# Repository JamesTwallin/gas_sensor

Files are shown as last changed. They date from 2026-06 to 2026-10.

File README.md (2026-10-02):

# Atmospheric methane detector

A pocket-sized gas detector you carry on a walk to find methane leaks.

- A small circuit board holds two gas sensors, one for methane and one for LP
  gas (propane and butane).
- The board sends its readings to an app on your phone over Bluetooth.
- The app shows you when the gas level suddenly rises, and saves the readings
  together with your GPS position.
- Afterwards, scripts in this repository turn a recording into a map.

This is a home-built, citizen-science project. It is not a certified safety
device. It shows *where* gas rises; it does not tell you how much gas there is.

<p align="center">
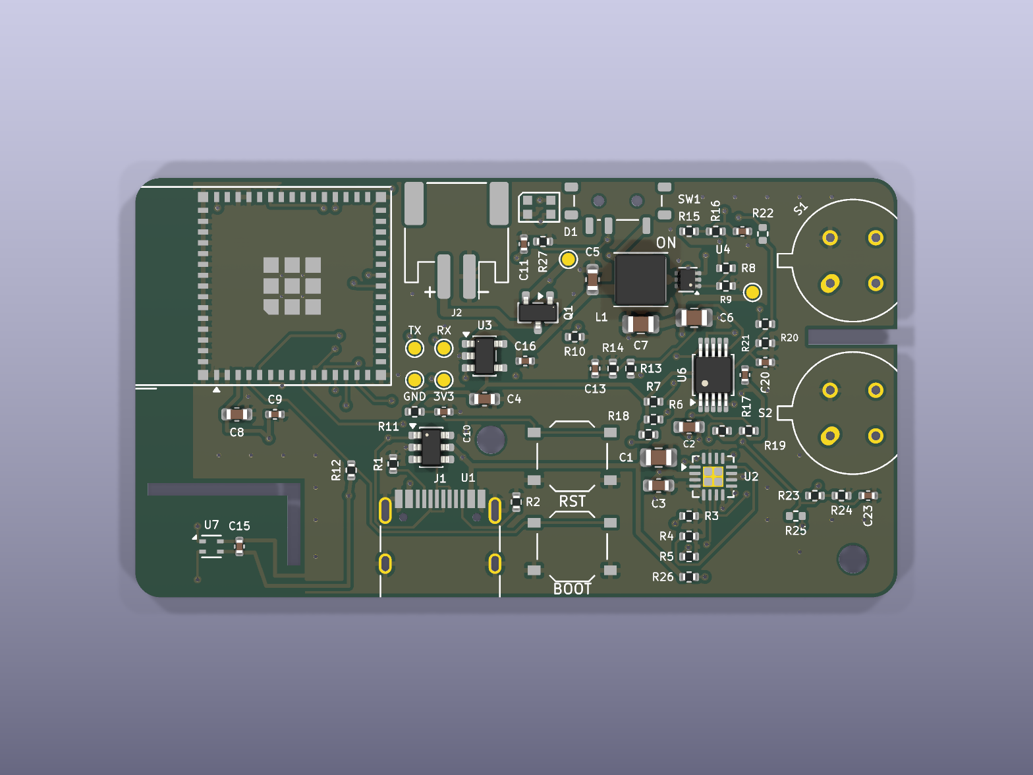
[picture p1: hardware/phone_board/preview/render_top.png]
Picture of the circuit board. The two round sensor positions are on the right-hand edge.
  
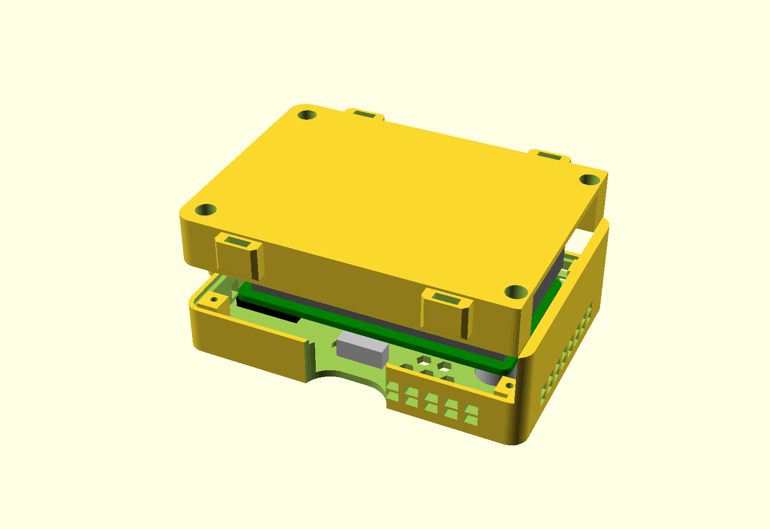
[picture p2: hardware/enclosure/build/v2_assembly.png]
Picture of the 3D-printed case with the board and battery inside.
  
</p>

## Which version to build

**Build rev C.** It is the current design.

| Version | What it is | Status |
|---|---|---|
| **Rev C** | The current board, 60 × 33 mm. Files are in [hardware/phone_board](hardware/phone_board/). | **Build this one.** This exact board has not been manufactured yet. |
| Rev B | The same circuit on a slightly bigger board (66 × 36 mm). | Built and tested in September 2026. Replaced by rev C. Its files are saved under the git tag [`rev-b`](https://github.com/JamesTwallin/gas_sensor/tree/rev-b/hardware/phone_board). |
| Rev D | An experiment with cheaper sensors. In [hardware/phone_board_mems](hardware/phone_board_mems/). | A draft. Nothing has been built. |
| Rev A | The first prototype, which had its own screen, GPS and memory card. In [legacy/rev_a](legacy/rev_a/). | Retired. |

Rev C and rev B are the same circuit. Rev C is just smaller, with the parts
moved around. So the software and the app work on both, and the tests done on
rev B still count. Running from the battery has not been properly tested yet.

## What you need

| Item | Where to get it | Notes |
|---|---|---|
| The circuit board | Order from [JLCPCB](https://jlcpcb.com/) using the files in [hardware/phone_board/production](hardware/phone_board/production/). | It arrives with almost every part already soldered on. The [board guide](hardware/phone_board/README.md) lists which options to pick when ordering. |
| Methane sensor: Figaro **TGS2611-E00** | [RS Components, stock no. 134-6647](https://uk.rs-online.com/web/p/environmental-sensor-ics/1346647) | You solder this on yourself. It has four legs. |
| LP-gas sensor: Figaro **TGS2610-D00** | RS Components, stock no. 134-6641 (search for it on your country's RS site) | You solder this on yourself too. |
| Battery | [The Pi Hut: 2000mAh 3.7V LiPo Battery, JST-PH connector](https://thepihut.com/products/2000mah-3-7v-lipo-battery), about £10 | **Check the red and black wires before plugging it in**, see below. Any single-cell 3.7 V LiPo battery works if it has a JST-PH plug and built-in protection. |
| USB-C cable | Any | For charging the battery and loading the software. |
| Android phone | | For the app. An iPhone works only if you build the app yourself. |
| Case (optional) | 3D-print it from [hardware/enclosure](hardware/enclosure/) | Also needs four M2 × 8 mm and two M2 × 5 mm self-tapping screws. The case fits the rev B board; one for rev C has not been made yet. |

The two sensors together cost roughly $25–30. Not every electronics shop stocks
them, so use the part names above when searching.

**Battery wires.** Batteries with the same plug are not all wired the same way
round. The battery from The Pi Hut came with red and black swapped compared to
what this board expects, and the two metal pins had to be swapped over in the
plug. A battery plugged in the wrong way round does no damage, but the board
will not switch on. The [board guide](hardware/phone_board/README.md#before-you-power-it)
shows which side is positive.

## Putting it together

1. **Order the board** from JLCPCB.
2. **Solder on the two sensors.** Line up the small tab on each sensor with the
   notch printed on the board.
3. **Load the software onto the board.** Install
   [PlatformIO](https://platformio.org/), plug the board into your computer with
   the USB-C cable, switch the board on, and run these from this folder:

   ```
   pio run -d firmware/phone_board                    # build
   pio run -d firmware/phone_board --target upload    # load it onto the board
   ```

   If your computer cannot find the board: hold the **BOOT** button, tap
   **RESET**, let go of **BOOT**, and try again.
4. **Install the app.** On an Android phone, scan this code, or open the
   [direct link](https://expo.dev/artifacts/eas/GfUwoBCFfugQeaA97EXnztzByZKVXR2_-AvwwxxLo4k.apk)
   on the phone. Your phone will ask for permission to install it.

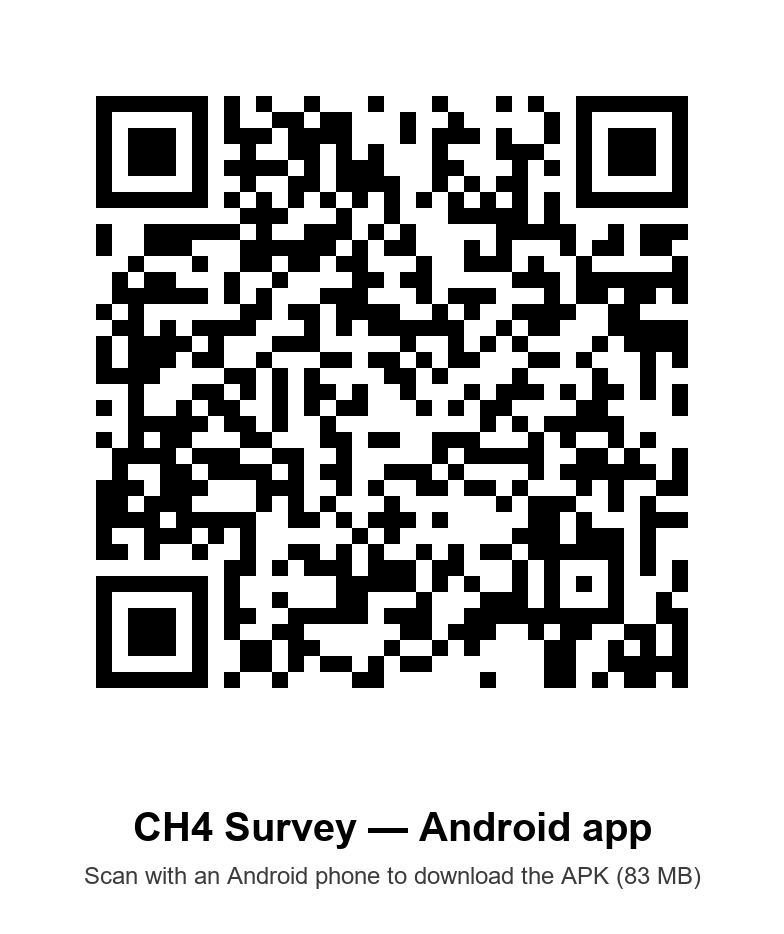
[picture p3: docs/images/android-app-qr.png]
QR code that downloads the Android app
   

   This is the version built on 2 October 2026. The download is stored by Expo
   and will be removed after a while. If the code has stopped working, or you
   have an iPhone, build the app yourself: see the [app guide](app/README.md).
   The app has a pretend sensor built in, so you can try it before you have a
   board.
5. **Plug in the battery**, after checking the wires (above). Plugging in the
   USB-C cable charges it.
6. **Go for a walk.** Switch the board on, open the app, tap **Connect**, pick
   your board from the list, and tap **Record**.

A quick way to check it works: let a little gas out of an unlit cigarette
lighter near the sensors, for a second or two only. The LP-gas reading should
jump. The methane reading will not, because that sensor has a filter that blocks
lighter gas.

## How it finds gas

The sensors do not give a steady number. Their readings drift up and down with
the temperature, the humidity and the wind, even in clean air. So the app does
not look at how high the reading is. It looks at how fast the reading is
*changing*. Walking into a patch of gas makes the reading shoot up within a
second or two, and the app flags that moment.

For the same reason, the gas concentration the app shows (in parts per million)
is only a rough guide.

More detail, for those who want it:

- [docs/phone_board.md](docs/phone_board.md): how the board is designed and
  how it talks to the phone.
- [docs/sensors.md](docs/sensors.md): how the sensors behave, and what can
  fool them.
- [app/README.md](app/README.md): the app.

## Making a map from a recording

The app saves each walk as a spreadsheet-style file (a CSV). Share it from the
app's **Surveys** tab to your computer and put it in the `tools/data/` folder.
Then, with [Python](https://www.python.org/) installed:

```
pip install -r tools/requirements.txt   # once
python tools/plot_map.py                # makes a map for every recording
python tools/plot_survey.py             # makes a video for every recording
```

- [plot_map.py](tools/plot_map.py) draws your route on a satellite photo,
  coloured by the sensor reading. The maps appear in `tools/maps/`.
- [plot_survey.py](tools/plot_survey.py) makes a video of the readings over
  time. The videos appear in `tools/videos/`.

Recordings contain your GPS positions, so `tools/data/` is never uploaded to
GitHub.

## What is in this repository

```
app/              the phone app
firmware/         the software that runs on the board
hardware/
  phone_board/        the rev C board: design files and the files to order it
  phone_board_mems/   the rev D draft
  enclosure/          the 3D-printed case
docs/             how the board and the sensors work
tools/            scripts that turn recordings into maps and videos
legacy/           old versions, kept for reference
```

## Licence

Firmware is MIT (see [LICENSE](LICENSE)). The hardware design will be released
under CERN-OHL-S once it is ready.

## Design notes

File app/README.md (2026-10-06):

# GasSnifferBuddy — companion app

Phone app for the methane detector's phone-companion board, rev B and rev C
([docs/phone_board.md](../docs/phone_board.md)).
The board streams raw samples over BLE; the app turns them into the one thing
that indicates a plume — the slope of each channel's load voltage, with a spike
detector on top — charts it, and adds GPS tagging and CSV recording. Rev A's
HIGH/MED/LOW classifier and its baseline are gone from the screen: the absolute
level wanders too much to mean anything. The rolling baseline is still computed
for the rev A CSV columns only, so the plotting tools keep working.

One codebase: **Expo (SDK 57) + React Native + TypeScript**, built with EAS.

```
app/
  App.tsx          top bar, banners, the three views, action dock
  index.ts         Expo entry point
  app.json         Expo config: permissions, BLE + location plugins
  eas.json         EAS Build profiles (development / preview / production)
  src/core/        pure, DOM-free, unit-tested
    protocol.ts    BLE UUIDs, 20-byte Sample parser, Info JSON, control opcodes
    base64.ts      base64 <-> bytes (react-native-ble-plx speaks base64)
    sensor.ts      VRL = tap × tap_ratio, Rs = RL (VC − VRL) / VRL
    windows.ts     time-based rolling window, rev A percentile
    spike.ts       slope (dVRL/dt) and the adaptive spike threshold
    processor.ts   WARMUP / RUNNING / HEATER_OFF state machine, CSV baseline, LED colour
    csv.ts         exact spec column order, row formatting, file names
    chartData.ts   chart history + peak-per-column decimation
    simulator.ts   simulated board producing protocol-exact packets
    beep.ts        the alarm tone (synthesised WAV)
    settings.ts    defaults (3 min warm-up, 1 s slope window, 25 mV/s spike threshold, beep on)
    mapView.ts     map maths: Web Mercator, which tiles to show, fit-to-track (unit-tested)
    track.ts       the survey track: one point per GPS fix with its readings (unit-tested)
    heatmap.ts     ground cells, colour scale and range for the map (unit-tested)
    surveyCsv.ts   reads a saved survey CSV back into a map track (unit-tested)
  src/controller.ts  the wiring: BLE/simulator -> core -> UI state, GPS, recording
                     (deliberately not src/app/ — Expo treats that as the
                      Expo Router routes directory)
  src/services/    BLE scan + link (auto-reconnect), simulated link, GPS,
                   recorder, keep-awake, spike beeper (expo-audio), settings storage
  src/ui/
    chartPaths.ts  pure chart geometry (unit-tested)
    charts.tsx     react-native-svg rendering of that geometry
    SurveyMap.tsx  the live survey map: satellite tiles + the heatmap
    *Screen.tsx    Live / Surveys / Settings, and Present (full-screen slopes for video)
  tests/           vitest — core + chart geometry
```

Samples arrive at 4 Hz, so `AppController` is a plain class holding the mutable
engines (`Processor`, `ChartBuffer`, `Recorder`); React subscribes to it with
`useSyncExternalStore` and sees an immutable snapshot published at most once per
animation frame.

## Requirements

- **Node 22.13+** (or 20.19.4+ / 24.3+). React Native 0.86 and Metro 0.84 refuse
  anything older — Node 22.11 installs with an `EBADENGINE` warning and then
  fails to start the bundler. EAS Build uses its own Node, so this only affects
  running the dev server locally.
- Android Studio + SDK for `expo run:android` (a Mac + Xcode for `run:ios`)
- **pnpm** — install dependencies with `pnpm install`, not `npm install`.
  `npm install` stalls indefinitely on this dependency tree on Windows: it
  creates the ~320 top-level directories in `node_modules/`, writes zero bytes
  and then sits there with the CPU idle. pnpm installs the same tree in about
  20 seconds. `.npmrc` pins `node-linker=hoisted`, which Metro and the Expo
  config plugins need — they resolve modules by walking `node_modules`, so the
  default symlinked pnpm layout breaks them.
- Optional, only for cloud builds: an [Expo](https://expo.dev) account and
  `npm i -g eas-cli`.

## First-time setup

```sh
cd app
pnpm install
```

## Running it

BLE needs native code, so **Expo Go will not work with a real board** — the app
has to be a native build. The simulator, however, runs anywhere.

```sh
npx expo run:android    # builds the native app, installs it, starts Metro
npx expo start          # afterwards: just the bundler
```

`run:android` runs `prebuild` for you, generating `android/` from `app.json`.
Re-run it when a native dependency or anything in `app.json` changes; the rest of
the time `expo start` is enough. `npx expo prebuild --clean` regenerates the
native projects from scratch if they get into a bad state.

### Without hardware

**Settings → Simulated device**, then Connect. The simulator has buttons to drop
the link (tests auto-reconnect), toggle USB and force the heaters off.
Because it touches no native BLE code it also runs in Expo Go (`npm run start:go`),
which is the quickest way to work on the UI.

### Cloud builds (optional)

If you would rather not build locally — or need an iOS build without a Mac —
`eas.json` has development / preview / production profiles:

```sh
eas login
eas init                      # links this folder to your Expo account
npm run build:dev:android     # eas build --profile development --platform android
```

`eas init` writes `extra.eas.projectId` into `app.json`; commit that change.

`android/` and `ios/` are generated, not tracked: `app.json` is the source of
truth and EAS runs `prebuild` itself.

## Tests and type-checking

```sh
pnpm test         # vitest: src/core + src/ui/chartPaths — 152 tests
pnpm typecheck
```

The tests import only pure modules, so they run in plain node with no React
Native or Expo mocking.

## Permissions

Declared in `app.json` and requested at first Connect / Record:

- **Android** — `BLUETOOTH_SCAN` (`neverForLocation`) and `BLUETOOTH_CONNECT` on
  API 31+, legacy `BLUETOOTH`/`BLUETOOTH_ADMIN` below that, `ACCESS_FINE_LOCATION`
  / `ACCESS_COARSE_LOCATION` for the GPS track (foreground only), and `WAKE_LOCK`.
  The BLE plugin is listed before `expo-location` so scanning does not force a
  location grant, while the location permission itself stays uncapped for the
  GPS track.
- **iOS** — `NSBluetoothAlwaysUsageDescription` (from the BLE plugin),
  `NSBluetoothPeripheralUsageDescription` and `NSLocationWhenInUseUsageDescription`.

There is no OS device chooser: the app scans for boards advertising the service
UUID and shows its own picker.

## Using it in the field

1. Power the board, tap **Connect**, pick `CH4-XXXX` from the list.
2. The big card reads **WARMING UP** for the first 3 minutes after the board
   powers on (skipped if it has been on longer), then shows the **CH4 slope** in
   mV/s and turns red while the slope is over the spike threshold: a rising
   edge means you have just walked into a plume. The phone sounds an alarm
   tone on every flagged sample (Settings → Beep on spikes). No spikes are flagged during warm-up, though the charts run. Each
   channel's card charts the slope over the last 60 s, the raw VRL under it,
   and the peak slope over the last 10 min. Raw readings are charted and
   recorded in every state. The board LED follows (green, red while CH4 is
   spiking).
3. Tap **● Record** to start a survey. Rows are appended to storage every 3 s.
   The **Surveys** tab draws your route as a heatmap on a satellite map as
   you walk, like `tools/plot_map.py` does afterwards. The route is split into
   5 m squares (bigger when zoomed out), each coloured on one gradient from
   dark purple (low) to pale yellow (high), with a colour bar showing the range.
   **Raw** colours each square by the average CH4 VRL there; **Spikes** by the
   steepest CH4 rise there in mV/s, scaled from 0 to the top 1% of squares.
   Tap a square to read its value; tap again to close it. The map fits the
   whole route until you drag or pinch it; the GPS button centres on you and
   follows you as you walk. The top button opens the map full screen; it or
   the back gesture closes it.
   Fixes less accurate than 25 m are left off, so indoors the route may not
   appear. The map images come from Esri World Imagery and need a data connection.
   **Looking at an old survey:** tap **Show on map** on any saved survey in the
   list and the map redraws that survey instead. **Back to live map** returns to
   the current one. **Open a CSV…** loads a survey from somewhere else (Files,
   Google Drive, an email attachment, a colleague's phone): it is copied into
   your survey list and shown. Older SD-card CSVs from the rev A board load too,
   but they have no slope column, so only the **Raw** map shows anything for them.
4. Tap **Present** for presentation mode: just the two slopes, full screen and
   large, for filming or screen-recording. The ✕ (or Android back) leaves it.
5. A red **HEATERS OFF** banner means the firmware's low-battery cutoff tripped:
   readings are invalid until the heaters are back and the sensor has warmed up again.

## Getting CSVs into `tools/data/`

**Surveys** tab → **Share / export** on a file, then send it to your computer
(Drive, email, Nearby Share / AirDrop, …) and save it to `tools/data/`.

Surveys live in `<documents>/surveys/`. On iOS that folder is exposed to the
Files app (**On My iPhone → GasSnifferBuddy → surveys**) via `UIFileSharingEnabled`.
On Android (debug build) you can also pull them over USB:

```sh
adb shell run-as com.inorite.sensorbuddy ls files/surveys
adb exec-out run-as com.inorite.sensorbuddy cat files/surveys/2026-09-17_09-05-07.csv > tools/data/2026-09-17_09-05-07.csv
```

The CSV is the rev A column set followed by `ch4_rs_ohm,lpg_rs_ohm,vbat_mv,gps_accuracy_m`
(see the spec). Note the known gap in the spec: `tools/plot_map.py` currently
filters on `sats`, which the phone leaves blank.

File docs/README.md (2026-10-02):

# docs

Project documentation that does not belong in code:

- [phone_board.md](phone_board.md) — the design spec for the current board
  (rev B / C): why each part is there, power, the gas sensor circuit, the pin
  map, the Bluetooth protocol and the CSV the app writes. This is the source of
  truth for the schematic generator, the firmware and the app.
- [sensors.md](sensors.md) — Figaro TGS2611 / TGS2610 behaviour notes: why
  absolute ppm is only indicative, the humidity confounder, warm-up, field
  cautions.

Elsewhere:

- [../hardware/phone_board/README.md](../hardware/phone_board/README.md) —
  building the rev C board: the generator scripts, ordering, first power-up.
- [../hardware/enclosure/README.md](../hardware/enclosure/README.md) — the
  printed case.
- [../app/README.md](../app/README.md) — the phone app.
- [../legacy/rev_a/schematic.md](../legacy/rev_a/schematic.md) — the connection
  spec for the retired rev A carrier board.

The hardware design will be released under CERN-OHL-S when it is ready; the
firmware is MIT (see the top-level LICENSE).

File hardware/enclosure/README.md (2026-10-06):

# Handheld enclosure

A two-part printed case for the [phone-companion board](../phone_board/): a
front shell the board screws into, and a back tray that holds the battery.

**Which board it fits.** `case_revb_v2.scad` is sized for the 66 × 36 mm rev B
board, the one that has been built. A case for the 60 × 33 mm rev C board has
not been made yet: the board dimensions and part positions are parameters at
the top of the file (see [If you change the board](#if-you-change-the-board)),
and rev C's positions are already measured out in the older
[legacy/enclosure/case_revc.scad](../../legacy/enclosure/case_revc.scad). The
earlier box-and-lid cases are in [legacy/enclosure](../../legacy/enclosure/).

## The design

The board screws into a **front
shell** with the sensors through its face, and a **back tray** carries the
battery in its own pocket and traps it when screwed on.

v2

- **Case is 81 × 57 mm** (was 51 wide). The cell has to pass between the two
  corner posts at the tray's open end on its way into the compartment, and at
  51 mm wide the gap between them was 36 mm for a 38 mm cell. Now 41.6 mm.
- **Front shell** (81 × 57 × 11.4 mm). Sensor collars and cap holes in the
  face, hex grille around them and at the SHT40 end, RST/BOOT pen holes, LED
  window, engraved lettering. Inside, two 7 mm bosses at the board's H1 and H2
  holes: the board goes in component side first and two M2 × 5 screws through
  the board's back pull it onto them. USB-C and the switch sit in notches open
  to the shell's back edge, so both are reachable with the tray off; the tray's
  rim closes them. Louvres at component level on three sides of the sensor end.
  Four corner posts with pilot holes take the tray screws.
- **Back tray** (78.6 × 57 × 11.8 mm plus a 1 mm lip). A closed compartment
  for the Pi Hut 2000 mAh cell, 60 × 38 × 8 mm: floor, side fences, an end
  fence at the SHT40 end and a 1.2 mm divider plate over the top that keeps the
  cell separate from the board. The compartment is open at the sensor end, a
  full-width slot the cell slides into like a drawer; the divider stops 8 mm
  short of that end so the lead can come up through the gap to the board's
  JST. The front shell's sensor-end wall carries a skirt that reaches down over
  the open end, so with the tray screwed on the slot is closed and the cell is
  captive. Four counterbored corner posts, lip into the shell's rebate on the
  other three sides, zip-tie eyelets on the long walls (the tie passes through them front to
  back). No vents in the
  battery compartment.
- **Orientation**: the board lies component side down in the shell. It goes in
  as if turned over about its long axis, so the sensor end stays at the
  lanyard-free end, the switch is on one long edge and USB-C on the other. Seen
  from the front, the two collars are on the left with CH4 the lower one, the
  switch scallop on the bottom edge, and the SHT40 grille top right.
- **Access with the tray on**: matching 20 mm wide, 5 mm deep scallops cut
  through the face and wall at both the switch and the USB-C socket, on top of
  the side notches (14 × 7.4 mm at the USB-C, 15 × 8 mm at the switch), so a
  thumb reaches the lever and a plug goes in from the front edge.
- **Screws**: 4 × M2 × 8 for the tray, 2 × M2 × 5 for the board. The tray's
  counterbores are 9.3 mm deep, leaving 2.5 mm of plastic under each head, so
  an M2 × 8 puts 5.5 mm of thread into the shell's posts (pilots are 7 mm
  deep). A PH0 or PH00 driver reaches the head down the 4.6 mm bore. The tray
  screws pass through the divider plate at the SHT40-end corners.
- **Second print revision (2026-10-01)**: every corner post is now embedded in a
  solid 5.2 mm block joined to the adjacent walls, in both parts. The first
  print's two tray posts at the open end stood alone on the floor and snapped
  off. The battery compartment has 0.6 mm of play around the cell and 1 mm over
  it (was 0.3 and 0.5, too tight printed). The cell stops 0.6 mm short of the
  corner blocks at the open end, which reach 1.8 mm into its width, so the
  block zone is 5.2 mm of room for the lead, which passes between the two
  blocks. Face lettering: CH4, RST, USB by the port scallop, ON / OFF either
  side of the switch scallop (ON is lever toward the sensor end). The BOOT
  button's pen hole is there but unlabelled.
- **Print**: front face down (collars and lettering on the plate), tray outer
  face down. No supports: the divider is a 39 mm bridge between the side
  fences, which PETG on the A1 handles. Files `stl/revb_v2_front.stl`,
  `stl/revb_v2_back.stl`. Overall assembled depth 22.7 mm.
- **Assembly**: fit the sensors' end of the board under the collars and screw
  the board to the bosses. Slide the cell into the tray's open end, lead first
  is easiest, until it meets the end fence. Bring the lead up through the gap
  at the end of the divider, past the end of the board, and plug it into the
  JST. Screw the tray on: the shell's skirt now covers the open end.
- `-D 'part="section"'` cuts the assembled case in half lengthways for a
  clearance check.

## Files

| File | What |
|---|---|
| `case_revb_v2.scad` | the model, parametric: edit this, not the STLs |
| `stl/revb_v2_front.stl` | front shell |
| `stl/revb_v2_back.stl` | back tray |
| `build/v2_assembly.png` | the render above |

Regenerate after editing (OpenSCAD 2021.01+):

```
openscad -o stl/revb_v2_front.stl -D 'part="front"' case_revb_v2.scad
openscad -o stl/revb_v2_back.stl  -D 'part="back"'  case_revb_v2.scad
openscad -o build/v2_assembly.png --imgsize=1600,1100 -D 'part="assembly"' case_revb_v2.scad
```

`part="assembly"` also draws a mock board, sensors and cell, which is the
quickest way to check a change hasn't broken clearances.

## Printing

- **Material: PETG or ASA.** The heaters put ~0.6 W inside a small box and the
  case sits in sunlight on surveys; PLA creeps and can sag. PETG is the easy pick.
- **0.2 mm layers, 3 walls, 20 % infill.** No supports, no brim needed.
- **Orientation:** front shell face down, back tray outer face down.

## Hardware you need

| Qty | Item |
|---|---|
| 4 | M2 × 8 mm self-tapping screws (tray into the shell's corner posts) |
| 2 | M2 × 5 mm self-tapping screws (board to the bosses at H1 and H2) |
| 1 | 1S LiPo, JST-PH, protected: the compartment is sized for the Pi Hut 2000 mAh cell, 60 × 38 × 8 mm (see the [board README](../phone_board/README.md) for polarity) |

## Known compromises

- **Not weatherproof.** The sensors need open air, so the shell is vented.
- **The sensor cans get hot** (~280 mW each). They protrude by design; don't grip
  them, and give the device a minute of settling after handling before trusting
  a reading.
- **SHT40 accuracy:** the tongue on the board and the grille at that end help, but
  temperature inside any case reads slightly high. Compare against a reference
  thermometer before trusting absolute temperature.

## If you change the board

`case_revb_v2.scad` carries the board dimensions and part positions at the top
(all in KiCad board coordinates, origin at the board's top-left corner). Update
them there and re-export. Set `board_t = 1.0` if you order 1 mm boards.

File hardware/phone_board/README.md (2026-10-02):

# Phone-companion board (rev C)

A 60 × 33 mm, 4-layer board: bare ESP32-S3-MINI-1, two bare Figaro TGS sensors,
ADS1115, SHT40 temp/humidity, LiPo charging and a 5 V heater boost. Position, display,
storage and signal processing live on the phone. The electrical spec (why each
part, pin map, BLE protocol) is [docs/phone_board.md](../../docs/phone_board.md).

top

**Status: rev C is the current design, and the one to build.** It is rev B
compacted, with the same schematic and parts; this layout has not been
fabricated yet. Rev B (66 × 36 mm, git tag `rev-b`) was fabricated and assembled
at JLCPCB and passed bring-up on 2026-09-28: it enumerates over native USB,
flashes, and `firmware/phone_board` reports the ADS1115, the SHT40, a 5.02 V
heater rail and both Figaro sensors on USB power. The Bluetooth link to the
phone app was confirmed on the same board. Battery operation is not yet
exercised.

Rev C keeps rev B's schematic and parts, shrinks the board from 66 × 36 to
60 × 33 mm (17 % less area) and gives it a business end:

- **Front (right) edge: the sensors.** Both Figaro cans overhang the edge by
  about 1 mm and a 7 mm notch is milled between them, so each can stands in air
  on three sides and the two heaters share less board.
- **Rear: the power connections, beside the ESP32.** USB-C on the bottom edge
  and the battery JST-PH on the top edge, both right next to the module and
  about 30 mm from the heaters; the reverse-cell FET sits by the JST.
- **SHT40 isolation.** The tongue keeps its L-slot with a 2.5 mm neck, and no
  copper pour is allowed on any of the four layers over the tongue or neck:
  only its four tracks cross, since copper is what carries board heat.
- The hand-routed boost loop and ESP32 decoupling were moved as rigid units;
  everything else was re-placed (charger and ADC in the middle, RESET above
  BOOT, serial test pads as a labelled 2 × 2 grid).

The KiCad checks report 0 DRC violations, 0 unconnected items and 0
schematic/PCB mismatches; ERC is clean.

**USB-only power is marginal at heater turn-on.** With no cell on J2, the
BQ24073's 500 mA USB input limit only just covers the boost converter starting
into two cold heaters: an early firmware that enabled the heaters 3 s after
boot, with BLE advertising and the CPU at 240 MHz, browned out the ESP32 at
that instant on two consecutive boots. The firmware now enables the heaters as
the very first thing in `setup()` at 80 MHz, before any other load, and a cold
start then survives. A LiPo on J2 removes the margin problem, since the cell
holds VSYS up through the inrush. If a future revision is made, raise the
charger's input limit (ILIM mode) or add bulk capacitance on VSYS.

## The design is generated — edit `gen/design.py`, not the KiCad files

`gen/design.py` holds every part, net, LCSC number, placement, pre-routed
track and rule. The scripts turn it into the KiCad project:

| Step | Command | Output |
|---|---|---|
| custom symbols | `python gen/build_lib.py` | `lib/phone_board.kicad_sym` (TPS61023, TGS26xx) |
| schematic | `python gen/build_sch.py` | `phone_board.kicad_sch` (net-label style) |
| board (placed, unrouted) | `"C:\Program Files\KiCad\9.0\bin\python.exe" gen/build_pcb.py` | `phone_board.kicad_pcb`, `.kicad_pro` rules |
| autoroute | `...\python.exe gen/route.py` | routed board, GND pours + stitching vias |
| tidy silkscreen labels | `...\python.exe gen/tidy_silk.py` | moves/hides overlapping reference designators on the routed board |
| JLC placement | `...\python.exe gen/jlc_align.py` (needs `pip install easyeda2kicad`) | `gen/jlc_placement.json` |
| fab files + renders | `python gen/export.py` | `production/`, `preview/` |
| relabel silkscreen only | `...\python.exe gen/build_pcb.py --silk-only` | edits the routed board in place |

Then check: `kicad-cli pcb drc --schematic-parity phone_board.kicad_pcb` and
`kicad-cli sch erc phone_board.kicad_sch`.

**Rebuilding the board throws away the routing.** `build_pcb.py` then needs a
fresh `route.py` run of about 5 minutes. Freerouting doesn't route exactly the
same way twice, so re-run DRC afterwards.

`route.py` needs Freerouting 2.4+ and Java 25+ (a portable JRE is fine):

```
set JAVA=C:\path\to\jdk-25-jre\bin\java.exe
set FREEROUTING=C:\path\to\freerouting-2.4.1.jar
```

How routing works:

- **The boost converter's power loop is routed by hand.** This covers the
  inductor to SW, the output caps, the feedback sense point and the GND vias,
  and it lives in `PREROUTE`. The tracks are locked, so Freerouting routes
  around them.
- **In1 is a solid GND plane.** The script marks it as a power layer, so no
  signals are routed on it.
- **F.Cu, In2 and B.Cu carry signals**, then get GND pours.
- **The script runs Freerouting up to 3 rounds**, then adds GND stitching vias
  and a via for any pour island that has none.

You can also open `phone_board.kicad_pro` in KiCad and edit by hand. Just
don't regenerate over those edits.

## Ordering from JLCPCB

1. **PCB:** upload `production/gerbers.zip`. Choose 4 layers, 1.6 mm, and the
   JLC04161H-7628 stackup (or any).
   - **Minimums used:** 0.2 mm track/clearance (0.15 mm at the SOT-563), 0.3 mm
     vias, and 0.2 mm drill for the via-in-pad GND vias under the ESP32 and the
     charger.
   - **Via-in-pad:** choose "Epoxy filled & capped" if the price is acceptable;
     otherwise untented plain vias will do for a prototype.
2. **Assembly:** choose the top side, then upload `production/bom.csv` and
   `production/cpl.csv`.
   - **The CPL is already corrected for JLC's library.** `gen/jlc_align.py`
     downloads LCSC's footprint for every assembled part and pad-matches it
     against the board to get JLC's origin and rotation. That found a 2.55 mm
     origin shift on the ESP32, 1.5 mm on the USB-C, and 90°/180°/270°
     rotation differences on U1, U3, U4, U6 and U7. Still look over the
     preview, especially the pin-1 dots on the ICs.
   - **Extended parts:** most ICs are "extended", so expect a per-part loading
     fee.
3. **Solder these yourself:**
   - **Figaro TGS2611-E00 (S1, CH4) and TGS2610-D00 (S2, LPG).** Neither is
     stocked at LCSC. RS Components lists both (stock numbers 134-6647 and
     134-6641). They are through-hole, so line the tab up with the silkscreen
     notch.
   - **Figaro recommends a long burn-in before the readings settle**: 7 days
     (TGS2611) / 4–7 days (TGS2610) with the heater on.

## Before you power it

- **Battery polarity.** J2 (JST-PH) is wired pin 1 = −, pin 2 = +. On the
  fabricated rev B boards that puts **positive (red) on the pin nearer the
  sensor end** of the board. The Pi Hut "2000mAh 3.7V LiPo Battery - JST-PH
  Connector" arrived the other way round and needed its two crimps swapped in
  the plug (2026-09-30); check any cell against this before plugging in. Q1
  blocks a reversed cell (nothing gets damaged, it just won't power). Use a
  cell **with a built-in protection circuit**; the board has no deep-discharge
  cutoff. A future revision could replace Q1 with a four-MOSFET bridge to make
  the input polarity-agnostic.
- **The power switch** (SW1) switches the regulator enables, not the battery.
  The battery still charges when it's off.
- **First bring-up:**
  1. Check +3V3 on TP4 with no sensors fitted. +5V_HTR (TP6) stays at 0 V until
     firmware drives GPIO7 high; heaters are firmware-controlled.
  2. Flash `firmware/phone_board` over USB-C. If it doesn't enumerate, hold
     BOOT and tap RESET.
- **3D models:** the renders show no models for the ESP32 module, USB-C, the
  switches or the sensors, because KiCad doesn't ship them. This is cosmetic.

## Cutting the cost

Rev C's smaller outline barely moves the JLCPCB price at 5 pieces (the 4-layer
bare-board price is close to flat below 100 × 100 mm). The levers that do
matter, biggest first:

- **Extended-part loading fees.** JLC charges a loading fee per Extended part
  type on top of the part price. The ESP32 module, BQ24073, TPS61023, ADS1115,
  SHT40, WS2812B-2020, the MSK12C02 slide switch and the JST-PH are all
  Extended; check the rest against the JLC library and swap any Extended
  resistor/capacitor value for a Basic neighbour (the 732 kΩ feedback resistor
  is the likely one; a 750 kΩ Basic part shifts the heater rail by ~2 %).
- **Two layers instead of four.** The bare board then costs roughly a third
  as much at low quantity. Electrically feasible (USB full-speed, I2C and a 1 MHz boost
  are the fastest things here) but it is a full re-route with the bottom
  side as ground, not a tweak of this layout.
- **Cheaper silicon.** ADS1015 is pin- and register-compatible with ADS1115 at
  12 bits instead of 16 and about half the price; the firmware's gain and
  scaling would need checking. SHT30 is cheaper than SHT40 but has a different
  footprint and driver.
- **Skip via-in-pad filling.** Plain vias under the ESP32 and charger are fine
  for prototypes and avoid the filled-and-capped surcharge.
- **Quantity.** The setup, stencil and loading fees are per order, so 10 boards
  cost little more than 5.

## Known limitations of rev B and rev C

- **Charger:** BQ24073 (no SYSOFF pin). In the off position < 10 µA still flow
  from the battery.
- **Charge current** is fixed at ~500 mA, and input current is limited to USB500.
- **Heater warmth:** the SHT40 sits on a slotted tongue away from the heaters,
  but the board as a whole will still warm up. Compare against a reference
  thermometer before trusting `temp_c`.
- **Schematic layout:** the generated schematic uses net labels, not drawn
  wires. Connectivity is exact, but it's less readable than a hand-drawn one.
- **ESP32 ADC fallback:** R22/R25 are not fitted. Hand-fit 1 kΩ 0402 parts only if the
  ADS1115 needs bypassing.

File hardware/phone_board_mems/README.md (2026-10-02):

# Phone-companion board, MEMS sensors (rev D draft)

A 55 × 31 mm, 4-layer board: the rev C phone-companion board with its two
Figaro TO-5 cans replaced by **Winsen GM-402B MEMS sensors** and the 5 V heater
boost replaced by a **2.8 V LDO**. Everything else is the rev C circuit: bare
ESP32-S3-MINI-1, BQ24073 charger, USB-C, ADS1115, SHT40 on a slotted tongue.
The electrical spec is [docs/phone_board.md](../../docs/phone_board.md); the
rev C board it descends from is [hardware/phone_board](../phone_board/).

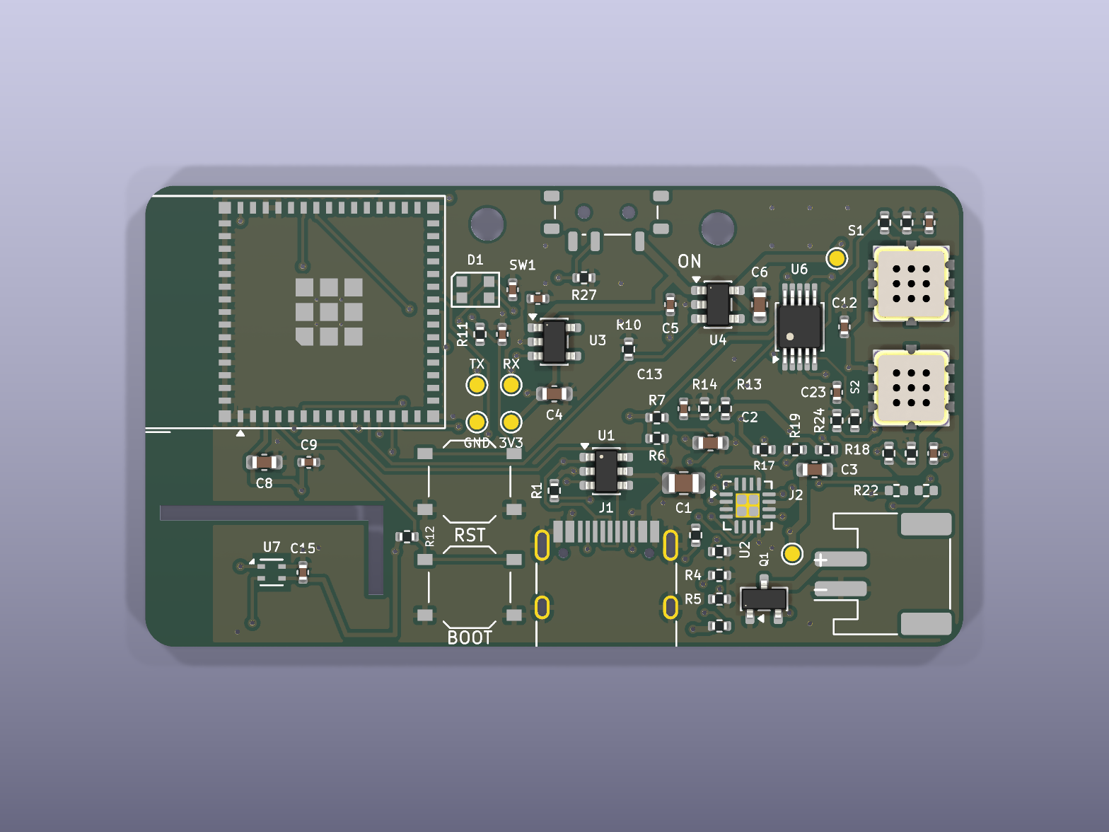
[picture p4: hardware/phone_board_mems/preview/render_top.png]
top


**Status: draft, generated and checked, not ordered.** DRC, connectivity,
schematic parity and ERC are clean. Nothing has been built, and the GM-402B
has not been characterised on the bench: treat the load resistor value and the
firmware constants below as starting points.

## Why

| | rev C (Figaro TGS2611 + TGS2610) | rev D (2 × GM-402B) |
|---|---|---|
| Sensor cost | ~$25–30 for the pair, hand-soldered | ~$5–8 for the pair, JLC-placed |
| Heater | 5 V, ~56 mA each, 0.56 W total, boost converter + inductor | 2.8 V, ~35 mA each, 0.2 W total, one SOT-23-5 LDO |
| USB-only operation | marginal at heater turn-on (500 mA USB limit) | comfortable |
| Battery life | heaters are most of the load | roughly double |
| Board | 60 × 33 mm | 55 × 31 mm |
| Selectivity | two different sensors (CH4 vs LPG) | two identical sensors (see below) |
| Track record | proven on the rev B build | none yet |

## What changed from rev C

- **Sensors.** GM-402B, LCSC C99754, Extended part, SMD-8 5 × 5 mm. Pads 1/3
  are the heater (2.8 V ± 0.1 V across ~80 Ω, ≤ 80 mW), pads 5/7 the sensing
  electrode, the rest no-connect. The footprint and 3D model come from LCSC via
  easyeda2kicad (`lib/phone_board_mems.pretty`, `lib/phone_board_mems.3dshapes`).
- **Heater rail.** `+2V8_HTR` from a Microne ME6211C28M5G-N (LCSC C53099,
  SOT-23-5, enable pin). Enable is `HTR_EN` with the same 100 k pull-down, so
  the firmware's heater switching, low-battery cutoff and fail-safe are
  unchanged. TP6 is on this rail.
- **Electrode loop.** The sensing side runs from +3V3 through the element into
  a 10 k + 10 k load (RL = 20 k, tap = VRL/2 ≤ 1.65 V). Same topology as rev C
  with VC = 3.3 V instead of 5 V and RL halved. The GM-402B is 1–30 kΩ in
  5000 ppm CH4 and at least 2 × that in clean air; 20 k is a middle-of-range
  choice to be tuned once a real part has been measured.
- **Heater monitor.** R15/R16 divide `+2V8_HTR` to 1.4 V at the ADS1115 (was 2.5 V).
- **Gone.** TPS61023, the 1 µH inductor, its 22 µF output caps and feedback
  divider, the hand-routed boost loop, the sensor silkscreen circles.
- **Layout.** MCU column and SHT40 tongue as rev C (tongue shortened for the
  31 mm board, its neck re-routed by hand); USB/charger column moved up 2 mm
  into the room the boost left; ADC where the inductor was; sensors as a
  right-hand column rotated so their electrode pads face the ADC; JST-PH under
  them leaving through the right edge. Both mounting holes are on the top edge
  (there is no room at the bottom-right any more): revisit before designing an
  enclosure.

## Two identical sensors

The rev B/C concept used two different Figaro parts (methane vs LP-gas) for
source discrimination. The GM-402B responds to both CH4 and C3H8, so rev D
fits **two of the same sensor**: channel 2 (still called `LPG` in the firmware,
app and CSV so nothing downstream breaks) becomes a second methane channel,
useful for redundancy and noise checks rather than discrimination. Winsen's
other GM-series parts (GM-502B VOC, GM-702B CO) share the package but not
necessarily the 2.8 V heater spec, so check before fitting one in S2.

## Firmware and app changes needed

None of this is done yet. In `firmware/phone_board/src/main.cpp`:

- `RL_OHM` 40000 → 20000, and `vc_mv` in the info JSON 5000 → 3300.
- `HEATER_MIN_MV`/`HEATER_MAX_MV` 4800/5200 → about 2700/2900; `heater_mv` is
  now the LDO output, and the ADS1115 tap reads 1.4 V nominal.
- `board` in the info JSON: `"rev-d-mems"`.
- The heaters-first-at-80 MHz boot ordering can stay, but it is no longer
  needed: the LDO's 70 mA is well inside the USB500 limit.
- Winsen quotes a burn-in before readings settle; keep the rolling-baseline
  approach, and expect the `rl_ohm`/`tap_ratio` scaling in the app to give
  different absolute `*_vout_mv` values than the Figaro boards.

## The design is generated — edit `gen/design.py`, not the KiCad files

Same toolchain as rev C, same commands, run from this directory:

| Step | Command |
|---|---|
| custom symbols | `python gen/build_lib.py` (GM-402B, ME6211C28) |
| schematic | `python gen/build_sch.py` |
| board (placed, unrouted) | `"C:\Program Files\KiCad\9.0\bin\python.exe" gen/build_pcb.py` |
| autoroute | `...\python.exe gen/route.py` (needs `JAVA` and `FREEROUTING`, see the rev C README) |
| tidy silkscreen | `...\python.exe gen/tidy_silk.py` |
| JLC placement | `...\python.exe gen/jlc_align.py` (needs `easyeda2kicad`) |
| fab files + renders | `python gen/export.py` |

Then `kicad-cli pcb drc --schematic-parity phone_board_mems.kicad_pcb` and
`kicad-cli sch erc phone_board_mems.kicad_sch`.

## Ordering

As for rev C (4 layers, top-side assembly, `production/gerbers.zip`,
`bom.csv`, `cpl.csv`), except that **nothing needs hand soldering**: the
GM-402B is placed by JLC. It is MSL 3, which JLC handles. The BOM has one fewer
Extended part than rev C (the boost is gone, the LDO and the sensor are both
Extended). The GM-402B has an open mesh cap: do not let the pick-and-place or
the enclosure press on it, and keep conformal coating off it.

## Known unknowns

- **GM-402B behaviour** on this circuit (RL, warm-up, humidity drift) is
  untested. The heater spec is from Winsen's product page; the manual PDF is
  image-only and could not be machine-read, so check the pinout against the
  printed manual before ordering.
- **ME6211 pinout** (1 VIN, 2 GND, 3 CE, 4 NC, 5 VOUT) is taken from LCSC's
  symbol, which matches the AP2112K order. Verify against the datasheet.
- **Enclosure.** `hardware/enclosure` fits the rev B board; nothing has been
  adapted for this outline.

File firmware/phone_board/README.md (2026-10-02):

# Phone-companion board firmware

Firmware for the rev B and rev C boards, which share one circuit
([hardware/phone_board](../../hardware/phone_board/)). It is a thin sampler:
it reads the two gas sensor taps, battery voltage and heater rail on the
ADS1115 and temperature/humidity on the SHT40, averages over the sample
interval (250 ms by default), and sends one 20-byte Bluetooth notification per
interval to the [phone app](../../app/). The same sample is printed as a CSV
line on USB serial for bench work. All signal processing happens in the app.

[docs/phone_board.md](../../docs/phone_board.md) is the source of truth for the
pin map, the Bluetooth protocol and the packet layout; the header comment of
[src/main.cpp](src/main.cpp) explains how the sampling, the heater control and
the low-battery cutoff work.

## Build and flash

With [PlatformIO](https://platformio.org/) installed, from the repository root:

```
pio run -d firmware/phone_board                    # build
pio run -d firmware/phone_board --target upload    # flash over USB-C
pio device monitor -d firmware/phone_board         # serial output, 115200
```

The power switch must be ON to flash (it gates the 3.3 V rail). If the board
does not enumerate, hold **BOOT**, tap **RESET**, release **BOOT** and retry.
Library versions are pinned in [platformio.ini](platformio.ini).

The board advertises as `CH4-XXXX` (the last two bytes of its Bluetooth
address) and reports its board type as `rev-b` on both layouts. The rev D draft board needs changed constants that are not written
yet; see [its README](../../hardware/phone_board_mems/README.md).

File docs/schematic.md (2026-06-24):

# Carrier-board connection spec (rev A)

The electrical specification for the first PCB: a **carrier board** that the
ESP32-S3-Zero and every sensor module plug into, replacing the breadboard. Every
active part stays a pre-made breakout on headers; the only components actually
soldered to the board are the two resistor dividers (and optional decoupling /
pull-ups). This document is the source of truth for the schematic — the
`.kicad_sch` is captured from the nets listed here.

It is derived directly from the firmware pin map in
[../src/main.cpp](../src/main.cpp) and the hardware table in the
[../README.md](../README.md). If the firmware pin assignments change, change them
here too.

## Design intent

- **Nothing fine-pitch.** The S3-Zero and all sensors are modules on 2.54 mm
  headers. No bare ICs, no USB, no flash on this board.
- **Two power rails + ground.** A **5 V** rail (Figaro heaters) and a **3V3** rail
  (everything digital), both sourced from the S3-Zero, plus a common GND.
- **The dividers are the only real circuit.** Each Figaro VOUT can reach ~4.95 V;
  a 10k/10k divider halves it to a safe ~2.5 V before it reaches a 3.3 V ADC pin.
- **rev A is a learning board.** Expect to socket, test, and respin.

## Reference designators

| Ref | Part | Plugs in as | Notes |
|---|---|---|---|
| U1 | Waveshare ESP32-S3-Zero | module on female headers | the MCU; sources both rails |
| U2 | Figaro NGM2611-E13 (CH4) | 5-pin module | methane; VOUT → divider → GPIO1 |
| U3 | Figaro LPM2610-D09 (LPG) | 5-pin module | LP gas; VOUT → divider → GPIO2 |
| U4 | SSD1306 128x64 OLED | 4-pin I2C module | addr 0x3C |
| U5 | DFRobot Gravity GNSS (L76K) | Gravity / 4-pin module | addr 0x20, I2C mode |
| U6 | Bosch BME280 | 4- or 6-pin I2C module | addr 0x76 |
| U7 | Fermion microSD module | 6-pin SPI module | own SPI bus |
| R1, R2 | 10 kΩ resistor | soldered | CH4 divider (R1 series, R2 to GND) |
| R3, R4 | 10 kΩ resistor | soldered | LPG divider (R3 series, R4 to GND) |
| C1, C2 | 10 µF + 100 nF (optional) | soldered | bulk + HF decoupling on 5 V rail |
| R5, R6 | 4.7 kΩ (optional) | soldered | I2C pull-ups, only if modules' own are removed |

## Power rails

| Rail | Source | Loads |
|---|---|---|
| **+5V** | U1 `5V` pin (live only when USB-powered) | U2 VIN, U3 VIN |
| **+3V3** | U1 `3V3` pin | U4, U5, U6, U7 VCC |
| **GND** | U1 `GND` | every module GND, R2, R4, divider bottoms |

> **Warning:** the S3-Zero's `5V` pin only carries 5 V when the board is powered
> over its USB port. If you ever power the board through the `3V3` pin instead, the
> Figaro heaters get nothing and the survey silently fails. rev A assumes USB power.

## The divider sub-circuit (×2)

Each Figaro module's conditioned VOUT is halved before it reaches the ADC:

```
   U2 VOUT (CH4) ──[ R1 10k ]──┬──[ R2 10k ]── GND
                               │
                               └──────────────── U1 GPIO1   (net CH4_ADC)

   U3 VOUT (LPG) ──[ R3 10k ]──┬──[ R4 10k ]── GND
                               │
                               └──────────────── U1 GPIO2   (net LPG_ADC)
```

The midpoint is VOUT/2 (~2.5 V at the factory alarm level, well under the 3.3 V
pin limit). The firmware multiplies by `VOUT_DIVIDER_RATIO = 2.0` to recover the
real VOUT, and warns if a pin reads near its ceiling — the signature of a missing
or open divider feeding raw VOUT to the pin. Keep R1–R4 physically close to U1's
ADC pins.

## Connections, by component (pin → net)

### U1 — ESP32-S3-Zero
Only the pins the firmware uses are listed; all others are left unconnected on
rev A (but bring the free ones to a spare header — see Notes).

| U1 pin | Net | Goes to |
|---|---|---|
| 5V | +5V | rail (from USB) → U2/U3 VIN |
| 3V3 | +3V3 | rail → U4/U5/U6/U7 VCC |
| GND | GND | common ground |
| GPIO1 | CH4_ADC | R1/R2 divider midpoint |
| GPIO2 | LPG_ADC | R3/R4 divider midpoint |
| GPIO6 | I2C_SDA | U4 SDA, U5 D/T, U6 SDA |
| GPIO7 | I2C_SCL | U4 SCL, U5 C/R, U6 SCL |
| GPIO10 | SD_CS | U7 CS |
| GPIO11 | SD_MOSI | U7 MOSI |
| GPIO12 | SD_SCK | U7 SCK |
| GPIO13 | SD_MISO | U7 MISO |

GPIO0 (BOOT/re-zero) and GPIO21 (WS2812 status LED) are **onboard the S3-Zero** —
no external wiring.

### U2 — NGM2611-E13 (methane, CH4)
| U2 pin | Net | Notes |
|---|---|---|
| 1 VIN | +5V | heater + element |
| 2 VOUT | CH4_VOUT | → R1 |
| 3 VREF | — | leave unconnected |
| 4 VH− | GND | heater return |
| 5 GND | GND | |

### U3 — LPM2610-D09 (LP gas, LPG)
| U3 pin | Net | Notes |
|---|---|---|
| 1 VIN | +5V | |
| 2 VOUT | LPG_VOUT | → R3 |
| 3 VREF | — | leave unconnected |
| 4 VH− | GND | |
| 5 GND | GND | |

### U4 — SSD1306 OLED (0x3C)
| U4 pin | Net |
|---|---|
| VCC | +3V3 |
| GND | GND |
| SCL | I2C_SCL |
| SDA | I2C_SDA |

### U5 — DFRobot Gravity GNSS L76K (0x20)
Pads are dual-labelled (I2C vs UART); driving I2C selects it.
| U5 pad | Net | Notes |
|---|---|---|
| + | +3V3 | accepts 3.3–5.5 V |
| − | GND | |
| C/R | I2C_SCL | SCL in I2C mode |
| D/T | I2C_SDA | SDA in I2C mode |

### U6 — BME280 (0x76)
| U6 pin | Net | Notes |
|---|---|---|
| VCC / VIN | +3V3 | |
| GND | GND | |
| SCL | I2C_SCL | |
| SDA | I2C_SDA | |
| CSB | +3V3 | 6-pin boards only: ties to 3V3 to select I2C |
| SDO | GND | 6-pin boards only: ties to GND for addr 0x76 |

### U7 — Fermion microSD module
3.3 V card — VCC to +3V3, **not** 5 V.
| U7 pin | Net |
|---|---|
| VCC | +3V3 |
| GND | GND |
| SCK | SD_SCK |
| MISO | SD_MISO |
| MOSI | SD_MOSI |
| CS | SD_CS |

## Net list (net → pins)

| Net | Connected pins |
|---|---|
| +5V | U1.5V, U2.1, U3.1 (+ C1/C2 if fitted) |
| +3V3 | U1.3V3, U4.VCC, U5.+, U6.VCC, U6.CSB |
| GND | U1.GND, U2.4, U2.5, U3.4, U3.5, U4.GND, U5.−, U6.GND, U6.SDO, U7.GND, R2, R4 |
| I2C_SDA | U1.GPIO6, U4.SDA, U5.D/T, U6.SDA |
| I2C_SCL | U1.GPIO7, U4.SCL, U5.C/R, U6.SCL |
| CH4_VOUT | U2.2, R1 |
| CH4_ADC | U1.GPIO1, R1, R2 |
| LPG_VOUT | U3.2, R3 |
| LPG_ADC | U1.GPIO2, R3, R4 |
| SD_SCK | U1.GPIO12, U7.SCK |
| SD_MISO | U1.GPIO13, U7.MISO |
| SD_MOSI | U1.GPIO11, U7.MOSI |
| SD_CS | U1.GPIO10, U7.CS |

## Bill of materials (electrical)

| Qty | Item | Value / part | Notes |
|---|---|---|---|
| 1 | ESP32-S3-Zero | Waveshare ESP32-S3FH4R2 | socketed |
| 1 | Methane module | Figaro NGM2611-E13 | 5 V |
| 1 | LP-gas module | Figaro LPM2610-D09 | 5 V |
| 1 | OLED | SSD1306 128x64 I2C 0x3C | 3V3 |
| 1 | GNSS | DFRobot Gravity L76K | 3V3, I2C |
| 1 | Environment | Bosch BME280 0x76 | 3V3, I2C |
| 1 | microSD | Fermion microSD module | 3V3, SPI |
| 4 | Resistor | 10 kΩ 1% | R1–R4, the two dividers |
| 1 | Bulk cap | 10 µF | optional, 5 V rail |
| 1 | HF cap | 100 nF | optional, 5 V rail |
| 2 | Resistor | 4.7 kΩ | optional I2C pull-ups (see Notes) |
| — | Headers | 2.54 mm female | one socket per module |

## Notes / gotchas for layout

1. **I2C pull-ups.** SDA/SCL need one pair of pull-ups. Most of U4/U5/U6 carry
   their own, so with three modules you may have three sets in parallel (~1.6k if
   all 4.7k) — usually fine, occasionally too low. If the bus misbehaves, remove
   the pull-ups on two of the modules and fit R5/R6 (4.7k) on the carrier as the
   single set. Leave R5/R6 footprints unpopulated by default.
2. **Heater current.** U2/U3 heaters draw real continuous current on +5V. Make the
   +5V traces wider than signal traces and confirm the USB source can supply both.
3. **Divider placement.** Keep R1–R4 right at U1's GPIO1/GPIO2 pins.
4. **Bring out the free GPIOs.** GPIO4, GPIO5, GPIO8, GPIO9, GPIO14–18 are unused —
   route them to a spare header so the throwaway rev can still grow.
5. **No silicone near the Figaro sensors** — it poisons the element irreversibly
   (see [sensors.md](sensors.md)). Affects enclosure/adhesive choice, not copper.
6. **5V comes from USB only** — see the rail warning above.

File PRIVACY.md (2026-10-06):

# GasSnifferBuddy privacy policy

Last updated: 6 October 2026 (survey map added)

GasSnifferBuddy is the phone app for a home-built gas detector. It is published
on the App Store and Google Play by Rebel Heat.

**In short: the app does not collect, send or sell any of your data. Everything
it records stays on your phone unless you choose to share it. The only thing it
downloads is satellite imagery for the survey map.**

## What the app uses, and why

| What | Why | Where it goes |
|---|---|---|
| **Bluetooth** | To connect to your gas sensor board and receive its readings. | Nowhere. Readings stay on your phone. |
| **Your location** | To tag each reading with where it was taken, so a survey can be put on a map. It is only used while the app is open. | Saved in your survey files on your phone. Nowhere else. |
| **Your local Wi-Fi network** (optional, off by default) | Only if you turn on "USB bridge via PC" in Settings, to receive readings from a sensor plugged into your own computer. | Between your phone and your own computer. Nothing goes to the internet. |
| **The internet, for map images** | The Surveys screen shows your route over satellite imagery. The app downloads the picture tiles for the area on screen from Esri's World Imagery service. | Esri receives the standard details of any web request: your IP address and which map squares were asked for, which shows roughly where you are looking. No readings, survey files or account details are sent. Esri's privacy policy is at https://www.esri.com/en-us/privacy/overview |
| **Storage on your phone** | To save your surveys as CSV files, and to remember your settings and sensor calibration. | Stays on your phone. |

## What the app does not do

- It does not connect to the internet for anything except the map images above.
- It has no accounts and no sign-in.
- It has no advertising, analytics or tracking of any kind.
- It does not share data with Rebel Heat or anyone else.

## Sharing your surveys

You can choose to share a survey file, for example by email or to a cloud
drive, using your phone's normal share menu. A survey file contains the gas
readings with their times and GPS positions. Once you share it, the app or
service you send it to handles it under its own privacy policy.

## Deleting your data

You can delete any survey from the Surveys screen in the app. Uninstalling the
app deletes all of its surveys, settings and calibration from your phone.

## Children

The app does not knowingly collect any information from anyone, including
children.

## Changes

If this policy changes, the new version will be posted at this same address
with a new date at the top.

## Contact

Questions about this policy can be raised at
https://github.com/JamesTwallin/gas_sensor/issues

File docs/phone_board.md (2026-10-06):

# Phone-companion board (rev B / C) — design spec

> **Rev C (`hardware/phone_board`) is the current design.** It is rev B
> compacted from 66 × 36 to 60 × 33 mm with the same schematic, parts and pin
> map, so everything electrical below applies to both. Rev B is the layout that
> was fabricated and bench-tested (git tag `rev-b`); where this document says
> "rev B" it means the circuit the two share.
> Rev D (`hardware/phone_board_mems`, draft) swaps the Figaro cans for Winsen
> GM-402B MEMS sensors on a 2.8 V LDO heater rail; its README lists what that
> changes in the sensor loop, the heater monitor and the firmware constants.

Rev B moves everything a phone already does onto the phone. The board keeps only
what a phone cannot do: the gas sensors, the environment sensor, and a radio.

| Job | rev A (carrier, retired) | rev B / C (this) |
|---|---|---|
| MCU | ESP32-S3-Zero dev board on headers | **bare ESP32-S3-MINI-1 module**, soldered |
| Methane | NGM2611-E13 module (alarm + compensation) | **bare TGS2611-E00**, own load circuit |
| LP gas | LPM2610-D09 module | **bare TGS2610-D00**, own load circuit |
| ADC | ESP32 internal, 12-bit | **ADS1115 16-bit** (ESP32 ADC fallback via hand-fitted R22/R25) |
| Environment | BME280 breakout | **SHT40** temp + humidity chip, thermally isolated (pressure comes from the phone's barometer) |
| Position / time | L76K GNSS | **phone** |
| Display | SSD1306 OLED | **phone** |
| Storage | microSD | **phone** (CSV export) |
| Signal processing | firmware (baseline + classifier) | **phone** (slope + spike detector) |
| Power | USB only | **1-cell LiPo** + USB-C charging |
| Link | USB serial | **BLE** (USB CDC kept for debug/flash) |

The firmware becomes a thin sampler: read, average, notify over BLE. The signal
processing moves to the app, where it is easier to tune. The app does not carry
over rev A's HIGH/MED/LOW classifier or show its percentile baseline: the
absolute level wanders too much. It monitors the slope of each channel instead
(see the CSV section below).

This file is the source of truth for the schematic generator, the firmware and
the app. Change it first.

## Why bare sensors

The NGM/LPM modules hide the sensor resistance Rs behind a thermistor-compensated
comparator circuit. With the bare element and a known load resistor, the app can
compute Rs directly and apply its own temperature/humidity compensation from the
SHT40 — the datasheet curves in [sensors.md](sensors.md) are all in terms of Rs,
so this is the first build where they can actually be applied.

## Power

```
USB-C VBUS ──► BQ24073 charger/power-path ──► VSYS (4.4 V on USB, VBAT on battery)
                     │ BAT ◄── Q1 AO3401A (reverse-battery P-FET) ◄──► 1S LiPo (JST-PH)
SW1 slide switch ──► PWR_EN (VSYS = on, open = off, 1M pull-down) ──► LDO EN
ESP32 GPIO7 ──► HTR_EN (100k pull-down: heaters off until firmware drives it high)
VSYS ──► TPS61023 boost (EN = HTR_EN) ──► +5V_HTR  (both TGS heaters + sensor circuits, ~115 mA)
VSYS ──► AP2112K-3.3 LDO (EN = PWR_EN) ──► +3V3    (ESP32-S3, ADS1115, SHT40, LED)
```

- Heaters want 5.0 V ± 0.2 V; VSYS never exceeds 4.4 V, so a plain boost is enough.
  The TPS61023 truly disconnects its output when disabled.
- The power switch only carries logic current: it switches the regulator enables.
  Off still charges the battery (the BQ24073 has no SYSOFF pin, so its
  battery-to-OUT FET stays on). Off-state drain is < 10 µA: BQ24073 sleep ~5 µA
  plus the 1M/1M VBAT divider ~2 µA. SW1's third throw is left open, so the
  switch can never short VSYS to GND mid-travel.
- Heaters are firmware-controlled: GPIO7 must drive HTR_EN high after boot (and
  low for the low-battery cutoff). Until then the 100k pull-down keeps them off,
  so there is no heater inrush during boot and a firmware crash fails safe.
  The firmware drives it high as the first thing in `setup()`, with the CPU at
  80 MHz and before the radio starts: on USB power with no cell fitted, the
  USB500 input limit is marginal for the boost start-up into cold heaters, and
  enabling them later alongside BLE browned the ESP32 out (bench, 2026-09-28).
- USB flashing needs SW1 ON (+3V3 is gated by it).
- There is no deep-discharge cutoff on the board: **use a cell with a built-in
  protection circuit (PCM)**, and have the firmware sleep on low battery.
- Budget: heaters ~2 × 280 mW + ESP32 BLE ~60 mW avg ≈ 0.65 W → ~5 h on 1000 mAh.
- Charger: EN2 = 0, EN1 = 1 (100k from VBUS) → USB500 input limit; ISET 1.8 kΩ → ~500 mA charge;
  TS has a fixed 10 kΩ (no NTC); TMR open → default safety timers.
- Battery JST-PH: pin 1 = −, pin 2 = + (Adafruit/SparkFun convention). **Check
  your cell's polarity before plugging in.** Q1 protects against a reversed cell
  (the board just won't power), but the cell still won't work until swapped.

## Gas sensor circuit (×2)

Figaro TGS2611-E00 (CH4) / TGS2610-D00 (LPG): heater between pins 1 and 4,
sensing electrodes 2 (−) and 3 (+). Not stocked at LCSC — hand-solder.

```
+5V_HTR ── pin 1 (heater) ── pin 4 ── GND
+5V_HTR ── pin 3 (S+) ── pin 2 (S−) ── RLa 20k ──┬── RLb 20k ── GND
                                                  ├── 100 nF ── GND
                                                  ├── ADS1115 AINx
                                                  └── 1k (NOT FITTED) ── ESP32 GPIO (fallback)
```

- VC = 5.0 V, the datasheet standard test condition, so sensitivity curves apply.
- RL = RLa + RLb = 40 kΩ. Clean-air Rs is roughly 12–125 kΩ (TGS2611) and
  23–230 kΩ (TGS2610) (read off Figaro's typical curves), so RL sits near the
  clean-air value, where the output is most sensitive to small changes.
- The ADC sees the tap, `V_tap = VRL / 2` ≤ 2.5 V — safe for the ADS1115 (VDD
  3.3 V) and the ESP32.
- `Rs = RL × (VC − VRL) / VRL` with `VRL = 2 × V_tap`.
- Sensor power `Ps = VC² · Rs / (Rs + RL)²` peaks at 0.16 mW (Rs = RL), far
  under the 15 mW limit.
- The TGS elements run hot (~280 mW heater each). They sit at one end of the
  board; the SHT40 is at the other end on a tongue cut free by routed slots,
  so board warmth doesn't read as ambient temperature.

## ADS1115 (I2C 0x48, ADDR → GND)

| Input | Signal | Scale |
|---|---|---|
| AIN0 | CH4 tap (VRL/2) | ×2 → VRL |
| AIN1 | LPG tap (VRL/2) | ×2 → VRL |
| AIN2 | VBAT via 1M/1M | ×2 → VBAT (reads a few % low: calibrate) |
| AIN3 | +5V_HTR via 100k/100k | ×2 → heater rail (fault check) |

PGA ±4.096 V (125 µV/LSB). ALERT/RDY → GPIO10.

## ESP32-S3-MINI-1-N8 pin map

| GPIO | Net | Notes |
|---|---|---|
| 0 | BOOT | tact switch to GND; reported to the app as flag bit5 (unused there for now) |
| 1 | CH4_ADC_FB | fallback read of CH4 tap via R22 1k (ADC1) — R22 not fitted by default |
| 2 | LPG_ADC_FB | fallback read of LPG tap via R25 1k (ADC1) — R25 not fitted by default |
| 5 | CHG_N | BQ24073 CHG, open-drain, 10k pull-up to 3V3 |
| 6 | PGOOD_N | BQ24073 PGOOD, open-drain, 10k pull-up to 3V3 |
| 7 | HTR_EN | heater boost enable, 100k pull-down: drive HIGH = heaters on, low/input = off |
| 8 | I2C_SDA | 4.7k pull-up; SHT40 + ADS1115 |
| 9 | I2C_SCL | 4.7k pull-up |
| 10 | ADS_RDY | ADS1115 ALERT/RDY, 10k pull-up |
| 19 / 20 | USB D− / D+ | USB-C, native USB (flash + debug serial) |
| 38 | LED_DIN | WS2812-class RGB status LED |
| 43 / 44 | TXD0 / RXD0 | test pads |
| EN | EN | 10k pull-up + 1 µF, RESET switch to GND |
| 3, 45, 46 | — | strapping pins, leave unconnected |

SHT40-AD1B: I2C 0x44. No pressure sensor on the board: the firmware sends pressure as missing (0xFFFF) and the app should take pressure from the phone barometer where available.

## BLE protocol (v1)

Device name `CH4-XXXX` (last 2 MAC bytes). One custom service:

| | UUID |
|---|---|
| Service | `6d1a0001-8f3e-4b8a-9c57-2f6c0e3a7b10` |
| Sample (notify) | `6d1a0002-8f3e-4b8a-9c57-2f6c0e3a7b10` |
| Info (read, JSON) | `6d1a0003-8f3e-4b8a-9c57-2f6c0e3a7b10` |
| Control (write) | `6d1a0004-8f3e-4b8a-9c57-2f6c0e3a7b10` |

**Sample** — 20 bytes, little-endian, one notification per sample (default every 250 ms), fits the default 23-byte ATT MTU:

| Off | Type | Field | Unit |
|---|---|---|---|
| 0 | u8 | version | = 1 |
| 1 | u16 | seq | wraps |
| 3 | u32 | ms_since_boot | ms |
| 7 | u16 | ch4_tap | 0.1 mV at ADC input (VRL/2) |
| 9 | u16 | lpg_tap | 0.1 mV |
| 11 | i16 | temp | 0.01 °C (0x8000 = missing) |
| 13 | u16 | humidity | 0.01 %RH (0xFFFF = missing) |
| 15 | u16 | pressure | 0.1 hPa (0xFFFF = missing) |
| 17 | u16 | vbat | mV (0 = unknown: VBAT is only wired to the ADS1115) |
| 19 | u8 | flags | bit0 USB power, bit1 charging, bit2 T/RH sensor ok, bit3 ADS ok (0 = taps came from ESP32 fallback ADC), bit4 heater rail out of 4.8–5.2 V (only checked when bit3 = 1, not set while bit6 = 1), bit5 BOOT pressed (see below), bit6 heaters off (low battery: firmware drove HTR_EN low after VBAT < 3.3 V for > 10 s on battery; released when VBAT > 3.5 V or USB power is present, and never applied on USB power), bit7 reserved (0) |

**Info** — UTF-8 JSON, e.g.
`{"proto":1,"fw":"1.0.0","board":"rev-b","rl_ohm":40000,"tap_ratio":2.0,"vc_mv":5000,"interval_ms":250,"heater_mv":5012}`
(`vc_mv` is the nominal circuit voltage; `heater_mv` is the latest measured
rail, 0 when the ADS1115 is absent.)

**Control** — first byte is the opcode:

| Op | Payload | Action |
|---|---|---|
| 0x01 | u16 interval_ms (100–5000) | set sample interval |
| 0x02 | — | blink LED (identify) |
| 0x03 | u8 r, u8 g, u8 b | set status LED (the app drives green, red while CH4 is spiking) |

A BOOT-button press is sent as a sample with no extra field: the firmware sets
flag **bit5** on the next sample. The app currently ignores it (it used to
re-zero the baseline).

## App CSV (backwards compatible)

The app writes the rev A column set unchanged, so `tools/plot_map.py` and
`tools/plot_survey.py` keep working, then appends new columns:

```
millis_since_boot,state,ch4_vout_mv,ch4_baseline_mv,ch4_dev_mv,
lpg_vout_mv,lpg_baseline_mv,lpg_dev_mv,temp_c,humidity_pct,pressure_hpa,
utc_iso8601,lat,lon,alt_m,sats,fix,
ch4_rs_ohm,lpg_rs_ohm,vbat_mv,gps_accuracy_m,ch4_ppm_est,lpg_ppm_est,
ch4_slope_mv_s,lpg_slope_mv_s,spike
```

- `*_baseline_mv` / `*_dev_mv` are kept only so the plotting tools keep
  working: the rev A 15th percentile of the last 2 min, fixed. The app neither
  shows nor acts on them.
- `ch4_slope_mv_s` / `lpg_slope_mv_s` are the first derivative of VRL over the
  app's spike window (default 1 s), and `spike` is `CH4`, `LPG`, `CH4+LPG` or
  blank: the app's plume indicator (`app/src/core/spike.ts`; the threshold is a
  fixed mV/s setting, 25 by default, whereas `tools/plot_spike.py` scales its
  own to the noise). A plume is a rising edge; slow drift is not.
- `ch4_ppm_est` / `lpg_ppm_est` are the app's datasheet-curve estimates
  (`app/src/core/ppm.ts`: Rs/Ro power law with the Table 1 temperature and
  humidity correction, LPG referenced to iso-butane). They are only as good as
  Ro: datasheet-typical until the board is calibrated in a known gas from the
  app's Settings, so treat them as indicative. Blank when Rs is unknown.

- `*_vout_mv` is now VRL (sensor load voltage) — same direction as before
  (higher = more gas), different absolute scale from the rev A modules.
- `utc_iso8601`, `lat`, `lon`, `alt_m` come from the phone. `sats` is blank
  (phones don't expose it); `fix` is 1 when horizontal accuracy ≤ 25 m.
- `millis_since_boot` is the board's `ms_since_boot`; `utc_iso8601` is the phone
  clock when the sample arrived. `lat`/`lon`/`alt_m`/`gps_accuracy_m` are the
  latest phone fix; `fix` is also 0 if that fix is more than 10 s old.
- `state` can also be `HEATER_OFF` (flag bit6). The tools only keep `RUNNING`.
- `tools/plot_map.py` applies its minimum-satellite filter only to rows that
  have a `sats` value (rev A logs); phone rows rely on `fix`.

## Bench: USB bridge for Expo Go

Expo Go cannot load `react-native-ble-plx`, so a phone running the app from
`npx expo start --go` has no Bluetooth. For bench work the board can instead be
plugged into a PC and relayed over Wi-Fi by [tools/serial_bridge.py](../tools/serial_bridge.py),
which turns the firmware's serial CSV back into protocol-v1 Sample packets:

```
python tools/serial_bridge.py            # needs pyserial; PlatformIO's python has it
```

- `http://<pc>:8765/` is a live read-out page; `ws://<pc>:8765/ws` carries the
  packets (binary) and the Info JSON (text) to the app.
- In Expo Go the app uses the bridge automatically, defaulting to the PC that
  served the JS bundle. A dev build keeps BLE unless **Settings → USB bridge via
  PC** is on; **Bridge PC address** overrides the host.
- Control opcodes (interval, LED) are dropped: the serial link is one-way.
- Rev A boards work too (their CSV is mapped to VRL / 2 with `tap_ratio` 2.0).

Real BLE needs a development build: `npx expo run:android` with the phone on
USB debugging, or `eas build --profile development`.

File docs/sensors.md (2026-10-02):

# Sensor notes (Figaro NGM2611-E13 and LPM2610-D09)

Calibration and behaviour notes drawn from the official Figaro datasheets, kept
here for provenance and to inform the firmware. Figures cited are from the
"Technical Information for TGS2611" (Revised 11/17) and the matching TGS2610
documents. Where a value is read off a graph rather than a table it is marked
approximate.

> **Which board this describes.** These notes were written for the rev A
> prototype, which used the NGM2611 / LPM2610 *modules*. The current board
> (rev B / C, [phone_board.md](phone_board.md)) mounts the same TGS2611-E00 and
> TGS2610-D00 elements bare, with its own load resistor and an SHT40 instead of
> a BME280. Everything below about the elements (part spread, sensitivity shape,
> temperature and humidity, warm-up, field cautions) applies to it. What
> changes is that Rs is now measurable, so the app can apply the Table 1
> correction and estimate ppm from the datasheet curves
> (`app/src/core/ppm.ts`). That estimate is still only indicative until a board
> is calibrated in a known gas, and the app treats the slope of the signal, not
> its level, as the plume indicator.

## What is actually inside the modules

- **NGM2611-E13** (methane) contains a **TGS2611-E00** element plus a temperature
  compensation circuit (thermistor + trimmed load resistor) and a comparator.
- **LPM2610-D09** (LP gas) contains a **TGS2610-D00** element with the same kind
  of conditioning.
- The **-E** methane element has a **charcoal filter** in the cap to reject
  interference gases (alcohol, and the heavier hydrocarbons).
- The **-D** LP-gas element uses a **zeolite filter** for the same purpose.

The modules expose a **conditioned VOUT**, not the raw sensor resistance Rs. The
datasheet curves below are all in terms of Rs (or VRL across a load resistor),
which we cannot directly recover from the module output. So these notes explain
the *behaviour* and bound what is honestly claimable; they do not give us a
calibrated VOUT-to-ppm conversion.

## Why absolute ppm is not on the table

- **Huge sensor-to-sensor spread.** TGS2611 Rs in 5000 ppm methane is specified
  as **0.68 kOhm to 6.8 kOhm**, a 10x range across parts. Figaro therefore sort
  sensors into 24 ID groups and match a load resistor per group, and still note
  ~10% accuracy loss versus individual calibration. Without per-sensor
  calibration there is no trustworthy absolute ppm.
- The module hides Rs behind its conditioning circuit, single-point calibrated
  at the factory alarm concentration only.

Conclusion: this instrument is an **anomaly / relative-enhancement mapper**, not
a concentration analyser. Published claims should say "elevated above local
background", not a ppm figure.

## Sensitivity shape (useful for intuition, not calibration)

- Reference points differ between the two sensors: TGS2611 normalises Rs/Ro to
  **5000 ppm methane**; TGS2610 normalises to **1800 ppm iso-butane**.
- The methane response is a power law. From the specified
  **beta = Rs(9000 ppm) / Rs(3000 ppm) = 0.60 +/- 0.06**, the exponent is
  `n = ln(0.60) / ln(3) ~= -0.47`, i.e. **Rs is proportional to ppm^-0.47** for
  methane. Resistance falls (and conditioned VOUT rises) as gas increases.
- The LP-gas response is steeper. From
  **beta = Rs(3000 ppm) / Rs(1000 ppm iso-butane) = 0.56 +/- 0.06**, the exponent
  is `n = ln(0.56) / ln(3) ~= -0.53`, i.e. **Rs proportional to ppm^-0.53** for
  iso-butane. The steeper slope fits the LP sensor responding more strongly than
  the methane one. TGS2610 Rs has the same 0.68 to 6.8 kOhm part spread, at its
  reference of 1800 ppm iso-butane.
- This is the bare-element relationship. It tells us the response is monotonic
  and roughly log-shaped, which is why small near-baseline changes correspond to
  relatively large ppm changes. It does not map to module VOUT without
  characterising the module.

## Temperature and humidity (the confounder, quantified)

TGS2611 Table 1, Rs/Ro at 5000 ppm methane normalised to 20 C / 65 %RH (so
1.00 is the reference point):

| Temp \\ RH | 35% | 50% | 65% | 95% |
|---|---|---|---|---|
| -10 C |  |  |  | 1.51 |
| 0 C |  |  | 1.45 | 1.25 |
| 10 C |  | 1.33 | 1.19 | 1.02 |
| 20 C | 1.25 | 1.11 | 1.00 | 0.87 |
| 30 C | 1.05 | 0.94 | 0.86 | 0.77 |
| 40 C | 0.92 | 0.82 | 0.76 | 0.69 |

Reading this:

- **Both rising temperature and rising humidity lower Rs/Ro**, which on a MOX
  sensor looks like *more reducing gas*. So a humidity rise can masquerade as a
  gas anomaly.
- **Humidity is large.** At 20 C, going from 35 %RH to 95 %RH drops Rs/Ro from
  1.25 to 0.87, roughly a **30% change**. Stepping into fog, dew or rain is a
  real false-positive source.
- **Temperature alone is also large** (1.00 to 0.76 from 20 C to 40 C at 65 %RH),
  **but the module compensates for temperature** via its onboard thermistor. A
  thermistor senses temperature only, so **humidity is not compensated** and is
  the residual confounder we must handle ourselves.

How we handle it: log temperature, humidity and pressure (a **BME280** on the
shared I2C bus) with every reading for provenance, let the adaptive baseline
absorb slow drift, and flag fast humidity changes so a humidity-driven step is
not mistaken for a leak. We do **not** apply a numeric correction from this table
to VOUT, because the table is bare-element Rs/Ro and the module conditions and
hides Rs; doing so would invent precision. (The BME280 was chosen over a bare
AM2302/DHT22 because it joins the existing I2C bus with no extra GPIO or pull-up,
and the barometric channel is a free bonus -- an independent cross-check on the
GNSS altitude.)

TGS2610 Table 1, Rs/Ro at 1800 ppm iso-butane normalised to 20 C / 65 %RH:

| Temp \\ RH | 35% | 50% | 65% | 95% |
|---|---|---|---|---|
| -10 C |  |  |  | 1.60 |
| 0 C |  |  | 1.50 | 1.35 |
| 10 C |  | 1.50 | 1.23 | 1.08 |
| 20 C | 1.52 | 1.19 | 1.00 | 0.85 |
| 30 C | 1.23 | 0.94 | 0.79 | 0.68 |
| 40 C | 0.98 | 0.75 | 0.61 | 0.53 |

**The LP-gas sensor is more temperature- and humidity-dependent than the methane
one.** At 20 C, 35 %RH to 95 %RH drops Rs/Ro from 1.52 to 0.85, about **44%**
(versus ~30% for the methane sensor). So the **LPG channel is the more
humidity-vulnerable of the two**: a humidity rise lifts both channels, but the LP
channel further. The same caveat applies, that the module compensates
temperature but not humidity, so this RH sensitivity largely passes through to
the LPG VOUT.

## Warm-up and "initial action"

- On power-up after being unpowered, Rs drops sharply for the first seconds then
  recovers; this "initial action" can read as a false alarm. TGS2611 Fig. 12
  shows it settling within roughly **3 to 5 minutes**.
- The NGM2611 application guidance uses a **~2.5 minute startup delay**.
- Implication: the firmware's 15 s bench warm-up is only adequate because the
  sensor heater stays powered across reflashes. A genuine cold start needs
  minutes; lengthen WARMUP_MS for real surveys.

## Field cautions that affect the build

- **Silicone will poison the sensor irreversibly.** Do not use silicone RTV,
  sealants, adhesives or greases anywhere near the sensor (common in enclosures).
  Decomposed silicone coats the element and permanently kills sensitivity.
- **Water matters.** Condensation that lingers causes drift; freezing water
  cracks the element. Protect the inlet; keep it out of standing water and rain.
- **Air flow cools the element.** A 3.1 m/s stream changed VRL by about a factor
  of 1.11 (TGS2611 Fig. 16). So an aspirator fan helps sampling but shifts the
  reading; keep airflow consistent if one is fitted.
- **Needs ~21% oxygen** to behave as specified (fine outdoors).
- **The lighter test does not work on the methane channel.** The TGS2611-E
  charcoal filter blocks iso-butane, so lighter gas (butane) will **not** reach
  the methane element. Use lighter gas only to test the LP-gas (LPM2610) channel;
  test the methane channel with an actual methane source (mains natural gas).
  Also: prolonged or >10% iso-butane exposure can damage the element, so keep any
  such test brief.

## Candidate add-on: a particulate/combustion channel to reject traffic

Vehicle exhaust is a known false positive for this instrument. Petrol and diesel
exhaust carry CO, NOx and unburnt VOCs, all reducing gases the MOX elements
respond to -- and crucially the methane channel's **charcoal filter does not
adsorb CO** (too small and non-polar), so exhaust CO reaches the methane element
and mimics a leak. Composition alone (the CH4/LPG channels) therefore cannot
cleanly separate a passing vehicle from a gas leak.

The clean discriminator is a sensor that responds to **combustion but not to a
gas leak**, because a natural-gas leak emits **zero particulates** -- methane,
ethane and propane are gases, no soot. That orthogonality is exactly what a veto
channel needs; there is no cross-talk path from a leak into a particulate count.

- A bare PM sensor (Plantower PMS5003, Sensirion SPS30) flags **diesel** well --
  buses, lorries and idling taxis are the worst MOX confounders and the biggest
  PM emitters. It **under-catches petrol/GDI** exhaust (low PM, but plenty of
  CO/VOC that still hits the MOX) and EVs emit no exhaust gas anyway (only coarse,
  intermittent brake/tyre PM10).
- Preferred: a **Sensirion SEN5x (e.g. SEN55)** -- one **I2C** module giving
  PM1/2.5/4/10 **+ a NOx index + a VOC index + RH/T**. The NOx index rises with
  *all* combustion exhaust (diesel especially), plugging the petrol gap PM leaves;
  PM pins diesel/soot and doubles as an air-quality map; the RH/T feeds the
  humidity confounder we already track. Like the BME280 it joins the **existing
  I2C bus with no extra GPIO** (bare PM sensors such as the PMS5003 are UART).

Use it as a **coincidence veto, not a subtraction**: a transient CH4/LPG spike
arriving *with* a coincident PM/NOx spike is flagged as traffic and downweighted;
a spike with PM/NOx flat is kept as a candidate leak. Layer this on top of the
spatial persistence / revisit test (a real leak is anchored and repeats across
passes; a passing car is a one-time puff) -- the two attack the problem from
independent directions, which is what makes the combination robust.

Caveats: the Sensirion VOC/NOx outputs are *relative index* values (gas-agnostic),
useful as confounder flags but not as species ID; the module is fan-driven and
the docs above note airflow cools the MOX element and shifts its reading, so mount
the PM inlet so its fan does not pull across the gas inlet; and this rejects
*combustion*, not biogenic methane -- separating fossil from biogenic is still the
job of the CH4-vs-LPG differential, not this channel.

## Source documents

- TGS2611 Technical Information (Rev 11/17): sensitivity Fig. 4, T/RH Fig. 6 and
  Table 1, initial action Fig. 12.
- TGS2610 Technical Information (Rev 10/12) and Application Notes (Rev 11/13).
- NGM2611-E13 and LPM2610-D09 module product information (Rev 03).

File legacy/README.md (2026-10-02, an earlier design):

# Legacy

Earlier versions, kept for reference. **Nothing here is the current design**:
that is the rev C board in [hardware/phone_board](../hardware/phone_board/) with
the firmware in [firmware/phone_board](../firmware/phone_board/) and the phone
app in [app](../app/). Start from the [top-level README](../README.md).

| Folder | What | Why it is here |
|---|---|---|
| [rev_a](rev_a/) | The first prototype: a Waveshare ESP32-S3-Zero and sensor modules on a carrier board, with its own OLED, GNSS receiver and microSD card. Firmware, KiCad project, connection spec and photos. | Replaced by the phone-companion boards (rev B onwards), which move the display, position and storage onto a phone. |
| [enclosure](enclosure/) | The two box-and-lid case models. | Replaced by the front-shell-and-battery-tray case in [hardware/enclosure](../hardware/enclosure/). |

The rev B board (the 66 × 36 mm layout that was built and tested) is not a
folder: rev C replaced it in place. Its files are at the git tag `rev-b`.

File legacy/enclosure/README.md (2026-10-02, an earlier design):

# Box-and-lid enclosures (superseded)

> Kept for reference. The current case is the front shell and battery tray in
> [hardware/enclosure](../../hardware/enclosure/).

Two earlier two-part cases for the phone-companion board, both a base with a
screwed-on lid and the sensor cans through collars in the lid.

| File | What |
|---|---|
| `case_revb.scad` | for the 66 × 36 mm rev B board; printed and fitted in September 2026 |
| `stl/revb_base.stl`, `stl/revb_lid.stl` | its parts, after the fit revision described below |
| `case_revc.scad` | the same case re-parameterised for the 60 × 33 mm rev C board; never rendered or printed (it was `case.scad`) |
| `stl/base.stl`, `stl/lid.stl` | exported before `case_revc.scad` was re-parameterised, so they still show the rev B case; do not print them for rev C |

The renders these notes refer to (`build/*.png`) are not tracked; regenerate
them with the OpenSCAD commands below.

## `case_revb.scad`: rev B board

For the 66 × 36 mm rev B boards fabricated in September 2026. The same chimney
case as the rev C one below, with the sensor cans through collars in the lid,
plus:

- a dense hex grille in the lid right up to the sensor collars, and two rows of
  wall louvres on three sides of the sensor end of the base, so the cans sit in
  moving air even when you're standing still;
- four zip-tie eyelets on the outside of the long walls at floor level, taking
  5 mm ties, for strapping the case to a pole, a handlebar or a pack strap;
- the power switch in an open notch through the top of the wall, with a thumb
  scallop in the lid edge, so it can be worked from the side or from above
  without looking;
- an 8.5 mm battery pocket for the Pi Hut 2000 mAh cell (60 × 38 × 8 mm), with a
  stop rib that keeps the cell clear of the H1 screw boss. Push the cell to the
  SHT40 end.

Openings: the USB-C socket sits in a 14 mm wide notch open to the top of the
wall (the lid closes it), so any plug fits and it can be used with the lid off;
the switch is in a similar notch on the opposite edge. There is no opening for
the battery plug, which is internal. Print the base floor down and the lid top face down, no
supports. Files: `stl/revb_base.stl`, `stl/revb_lid.stl`; regenerate with the
OpenSCAD commands below, substituting `case_revb.scad`. Outside size 81 × 51 ×
24 mm, plus the eyelets. `-D 'part="section"'` renders the assembled case cut
in half lengthways, the quickest way to check clearances after a change.

**Fit revision after the first print (2026-09-30).** The first print was too
tight in three places, all fixed:

- the lid's lip dropped inside the cavity wall with 0.35 mm clearance and hit
  the screw posts. The base now has a 1.2 mm rebate around the top of the wall
  and the lip (1.0 mm thick, 1.0 mm tall) sits in that, 0.3 mm clear all round;
- the board's corners were 0.8 mm from the screw posts: `board_clear` is now
  5.0 mm (was 4.5), so the case grew 1 mm each way;
- the cell's top was 0.2 mm into the SHT40-end board shelf. The pocket is now
  9.5 mm deep and the cell sits in a fence (sunk ribs under it, side fences,
  a stop rib at the sensor end); the shelf at that end is replaced by stubs on
  the long walls outside the cell's width. 0.8 mm between cell and supports.

Also widened: sensor collar holes to cap + 1.6 mm (printed holes shrink), the
USB-C opening to 12 × 5 mm.

**Mirror fix, same revision.** The first print's sensor holes and wall openings
were a mirror image of the board. KiCad's y axis runs down the board and the
model's runs up, and the earlier mapping ignored that. `by()` now flips y, so
the KiCad top edge (switch) is the model's high-y wall and the KiCad bottom
edge (USB-C, battery plug) is the low-y wall. Every position in the file is
still written in KiCad coordinates; only the mapping changed.

## `case_revc.scad`: rev C board (not yet fabricated)

74 × 47 × 19.5 mm two-part case for the rev C layout.
The Figaro sensor cans poke through the lid so they sit in open air, and the case
is a chimney: air in through the wall louvres and floor vents, up past the hot
sensors, out through the lid grille.

**Status: parameters updated for the rev C board (60 × 33 mm), not yet
re-rendered, printed or fitted.** `case_revc.scad` carries rev C's outline, sensor,
USB-C, switch, button, LED, SHT40 and mounting-hole positions, and the battery
plug opening has moved from the bottom wall to the top wall beside the power
switch, where rev C's JST-PH now points (both power leads leave at the ESP32
end, away from the sensors). The STLs `stl/base.stl` and `stl/lid.stl` still show the rev B case:
regenerate them (below) before printing.

**Open problem before printing: the board hold-down.** The rev B case screwed
the board to a floor boss at its H1 hole, in a corner the cell did not reach.
A 60 × 33 mm board is smaller than the cell (the Pi Hut 2000 mAh cell the
pocket is now sized for is 60 × 38 × 8 mm), so every point of the board is over
the cell and the boss at `mount` lands on top of it. Either fit a shorter cell
(a 1000 mAh 50 × 34 mm cell leaves the H1 end clear) or replace the boss with a
hold-down from the lid before trusting the model.

## Regenerating

OpenSCAD 2021.01+; substitute `case_revb.scad` and the `revb_` file names for
the rev B case:

```
openscad -o stl/base.stl -D 'part="base"' case_revc.scad
openscad -o stl/lid.stl  -D 'part="lid"'  case_revc.scad
openscad -o build/assembly.png --imgsize=1400,1000 --camera=48,26,14,62,0,28,250 -D 'part="assembly"' case_revc.scad
```

`part="assembly"` also draws a mock board, sensors and cell, which is the quickest
way to check a change hasn't broken clearances.

## Printing (Bambu A1)

- **Material: PETG or ASA.** The heaters put ~0.6 W inside a small box and the
  case sits in sunlight on surveys; PLA creeps and can sag. PETG is the easy pick.
- **0.2 mm layers, 3 walls, 20 % infill.** No supports, no brim needed.
- **Orientation:**
  - **Base:** floor down, as modelled.
  - **Lid:** **top face down** on the plate. The sensor collars then print up from
    the plate, the locating lip points up, and the LED window prints as a clean
    0.4 mm membrane. Printed the other way up, the lip needs supports.
- Both parts fit the A1 plate easily; together about 35 g.

## Hardware you need

| Qty | Item |
|---|---|
| 4 | M2 × 8 mm self-tapping screws (lid into the corner posts) |
| 1 | M2 × 5 mm self-tapping screw (board to the boss at H1) |
| 1 | 1S LiPo, JST-PH, protected: pocket sized for the Pi Hut 2000 mAh cell, 60 × 38 × 8 mm (`batt_h = 8.5`); a 1200 mAh 60 × 35 × 5 mm cell also fits (see the board README for polarity) |
| — | optional: 2 mm foam pad under the cell |

The posts take M2 self-tappers directly (1.7 mm pilot holes). If you prefer heat-set
inserts, open the pilots to 3.2 mm and set M2 × 3 mm inserts.

## Assembly

1. Drop the cell into the floor pocket, wires toward the bottom-right, and route
   the lead up the right-hand end. The ribs hold it off the floor vents.
2. Lower the board onto the end shelves, sensors at the right-hand end.
3. Fit the M2 × 5 screw through the board's H1 hole into the boss.
4. Plug the battery into J2 through the top-wall opening next to the power
   switch. **Check the polarity first** (board README).
5. Line the sensor cans up with the lid collars and lower the lid. The lip locates
   it; the cans should pass through without touching.
6. Four M2 × 8 screws, gently — they cut their own threads.

## Openings

- **Bottom edge:** USB-C.
- **Top edge:** the battery connector opening and the power slide switch,
  lever reachable from the side.
- **Right end:** louvres only; the sensor cans overhang the board edge here.
- **Lid:** sensor collars, hex grille over the sensor end and over the SHT40,
  RST and BOOT holes (press with a pen or paperclip), LED window.
- **Walls:** louvres at board level, sensor end and SHT40 end.
- **Left end:** lanyard loop.

## Known compromises

- **Not weatherproof.** The sensors need open air; the case is vented top, bottom
  and sides. Drizzle-resistant if the lid faces up, nothing more.
- **The cell covers most of the floor vents.** That's why the wall louvres are
  there. If you run without a battery, airflow is considerably better.
- **The board is supported at its ends**, not the middle. Press RST/BOOT gently.
- **The sensor cans get hot** (~280 mW each). They protrude by design; don't grip
  them, and give the device a minute of settling after handling before trusting
  a reading.
- **SHT40 accuracy:** the tongue on the board and the vents at that end help, but
  temperature inside any case reads slightly high. Compare against a reference
  thermometer before trusting absolute temperature.

## If you change the board

Each model carries the board dimensions and part positions at the top (all in
KiCad board coordinates, origin at the board's top-left corner). Update them
there and re-export; nothing else is hard-coded. Set `board_t = 1.0` if you order
1 mm boards.

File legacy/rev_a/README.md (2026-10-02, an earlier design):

# Rev A prototype (retired)

> This is the first prototype, kept for reference. The current design is the
> rev C board and phone app: see the [top-level README](../../README.md).

A self-contained logger: two Figaro sensor modules, a GNSS receiver and a BME280
on a carrier board, logging a geotagged CSV to a microSD card and showing a
status screen on an OLED. The firmware logs exactly what the hardware reported,
uncorrected.

<p align="center">
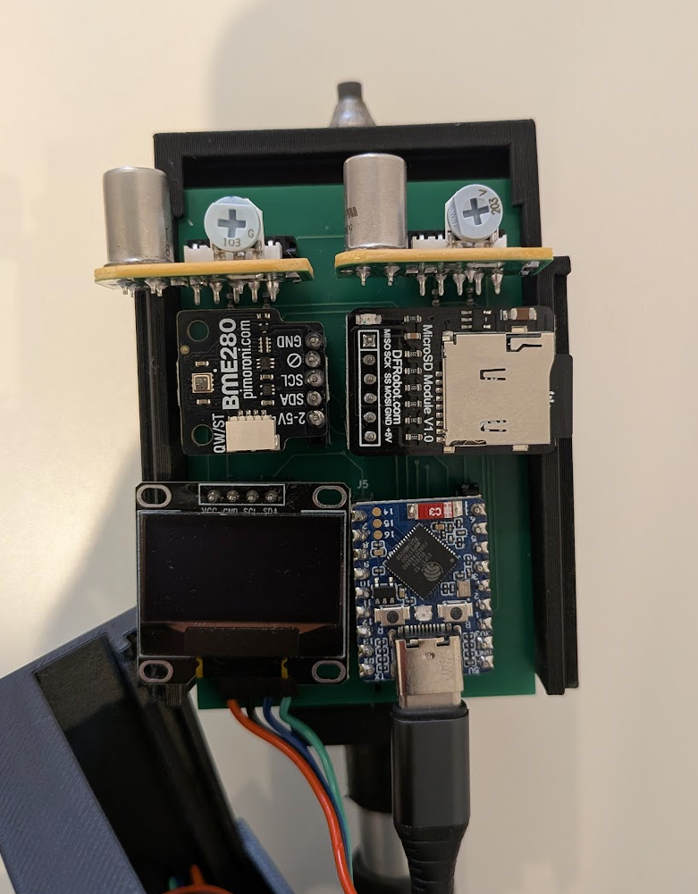
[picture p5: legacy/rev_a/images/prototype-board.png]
The assembled prototype: ESP32-S3-Zero, two Figaro modules, GNSS, BME280 and microSD on the carrier board
  
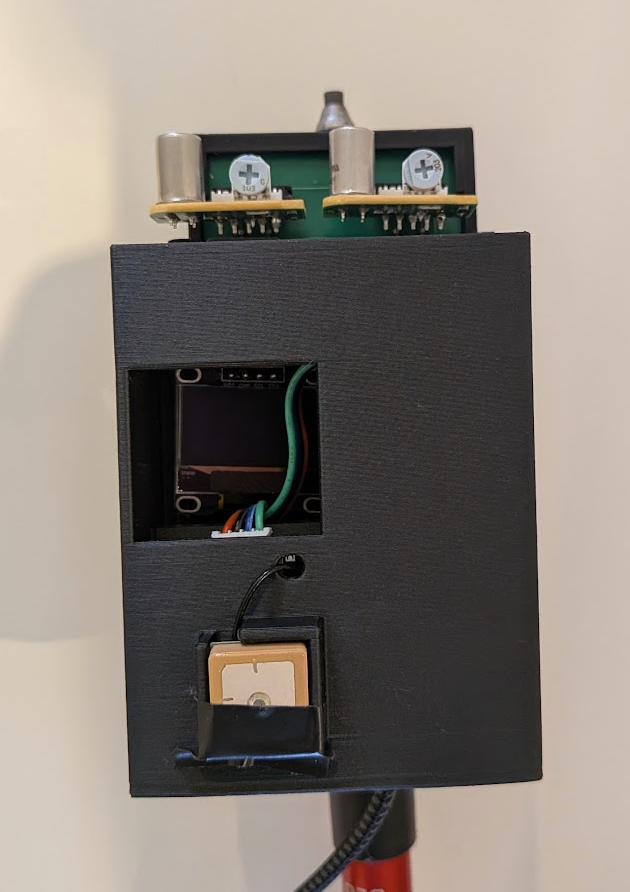
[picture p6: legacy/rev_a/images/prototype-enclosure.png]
The prototype in its hand-held enclosure, OLED visible through the front cut-out
  
</p>

## What is here

```
platformio.ini    build configuration, board, flags, pinned libraries
src/main.cpp      firmware (design notes in its header comment)
schematic.md      connection spec: every pin, net and rail
carrier_board/    KiCad 9 project
images/           photos of the built prototype
```

## Status

The firmware works: it reads both gas channels, the OLED, the GNSS and the
BME280, runs a rolling-percentile baseline and a HIGH/MED/LOW classifier, drives
the onboard RGB status LED, and logs one geotagged row per sample to microSD (and
serial). The BOOT button re-zeros the baseline. NVS storage and a dedicated mark
button were never done. The full design notes are in the header comment of
[src/main.cpp](src/main.cpp).

**Known limitation:** the DFRobot GNSS library (I2C mode) gives satellite count,
position, altitude and UTC, but **not** HDOP or fix type, so the firmware derives
a coarse FIX / NO-FIX from satellite count and plausible coordinates. Real fix
quality would need the module's UART NMEA stream.

## Hardware

Target board: **Waveshare ESP32-S3-Zero** (ESP32-S3FH4R2 — 4 MB flash, 2 MB
PSRAM, native USB). It has no official PlatformIO definition, so the build uses
`esp32-s3-devkitc-1` with flash pinned to 4 MB.

| Peripheral | Part | Interface | Power |
|---|---|---|---|
| OLED display | SSD1306 128x64 | I2C (0x3C) | 3V3 |
| Methane sensor | Figaro NGM2611-E13 | analog VOUT → ADC | 5V |
| LP-gas sensor | Figaro LPM2610-D09 | analog VOUT → ADC | 5V |
| GNSS | DFRobot Gravity (Quectel L76K) | I2C (0x20) | 3V3 |
| Environment | Bosch BME280 | I2C (0x76) | 3V3 |
| microSD card | Fermion microSD module | SPI | 3V3 |
| Status LED | onboard WS2812 RGB | onboard GPIO | onboard |
| Re-zero button | onboard BOOT | onboard GPIO | — |

### Pin map

Every GPIO the firmware uses, from [src/main.cpp](src/main.cpp):

| GPIO | Function | Connected to | Notes |
|---|---|---|---|
| 0 | BOOT button | onboard BOOT | re-zeros the baseline; also the ROM-bootloader strap |
| 1 | CH4 analog in (ADC1) | NGM2611 VOUT | via 10k/10k divider; `ADC_11db`, 12-bit |
| 2 | LPG analog in (ADC1) | LPM2610 VOUT | via 10k/10k divider; `ADC_11db`, 12-bit |
| 6 | I2C SDA | OLED + GNSS (D/T) + BME280 | shared bus, 100 kHz |
| 7 | I2C SCL | OLED + GNSS (C/R) + BME280 | shared bus, 100 kHz |
| 10 | SPI CS | microSD CS | microSD has its own SPI bus |
| 11 | SPI MOSI | microSD MOSI | |
| 12 | SPI SCK | microSD SCK | |
| 13 | SPI MISO | microSD MISO | |
| 19 / 20 | USB D− / D+ | native USB | serial + flashing — do not reuse |
| 21 | WS2812 data | onboard RGB LED | board is red-first, so the firmware swaps R/G |

Power: the Figaro modules (and their heaters) run from **5V**; the OLED, GNSS and
microSD run from **3V3**; common ground throughout. Free GPIOs for expansion:
4, 5, 8, 9, 14–18.

> **Voltage warning.** Each Figaro VOUT can reach ~4.95 V — above the ESP32-S3's
> 3.3 V limit — so each VOUT **must** go through a 10k/10k divider (~2.5 V at the
> factory alarm level). The firmware applies `VOUT_DIVIDER_RATIO = 2.0` to recover
> the real VOUT and warns on serial if a pin reads near its ceiling, which means a
> divider is missing or open.

Per-sensor wiring notes (addresses, the GNSS dual-labelled pads, the BME280-vs-BMP280
check, microSD logging behaviour) are in [schematic.md](schematic.md) and the
[src/main.cpp](src/main.cpp) header. Humidity matters because it is the main
uncorrected confounder for these MOX sensors — see
[docs/sensors.md](../../docs/sensors.md).

## Building and flashing

From the repository root, with [PlatformIO](https://platformio.org/) installed:

1. Build: `pio run -d legacy/rev_a`
2. Flash over USB: `pio run -d legacy/rev_a --target upload`. If the board isn't
   found, enter the ROM bootloader by hand: hold **BOOT**, tap **RESET**, release
   **BOOT**, retry.
3. Watch output: `pio device monitor -d legacy/rev_a` — you'll see the banner, then ~4 CSV rows/s
   once it reaches RUNNING.

## CSV format

Both the serial stream and the microSD log use one row per sample:

```
millis_since_boot, state, ch4_vout_mv, ch4_baseline_mv, ch4_dev_mv,
lpg_vout_mv, lpg_baseline_mv, lpg_dev_mv,
temp_c, humidity_pct, pressure_hpa,
utc_iso8601, lat, lon, alt_m, sats, fix
```

- Per channel: conditioned VOUT (mV), the rolling clean-air baseline, and their
  difference (`*_dev_mv`, the anomaly). `state` is `WARMUP` / `BASELINING` / `RUNNING`.
- `temp_c` / `humidity_pct` / `pressure_hpa`: the BME280 reading, blank if none
  is fitted. `humidity_pct` is the one that matters for rejecting MOX false positives.
- `utc_iso8601` is `YYYY-MM-DD HH:MM:SS.mmm` (whole second from the GNSS, ms
  interpolated from the on-board clock); blank until the GNSS has time.
- `lat` / `lon` / `alt_m` are only meaningful when `fix` is 1, and are blank
  otherwise so a parser can tell a real 0 from a missing value.

Blank fields throughout mean "not measured", distinct from a real 0. The phone
app writes the same columns first and appends its own, so the scripts in
[tools/](../../tools/) read both.

## Carrier board

The carrier board replaces the breadboard: the ESP32-S3-Zero and every sensor
plug into 2.54 mm header sockets, and the only soldered parts are the two 10k/10k
VOUT dividers (R1–R4). [schematic.md](schematic.md) is the connection spec (every
pin, net and rail).

The KiCad 9 project is in [carrier_board/](carrier_board/). It uses generic
library parts — each module is a header socket, and the ESP32-S3-Zero is modelled
as its two 9-pin headers (a pair of `Conn_01x09`) rather than a custom symbol.
The schematic is captured and the two-layer board is **placed and routed** (with
a ground pour), with [Fabrication Toolkit](https://github.com/bennymeg/Fabrication-Toolkit)
options set for gerber export. A Waveshare ESP32-S3-Zero symbol is vendored under
[carrier_board/lib/](carrier_board/lib/) (from
[jtomka/kicad-esp32-s3-zero](https://github.com/jtomka/kicad-esp32-s3-zero)) but
is not currently used. Treat it as untested — routed and ready for fab, not
validated in hardware.

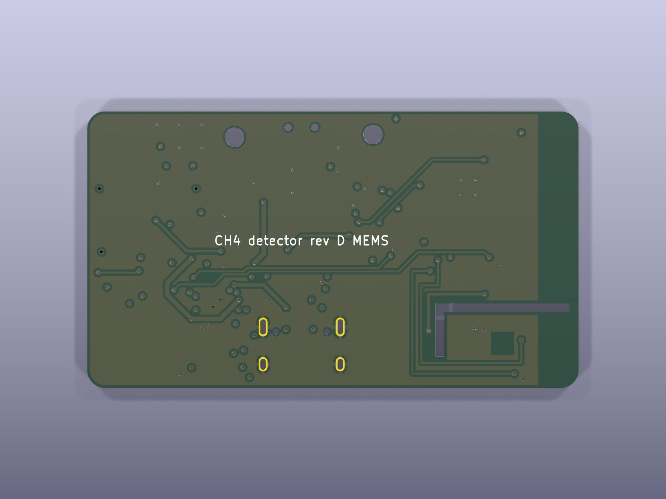
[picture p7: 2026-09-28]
hardware/phone_board_mems/preview/render_bottom.png

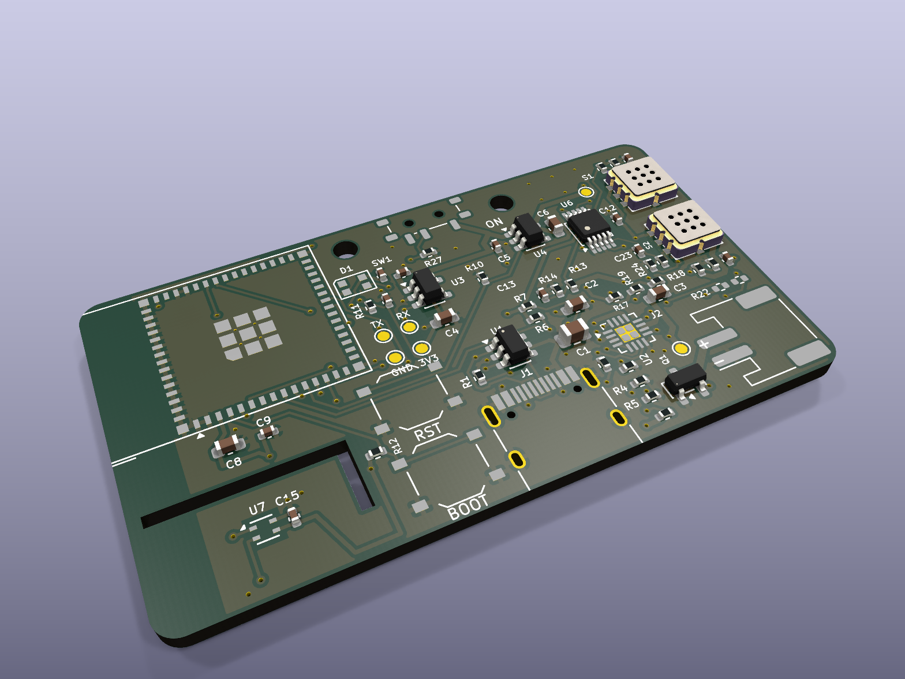
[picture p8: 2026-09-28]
hardware/phone_board_mems/preview/render_iso.png

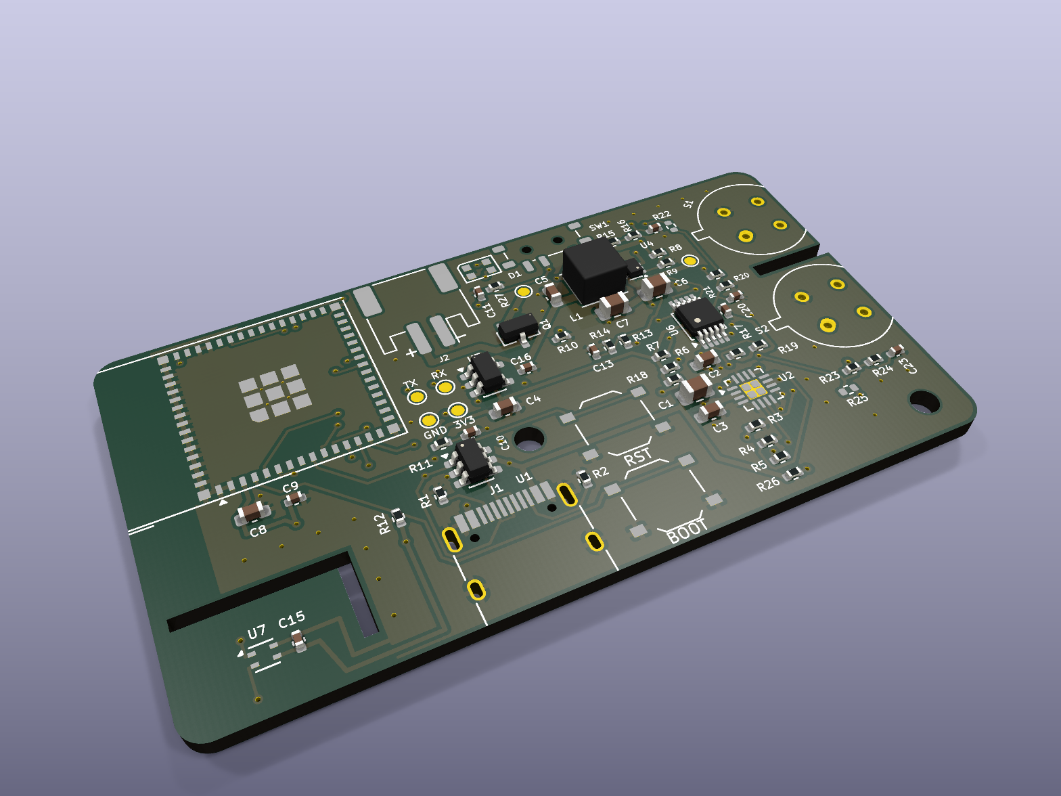
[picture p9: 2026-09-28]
hardware/phone_board/preview/render_iso.png

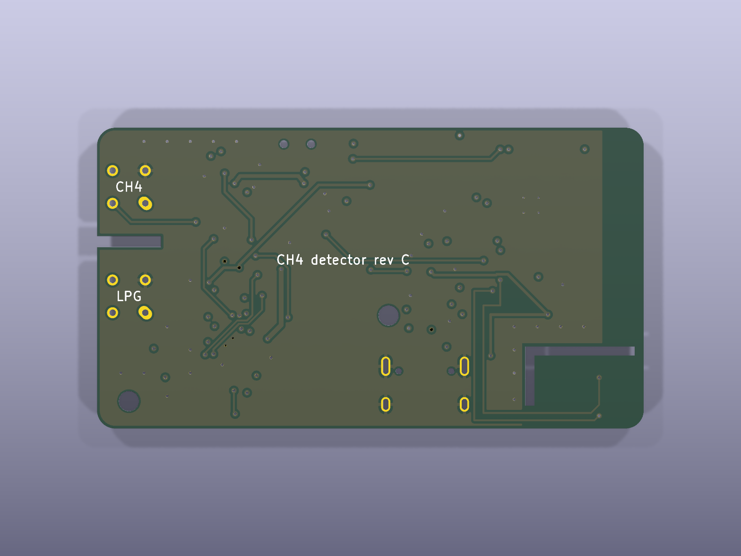
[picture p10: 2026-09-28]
hardware/phone_board/preview/render_bottom.png

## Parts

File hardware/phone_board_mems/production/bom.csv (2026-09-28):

Comment | Designator | Footprint | LCSC Part #
10uF | C1 | C_0805_2012Metric | C15850
1uF | C10,C16,C5 | C_0402_1005Metric | C52923
10uF | C2,C3,C4,C6,C8 | C_0603_1608Metric | C19702
100nF | C11,C12,C13,C14,C15,C20,C23,C9 | C_0402_1005Metric | C1525
WS2812B-2020 | D1 | LED_WS2812B-2020_PLCC4_2.0x2.0mm | C52917434
TYPE-C-31-M-12 | J1 | USB_C_Receptacle_HRO_TYPE-C-31-M-12 | C165948
LiPo 1S | J2 | JST_PH_S2B-PH-SM4-TB_1x02-1MP_P2.00mm_Horizontal | C295747
AO3401A | Q1 | SOT-23 | C15127
5.1k | R1,R2 | R_0402_1005Metric | C25905
4.7k | R17,R18 | R_0402_1005Metric | C25900
100k | R10,R15,R16,R26 | R_0402_1005Metric | C25741
1M | R13,R14,R27 | R_0402_1005Metric | C26083
10k | R11,R12,R19,R20,R21,R23,R24,R3,R6,R7 | R_0402_1005Metric | C25744
1.5k | R4 | R_0402_1005Metric | C25867
1.8k | R5 | R_0402_1005Metric | C25871
GM-402B | S1,S2 | GM-402B | C99754
POWER | SW1 | SW_SPDT_Shouhan_MSK12C02 | C431540
RESET | SW2 | SW_Push_1P1T_XKB_TS-1187A | C318884
BOOT | SW3 | SW_Push_1P1T_XKB_TS-1187A | C318884
USBLC6-2SC6 | U1 | SOT-23-6 | C7519
BQ24073RGTR | U2 | VQFN-16-1EP_3x3mm_P0.5mm_EP1.6x1.6mm | C15220
AP2112K-3.3 | U3 | SOT-23-5 | C51118
ME6211C28 | U4 | SOT-23-5 | C53099
ESP32-S3-MINI-1-N8 | U5 | ESP32-S2-MINI-1 | C2913206
ADS1115IDGSR | U6 | MSOP-10_3x3mm_P0.5mm | C37593
SHT40-AD1B | U7 | Sensirion_DFN-4_1.5x1.5mm_P0.8mm_SHT4x_NoCentralPad | C2909890

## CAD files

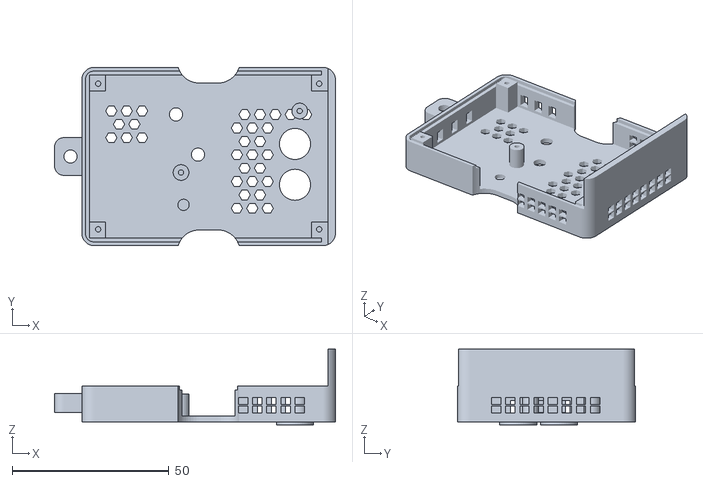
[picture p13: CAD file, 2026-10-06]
hardware/enclosure/stl/revb_v2_front.stl
89.5 x 56.8 x 24.2

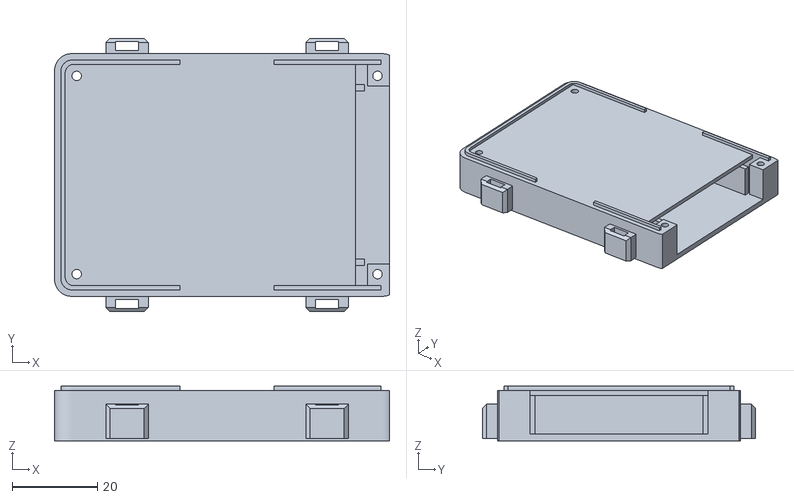
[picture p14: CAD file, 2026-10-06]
hardware/enclosure/stl/revb_v2_back.stl
78.4 x 64.0 x 12.8

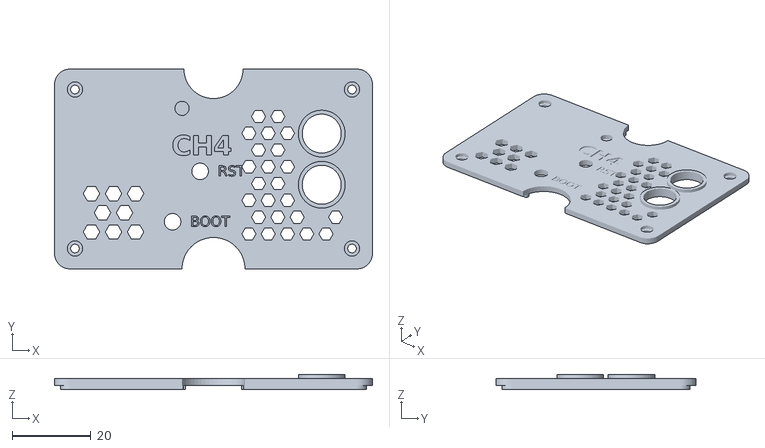
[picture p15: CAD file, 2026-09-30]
hardware/enclosure/stl/revb_lid.stl
80.8 x 50.8 x 3.79

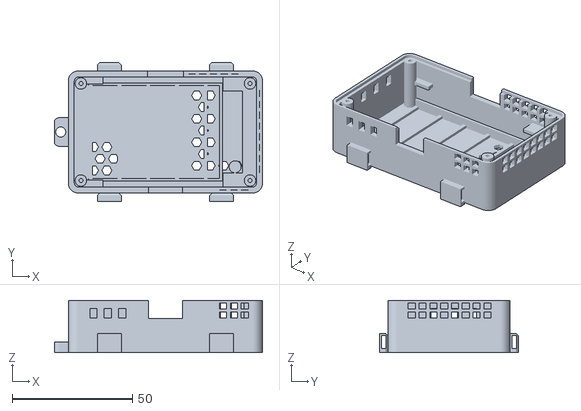
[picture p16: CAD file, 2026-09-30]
hardware/enclosure/stl/revb_base.stl
86.6 x 58.0 x 21.7

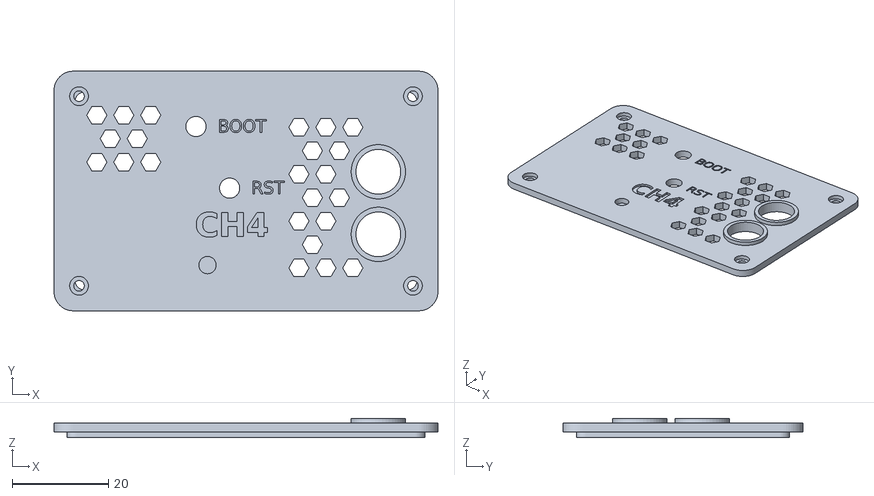
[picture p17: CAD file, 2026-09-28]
hardware/enclosure/stl/lid.stl
79.8 x 49.8 x 3.99

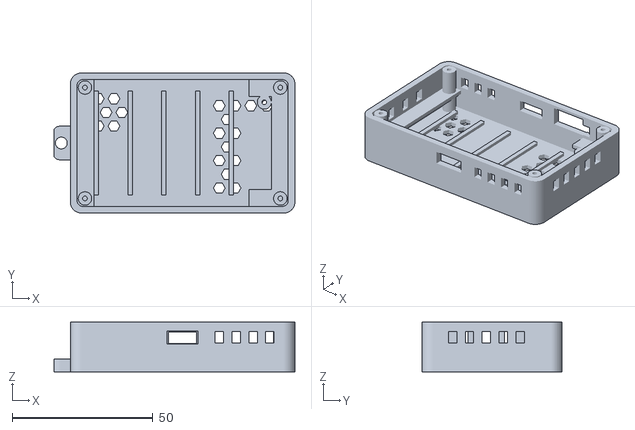
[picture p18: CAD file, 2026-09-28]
hardware/enclosure/stl/base.stl
85.6 x 49.8 x 17.7

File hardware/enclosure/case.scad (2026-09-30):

// Handheld enclosure for the rev C phone-companion board (60 x 33 mm).
//
//   part = "base" | "lid" | "assembly"   (set on the command line: -D part=\"lid\")
//
// Design notes
//   - The two Figaro sensor cans poke through collars in the lid, so the hot
//     elements sit in open air: that is what makes the response fast.
//   - Air enters through the floor vents, rises past the sensors (they run at
//     ~280 mW each) and leaves through the lid grille: a chimney, not a sealed box.
//   - The SHT40 end has its own vents top and bottom so it measures outside air,
//     not case air.
//   - Battery lies under the board on the floor. Sized for the Pi Hut 2000 mAh
//     cell (60 x 38 x 8 mm); a 1200 mAh cell (~60 x 35 x 5 mm) also fits.
//   - The board rests on a ledge; one M2 screw at its right-hand hole stops it
//     lifting. Four M2 screws hold the lid down.
//
// Printing (Bambu A1, 0.4 mm nozzle): PETG or ASA preferred (the board runs warm
// and PLA creeps); 0.2 mm layers, 3 walls, 20 % infill. Both parts print flat,
// no supports. See README.md.

/* [Board] */
board_x = 60;           // board outline
board_y = 33;
board_t = 1.6;          // set 1.0 if you order 1.0 mm boards
board_r = 2;            // board corner radius
board_clear = 4.5;      // gap from board edge to wall (leaves room for the corner screw posts)

/* [Cavity] */
wall = 2.4;             // outer wall
floor_t = 1.6;
lid_t = 1.8;
batt_h = 8.5;           // battery pocket height (Pi Hut 2000 mAh cell is 8 mm; was 5.5 for a 1200 mAh)
board_gap = 2.0;        // clearance under the board (solder joints, battery bulge)
above_board = 7.0;      // clear height above the board (JST plug is the tallest part)
corner_r = 4;           // outer corner radius
post_r = 2.4;           // lid screw posts
screw_pilot = 1.7;      // M2 self-tapping pilot hole
screw_head = 3.9;       // M2 head counterbore in the lid
screw_clear = 2.2;      // M2 clearance hole in the lid

/* [Parts on the board] (x, y from the board's top-left corner, KiCad coords) */
s1 = [56.5, 6.5];       // CH4 sensor can centre (overhangs the board edge by ~1 mm)
s2 = [56.5, 18.5];      // LPG sensor can centre
can_d = 9.4;            // sensor flange diameter (9.2 max) - stays under the lid
cap_d = 8.3;            // sensor cap diameter (8.1 max) - passes through the collar
can_h = 13.0;           // can height above the board
usb = [24.0, 33.0];     // USB-C mouth, bottom edge, beside the module
usb_w = 10.0;
usb_h = 4.0;
sw1 = [38.0, 0.0];      // power slide switch, lever over the top edge
sw1_w = 11.0;
sw1_h = 4.6;
bat_conn = [25.3, 0.0]; // JST-PH, opening faces the top edge, beside the module
bat_w = 13.0;
btn_rst = [34.4, 21.9];
btn_boot = [34.4, 29.0];
btn_d = 4.2;            // poke-through hole (press with a pen)
led = [31.8, 2.3];      // status LED
led_d = 3.6;
led_window = 0.4;       // thin printed diffuser over the LED
mount = [56.5, 30.0];   // board mounting hole that gets a screw (H1) - see README: now under the cell
sht = [6.0, 29.0];      // SHT40 - vented top and bottom so it reads outside air

/* [Derived] */
cav_x = board_x + 2*board_clear;
cav_y = board_y + 2*board_clear;
cav_h = batt_h + board_gap + board_t + above_board;
out_x = cav_x + 2*wall;
out_y = cav_y + 2*wall;
base_h = floor_t + cav_h;
board_z = floor_t + batt_h + board_gap;      // underside of the board
shelf_d = 6.0;          // how far the end shelves reach in under the board
shelf_t = 1.5;
eps = 0.01;
$fn = 48;

// Board coords -> case coords (the board sits centred in the cavity)
function bx(x) = wall + board_clear + x;
function by(y) = wall + board_clear + y;

module rrect(x, y, r, h) {
    linear_extrude(h) offset(r = r) offset(r = -r) square([x, y]);
}

// Hex grille: airflow with enough bridging for a clean print
module hex_vents(x0, y0, x1, y1, z0, h, d = 4.2, gap = 1.4) {
    p = d + gap;
    keep = (cap_d + 3.0) / 2 + d / 2 + 0.8;   // stay off the sensor collars
    for (j = [0 : floor((y1 - y0) / (p * 0.87))])
        for (i = [0 : floor((x1 - x0) / p)]) {
            cx = x0 + i * p + (j % 2) * p / 2;
            cy = y0 + j * p * 0.87;
            clash = min(norm([cx, cy] - [bx(s1[0]), by(s1[1])]),
                        norm([cx, cy] - [bx(s2[0]), by(s2[1])])) < keep;
            if (cx <= x1 && cy <= y1 && !clash)
                translate([cx, cy, z0]) cylinder(h = h, d = d, $fn = 6);
        }
}

module lanyard_loop() {
    // Tab on the left-hand short edge, away from the sensors
    difference() {
        translate([-6.5, out_y/2 - 6, 0]) rrect(9, 12, 3, 4.5);
        translate([-3.2, out_y/2, -eps]) cylinder(h = 10, d = 4.2);
        translate([-9, out_y/2 - 8, -eps]) cube([3.2, 16, 10]);  // blend into the wall
    }
}

module base() {
    difference() {
        union() {
            rrect(out_x, out_y, corner_r, base_h);
            lanyard_loop();
        }
        // main cavity
        translate([wall, wall, floor_t]) rrect(cav_x, cav_y, 2, cav_h + eps);

        // floor vents: under the sensors (chimney inlet) and under the SHT40
        hex_vents(bx(40), by(2), bx(58), by(30), -eps, floor_t + 2*eps);
        hex_vents(bx(3), by(23), bx(14), by(32), -eps, floor_t + 2*eps);

        // Wall louvres at board level: the cell covers most of the floor, so this
        // is where the air really comes in. Sensor end and SHT40 end.
        for (y = [4, 10, 16, 22, 28])                       // right end wall
            translate([out_x - wall - eps, by(y) - 1.5, board_z + 1.2])
                cube([wall + 2*eps, 3, 4.0]);
        for (y = [8, 16, 24])                               // left end wall (SHT40)
            translate([-eps, by(y) - 1.5, board_z + 1.2])
                cube([wall + 2*eps, 3, 4.0]);
        for (x = [42, 48, 54])                              // top wall, sensor end
            translate([bx(x) - 1.5, -eps, board_z + 1.2])
                cube([3, wall + 2*eps, 4.0]);
        for (x = [45, 51, 57])                              // bottom wall, sensor end
            translate([bx(x) - 1.5, out_y - wall - eps, board_z + 1.2])
                cube([3, wall + 2*eps, 4.0]);
        for (x = [3, 9, 15])                                // bottom wall, SHT40 end
            translate([bx(x) - 1.5, out_y - wall - eps, board_z + 1.2])
                cube([3, wall + 2*eps, 4.0]);

        // USB-C (bottom wall), power switch and battery plug (both top wall)
        translate([bx(usb[0]) - usb_w/2, out_y - wall - eps, board_z + board_t - 0.6])
            cube([usb_w, wall + 2*eps, usb_h]);
        translate([bx(sw1[0]) - sw1_w/2, -eps, board_z + board_t - 0.8])
            cube([sw1_w, wall + 2*eps, sw1_h]);
        translate([bx(bat_conn[0]) - bat_w/2, -eps, board_z + board_t - 0.6])
            cube([bat_w, wall + 2*eps, 6.5]);
    }

    // lid screw posts in the cavity corners
    for (p = post_xy()) translate([p[0], p[1], floor_t])
        difference() {
            cylinder(h = cav_h, r = post_r);
            translate([0, 0, cav_h - 7]) cylinder(h = 7 + eps, d = screw_pilot);
        }

    // board support boss at the H1 mounting hole (clear of the battery)
    translate([bx(mount[0]), by(mount[1]), floor_t]) difference() {
        cylinder(h = board_z - floor_t, d = 5);
        translate([0, 0, -eps]) cylinder(h = 10, d = screw_pilot);
    }

    // Board shelves on the two short walls: the board lands on these, and the
    // battery slides in underneath between them.
    for (m = [0, 1]) translate([m ? out_x - wall - shelf_d : wall, wall, board_z - shelf_t])
        cube([shelf_d, cav_y, shelf_t]);
    // extra stubs on the long walls at the sensor end, where the cell does not reach
    for (m = [0, 1]) translate([out_x - wall - 14, m ? out_y - wall - shelf_d : wall, board_z - shelf_t])
        cube([10, shelf_d, shelf_t]);

    // battery pocket ribs (keep the cell off the floor vents and clear of the H1 boss)
    for (x = [6 : 12 : 54]) translate([wall + x, wall + 4, floor_t - 0.6])
        cube([1.6, cav_y - 8, 1.8]);   // sunk into the floor: crosses the vents cleanly
}

// Posts sit in the cavity corners, clear of the board's rounded corners
function post_xy() = [
    [wall + post_r + 0.4, wall + post_r + 0.4],
    [out_x - wall - post_r - 0.4, wall + post_r + 0.4],
    [wall + post_r + 0.4, out_y - wall - post_r - 0.4],
    [out_x - wall - post_r - 0.4, out_y - wall - post_r - 0.4],
];
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

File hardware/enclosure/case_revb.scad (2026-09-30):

// Handheld enclosure for the rev B phone-companion board (66 x 36 mm, the
// boards fabricated in September 2026).
//
//   part = "base" | "lid" | "assembly"   (set on the command line: -D part=\"lid\")
//
// Design notes
//   - The two Figaro sensor cans poke through collars in the lid, so the hot
//     elements sit in open air: that is what makes the response fast.
//   - The case is a chimney: air in through two rows of wall louvres on three
//     sides of the sensor end and the floor vents, up past the sensors, out
//     through a dense hex grille that surrounds the collars.
//   - Four zip-tie eyelets on the long walls; the power switch sits in an open
//     notch with a thumb scallop in the lid.
//   - The SHT40 end has its own vents top and bottom so it measures outside air.
//   - Battery (Pi Hut 2000 mAh, 60 x 38 x 8 mm) sits in a fenced pocket on the
//     floor at the SHT40 end, clear of the H1 screw boss and of the board supports.
//   - The board rests on a shelf at the sensor end and stubs along the long
//     walls; one M2 screw at its right-hand hole stops it lifting. Four M2
//     screws hold the lid down. The lid's lip sits in a rebate in the wall top.
//
// Printing (Bambu A1, 0.4 mm nozzle): PETG or ASA preferred (the board runs warm
// and PLA creeps); 0.2 mm layers, 3 walls, 20 % infill. Both parts print flat,
// no supports: the base floor down, the lid top face down (collars and lip
// print upward). See README.md.

/* [Board] */
board_x = 66;           // board outline
board_y = 36;
board_t = 1.6;          // set 1.0 if you order 1.0 mm boards
board_r = 2;            // board corner radius
board_clear = 5.0;      // gap from board edge to wall: the corner screw posts reach 5.2 mm in, so this
                        // leaves ~1.3 mm between a post and the board's rounded corner (was 4.5: too tight printed)

/* [Cavity] */
wall = 2.4;             // outer wall
floor_t = 1.6;
lid_t = 1.8;
batt_h = 9.5;           // battery pocket height: 8 mm cell + 1.2 mm floor ribs + clearance under the board supports
batt_l = 60;            // Pi Hut 2000 mAh cell, 60 x 38 x 8 mm
batt_w = 38;
fit = 0.3;              // printed-fit clearance used for the cell pocket and the lid lip
board_gap = 2.0;        // clearance under the board (solder joints, battery bulge)
above_board = 7.0;      // clear height above the board (JST plug is the tallest part)
corner_r = 4;           // outer corner radius
post_r = 2.4;           // lid screw posts
screw_pilot = 1.7;      // M2 self-tapping pilot hole
screw_head = 3.9;       // M2 head counterbore in the lid
screw_clear = 2.2;      // M2 clearance hole in the lid

/* [Parts on the board] (x, y from the board's top-left corner, KiCad coords) */
s1 = [60.5, 9.0];       // CH4 sensor can centre
s2 = [60.5, 22.0];      // LPG sensor can centre
can_d = 9.4;            // sensor flange diameter (9.2 max) - stays under the lid
cap_d = 8.3;            // sensor cap diameter (8.1 max) - passes through the collar
cap_clear = 1.6;        // collar hole = cap_d + cap_clear (printed holes come out ~0.3 mm small)
can_h = 13.0;           // can height above the board
usb = [33.0, 36.0];     // USB-C mouth, bottom edge
usb_w = 14.0;           // width of the open USB-C notch (plug overmoulds are ~8.5 x 3.5 mm; chunky ones ~12)
sw1 = [33.0, 0.0];      // power slide switch, lever over the top edge
sw1_w = 11.0;
sw1_h = 4.6;
bat_conn = [50.0, 30.0];// JST-PH, faces the bottom edge (internal: no wall opening)
btn_rst = [29.6, 18.6];
btn_boot = [22.6, 31.4];
btn_d = 4.2;            // poke-through hole (press with a pen)
led = [25.0, 2.6];      // status LED
led_d = 3.6;
led_window = 0.4;       // thin printed diffuser over the LED
mount = [62.0, 32.5];   // board mounting hole that gets a screw (H1)
sht = [8.5, 30.0];      // SHT40 - vented top and bottom so it reads outside air


/* [Derived] */
cav_x = board_x + 2*board_clear;
cav_y = board_y + 2*board_clear;
cav_h = batt_h + board_gap + board_t + above_board;
out_x = cav_x + 2*wall;
out_y = cav_y + 2*wall;
base_h = floor_t + cav_h;
board_z = floor_t + batt_h + board_gap;      // underside of the board
shelf_d = 6.0;          // how far the end shelves reach in under the board
shelf_t = 1.5;
eps = 0.01;
$fn = 48;

// Board coords -> case coords (the board sits centred in the cavity). KiCad's y
// runs DOWN the board as drawn; the model's y runs up, so y is flipped here.
// Without that flip the sensor holes and the wall openings come out mirrored
// (the first print did).
function bx(x) = wall + board_clear + x;
function by(y) = wall + board_clear + (board_y - y);
// Which wall a KiCad edge lands on after the flip:
//   KiCad top edge (y = 0)        -> the model's high-y wall (out_y side)
//   KiCad bottom edge (y = 36)    -> the model's low-y wall (y = 0 side)

module rrect(x, y, r, h) {
    linear_extrude(h) offset(r = r) offset(r = -r) square([x, y]);
}

// Hex grille: airflow with enough bridging for a clean print
module hex_vents(x0, ya, x1, yb, z0, h, d = 4.2, gap = 1.4) {
    y0 = min(ya, yb);   // callers pass board-y limits through by(), which flips them
    y1 = max(ya, yb);
    p = d + gap;
    keep = (cap_d + cap_clear + 2.0) / 2 + d / 2 + 0.8;   // stay off the sensor collars
    for (j = [0 : floor((y1 - y0) / (p * 0.87))])
        for (i = [0 : floor((x1 - x0) / p)]) {
            cx = x0 + i * p + (j % 2) * p / 2;
            cy = y0 + j * p * 0.87;
            clash = min(norm([cx, cy] - [bx(s1[0]), by(s1[1])]),
                        norm([cx, cy] - [bx(s2[0]), by(s2[1])])) < keep;
            if (cx <= x1 && cy <= y1 && !clash)
                translate([cx, cy, z0]) cylinder(h = h, d = d, $fn = 6);
        }
}

module lanyard_loop() {
    // Tab on the left-hand short edge, away from the sensors
    difference() {
        translate([-6.5, out_y/2 - 6, 0]) rrect(9, 12, 3, 4.5);
        translate([-3.2, out_y/2, -eps]) cylinder(h = 10, d = 4.2);
        translate([-9, out_y/2 - 8, -eps]) cube([3.2, 16, 10]);  // blend into the wall
    }
}

// Zip-tie eyelets: four tunnels along the long walls at floor level, a tie
// runs through each parallel to the wall (5 mm wide ties), so the case can be
// strapped to a pole, a pack strap or a handlebar.
tie_len = 10; tie_proud = 3.6; tie_h = 8.0;
module tie_eyelets() {
    for (m = [0, 1]) for (x = [12, out_x - 12 - tie_len])
        translate([x, m ? out_y - eps : -tie_proud + eps, 0]) difference() {
            hull() {   // rounded outer face
                cube([tie_len, tie_proud - 1, tie_h]);
                translate([1, 0, 0]) cube([tie_len - 2, tie_proud, tie_h - 1]);
            }
            translate([-1, 0.8, 1.6]) cube([tie_len + 2, 2.0, 5.4]);   // slot 2.0 x 5.4
        }
}

module base() {
    difference() {
        union() {
            rrect(out_x, out_y, corner_r, base_h);
            lanyard_loop();
            tie_eyelets();
        }
        // main cavity
        translate([wall, wall, floor_t]) rrect(cav_x, cav_y, 2, cav_h + eps);

        // floor vents: under the sensors (chimney inlet) and under the SHT40
        hex_vents(bx(46), by(2), bx(64), by(32), -eps, floor_t + 2*eps);
        hex_vents(bx(3), by(24), bx(14), by(34), -eps, floor_t + 2*eps);

        // Wall louvres at board level: the cell covers most of the floor, so this
        // is where the air really comes in. Sensor end and SHT40 end.
        for (y = [2 : 4.5 : 34])                            // right end wall: two rows
            for (z = [board_z + 1.2, board_z + board_t + 3.4])
                translate([out_x - wall - eps, by(y) - 1.5, z])
                    cube([wall + 2*eps, 3, 2.6]);
        for (y = [8, 16, 24])                               // left end wall (SHT40)
            translate([-eps, by(y) - 1.5, board_z + 1.2])
                cube([wall + 2*eps, 3, 4.0]);
        for (x = [44 : 4.5 : 66])                           // KiCad top edge (switch side): two rows, sensor end
            for (z = [board_z + 1.2, board_z + board_t + 3.4])
                translate([bx(x) - 1.5, out_y - wall - eps, z])
                    cube([3, wall + 2*eps, 2.6]);
        for (x = [57 : 4.5 : 66])                           // KiCad bottom edge (USB side), sensor end, clear of the JST opening
            for (z = [board_z + 1.2, board_z + board_t + 3.4])
                translate([bx(x) - 1.5, -eps, z])
                    cube([3, wall + 2*eps, 2.6]);
        for (x = [3, 9, 15])                                // KiCad bottom edge, SHT40 end
            translate([bx(x) - 1.5, -eps, board_z + 1.2])
                cube([3, wall + 2*eps, 4.0]);
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

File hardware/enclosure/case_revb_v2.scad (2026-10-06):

// Two-part enclosure for the rev B phone-companion board (66 x 36 mm): a FRONT
// shell the board screws into, sensors through its face, and a BACK tray that
// carries the battery in its own pocket.
//
//   part = "front" | "back" | "assembly" | "section"   (-D part=\"back\")
//
// How it goes together
//   - FRONT: the sensor cans poke through collars in the face. Two bosses stand
//     off the inside of the face at the board's H1 and H2 holes; the board goes
//     in component side first and two M2 x 5 screws through the board pull it
//     onto them. USB-C and the power switch sit in notches that are open to the
//     back edge of the shell, so they are reachable with the tray off, and the
//     tray's rim closes them when fitted.
//   - BACK: a tray with a closed battery compartment: floor, side fences, an
//     end fence at the SHT40 end, and a DIVIDER plate over the top that
//     separates the cell (Pi Hut 2000 mAh, 60 x 38 x 8 mm) from the board. The
//     compartment is open at the sensor end, a full-width slot, and the cell
//     slides in through it like a drawer. The divider stops 8 mm short of that
//     end so the lead can come up out of the slot to the board's JST. The front
//     shell's sensor-end wall carries a SKIRT that reaches down over the open
//     end, so once the tray is screwed on the slot is closed and the cell
//     cannot come out. The tray's rim carries a lip that drops into a rebate at
//     the back edge of the front shell on the other three sides; four M2 screws
//     through the tray's corner posts go into the shell's posts.
//   - Air: louvres in the front shell's walls at component level on three sides
//     of the sensor end, a hex grille in the face around the collars, and a
//     grille at the SHT40 end. The battery compartment is closed.
//
// Printing (Bambu A1, 0.4 mm nozzle): PETG or ASA; 0.2 mm layers, 3 walls,
// 20 % infill. FRONT prints face down (collars and lettering against the plate,
// posts and bosses rise). BACK prints outer face down. No supports.
//
// Coordinates: every board position is in KiCad coordinates (origin top-left,
// y DOWN the board). The FRONT is modelled with its outer face at z = 0 and
// depth in +z, so the board lies component side DOWN, facing the face. Turned
// over about its x axis, KiCad y then runs the same way as the model's y (see
// bx/by below), which is the opposite of the component-side-up box case. The
// BACK is modelled the same way, outer face at z = 0; "assembly" flips it over
// onto the front.

/* [Board] */
board_x = 66;           // board outline
board_y = 36;
board_t = 1.6;
board_r = 2;            // board corner radius
board_clear = 5.0;      // gap from board edge to end walls (corner posts reach 5.2 mm in)
board_clear_y = 8.0;    // gap from board edge to the long walls: wider, so the 38 mm cell
                        // passes BETWEEN the open-end corner blocks on its way into the
                        // compartment (blocks reach 5.2 mm in from each long wall)
hole1 = [62.0, 32.5];   // H1 (M2)
hole2 = [24.2, 12.9];   // H2 (M2)

/* [Shell] */
wall = 2.4;
front_t = 1.8;          // front face
back_t = 1.6;           // back skin
above_board = 7.0;      // face inner surface to the component side of the board (JST plug 6 mm)
below_board = 1.0;      // solder side to the shell's back edge
corner_r = 4;
post_r = 2.4;           // corner screw posts
screw_pilot = 1.7;      // M2 self-tapping pilot
screw_clear = 2.2;
screw_head = 4.6;       // counterbore for an M2 pan head, wide enough for the driver shaft
under_head = 2.5;       // plastic left under the screw head in the tray: with M2 x 8 that leaves
                        // 5.5 mm of thread into the front shell's posts
fit = 0.3;              // printed-fit clearance (lip, pocket)

/* [Battery] */
batt_l = 60;            // Pi Hut 2000 mAh: 60 x 38 x 8 mm
batt_w = 38;
batt_h = 8;
batt_fit = 0.6;         // play around the cell in the compartment (was 0.3: too tight printed);
                        // plus lead_room (below) at the lead end
pocket_h = batt_h + 1.0;// compartment height under the divider: 1 mm over the cell
fence_t = 1.6;
divider_t = 1.2;        // plate between the cell and the board
lead_gap = 8.0;         // the divider stops this far short of the open end: the lead comes up here
skirt_t = wall;         // the front shell's sensor-end wall continues down over the tray's open end

/* [Parts on the board] (KiCad coords) */
s1 = [60.5, 9.0];       // CH4 sensor can centre
s2 = [60.5, 22.0];      // LPG sensor can centre
can_d = 9.4;            // sensor flange diameter (stays inside)
cap_d = 8.3;            // sensor cap diameter - passes through the collar
cap_clear = 1.6;        // collar hole = cap_d + cap_clear
can_h = 13.0;           // can height above the board
usb = [33.0, 36.0];     // USB-C, KiCad bottom edge
usb_w = 14.0;           // width of the open notch
usb_body_h = 3.3;       // socket height above the board
sw1 = [33.0, 0.0];      // power slide switch, KiCad top edge
sw1_w = 11.0;
sw1_h = 4.6;
btn_rst = [29.6, 18.6];
btn_boot = [22.6, 31.4];
btn_d = 4.2;
led = [25.0, 2.6];
led_d = 3.6;
led_window = 0.4;       // diffuser membrane left in the face
sht = [8.5, 30.0];      // SHT40, vented

/* [Derived] */
cav_x = board_x + 2*board_clear;
cav_y = board_y + 2*board_clear_y;
out_x = cav_x + 2*wall;
out_y = cav_y + 2*wall;
front_depth = front_t + above_board + board_t + below_board;   // 11.4
back_depth = back_t + pocket_h + divider_t;                      // 11.3
tray_x = out_x - skirt_t;                                        // the tray stops short at the sensor end; the skirt fills it
z_board = front_t + above_board;                                 // component side of the board (from the face)
eps = 0.01;
$fn = 48;

// The board lies COMPONENT SIDE DOWN in the front shell: the box-and-lid case
// had it component side up, and turning it over reverses one axis. It is
// turned about its x axis (sensor end stays at high x), so KiCad y now runs
// the same way as the model's y: KiCad top edge (switch) -> LOW-y wall,
// KiCad bottom edge (USB-C, JST) -> HIGH-y wall. CH4 (S1, y = 9) is the
// lower of the two collars.
function bx(x) = wall + board_clear + x;
function by(y) = wall + board_clear_y + y;
function post_xy() = [
    [wall + post_r + 0.4, wall + post_r + 0.4],
    [out_x - wall - post_r - 0.4, wall + post_r + 0.4],
    [wall + post_r + 0.4, out_y - wall - post_r - 0.4],
    [out_x - wall - post_r - 0.4, out_y - wall - post_r - 0.4],
];
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

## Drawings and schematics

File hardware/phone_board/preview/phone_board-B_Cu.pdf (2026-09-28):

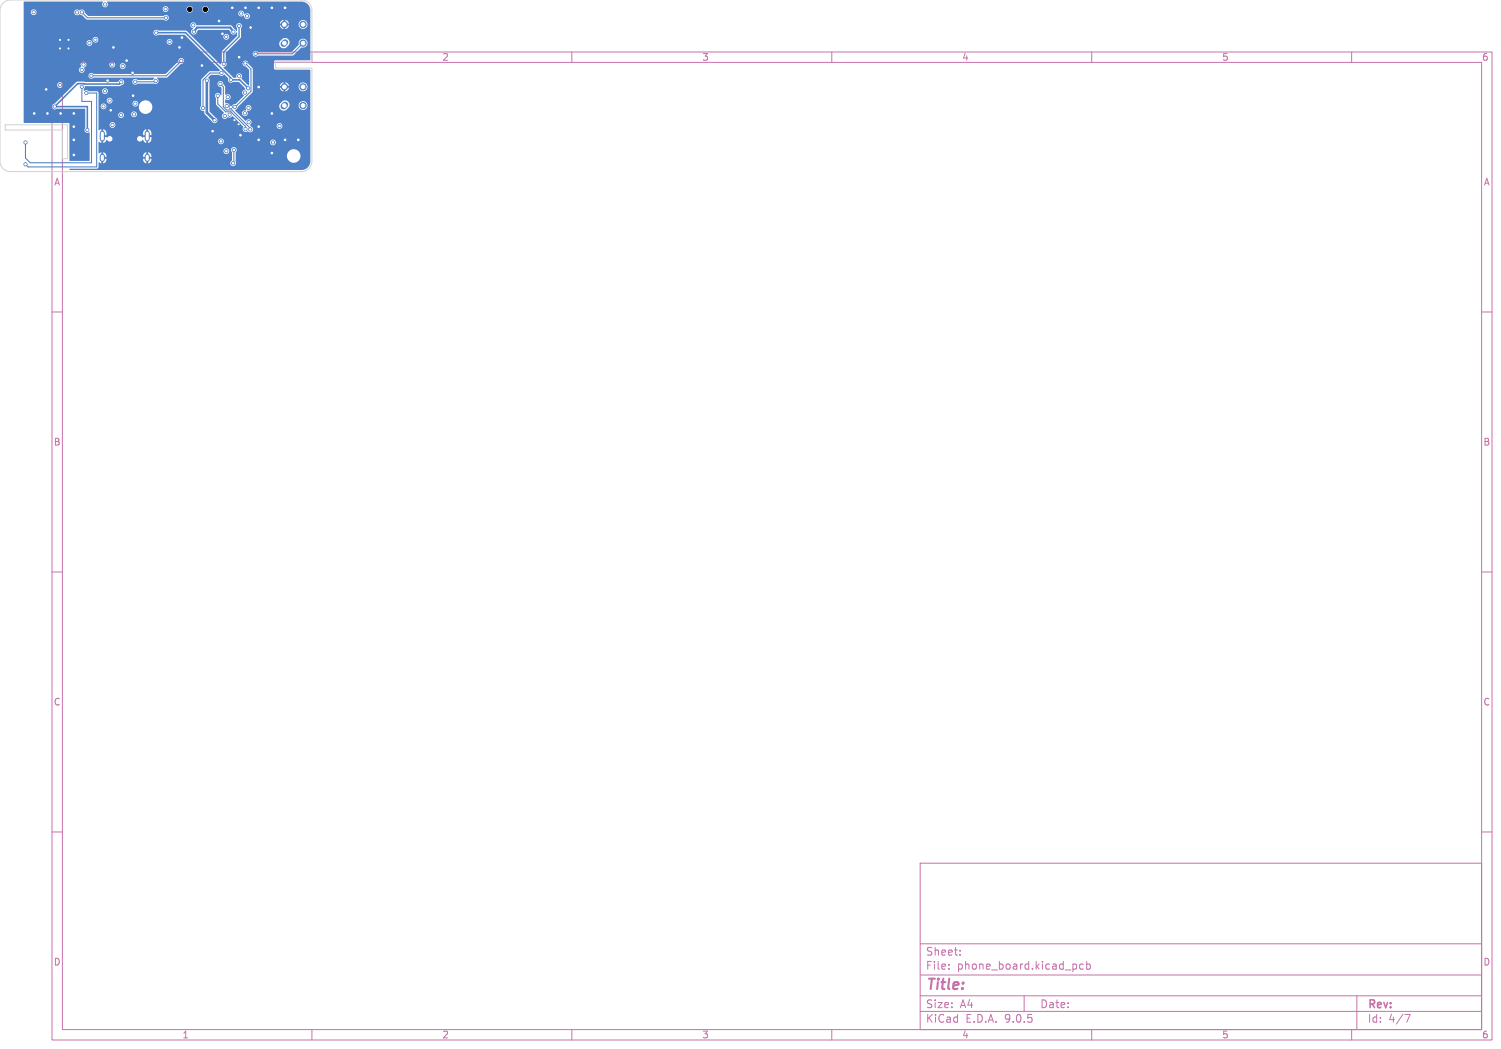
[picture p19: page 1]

Id: 4/7 Title: File: phone_board.kicad_pcb Sheet:

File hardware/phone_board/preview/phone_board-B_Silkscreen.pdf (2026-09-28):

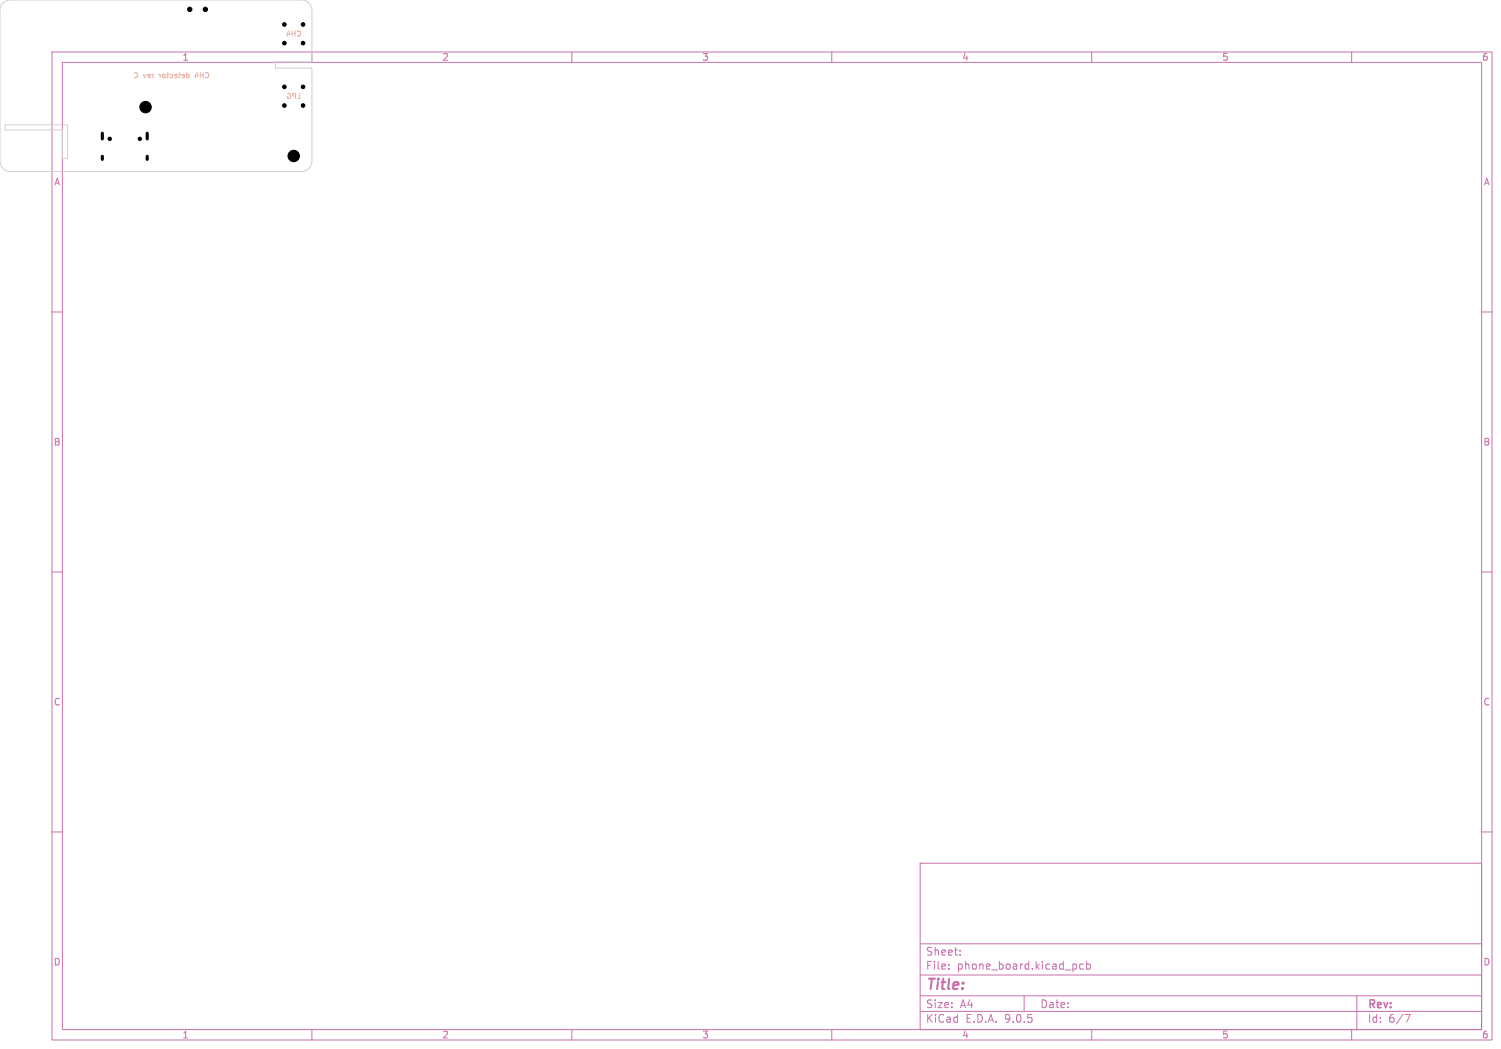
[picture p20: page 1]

Id: 6/7 Title: File: phone_board.kicad_pcb Sheet:

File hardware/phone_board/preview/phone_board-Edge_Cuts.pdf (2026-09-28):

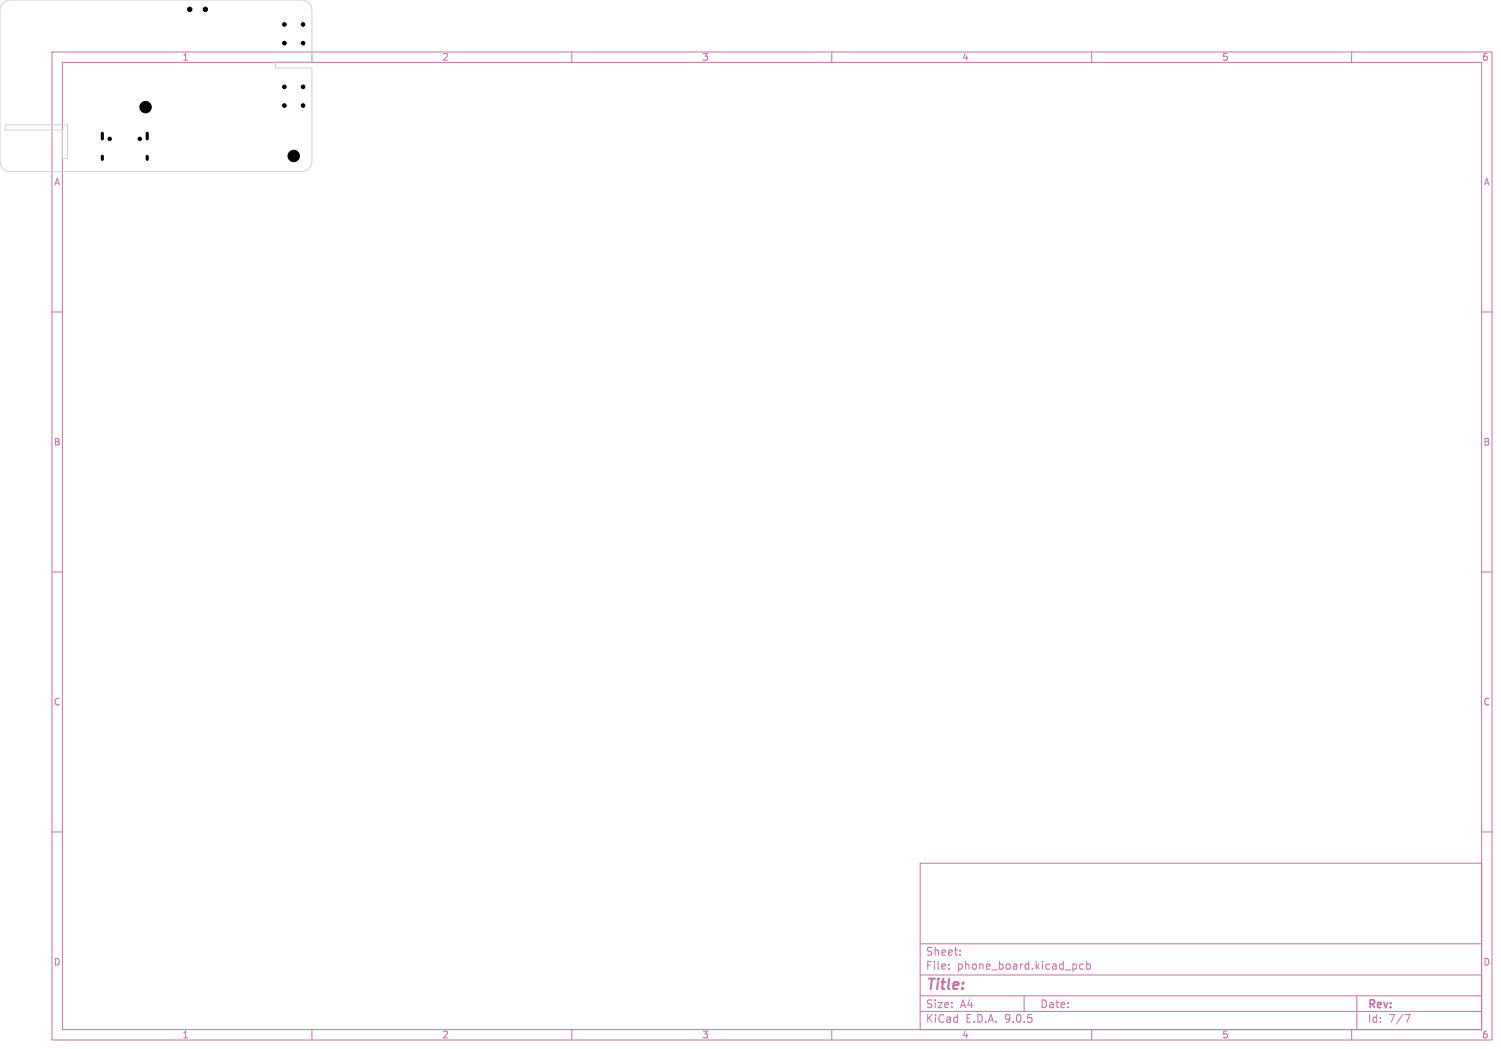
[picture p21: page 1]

Id: 7/7 Title: File: phone_board.kicad_pcb Sheet:

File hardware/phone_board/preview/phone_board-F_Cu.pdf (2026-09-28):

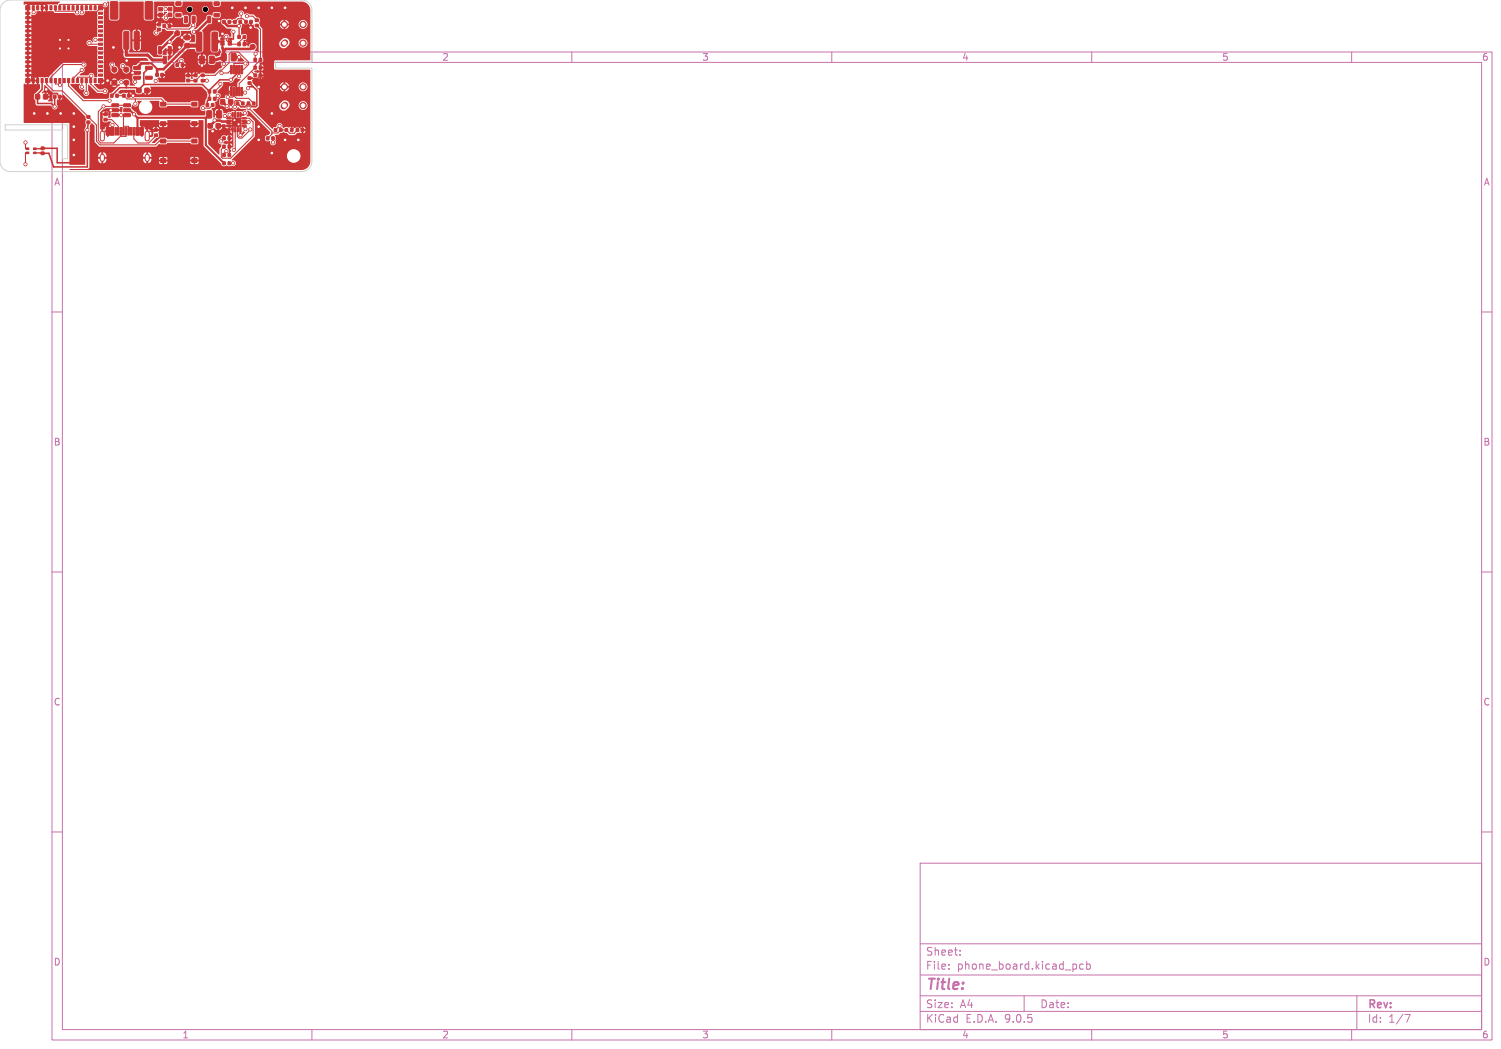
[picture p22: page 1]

Id: 1/7 Title: File: phone_board.kicad_pcb Sheet:

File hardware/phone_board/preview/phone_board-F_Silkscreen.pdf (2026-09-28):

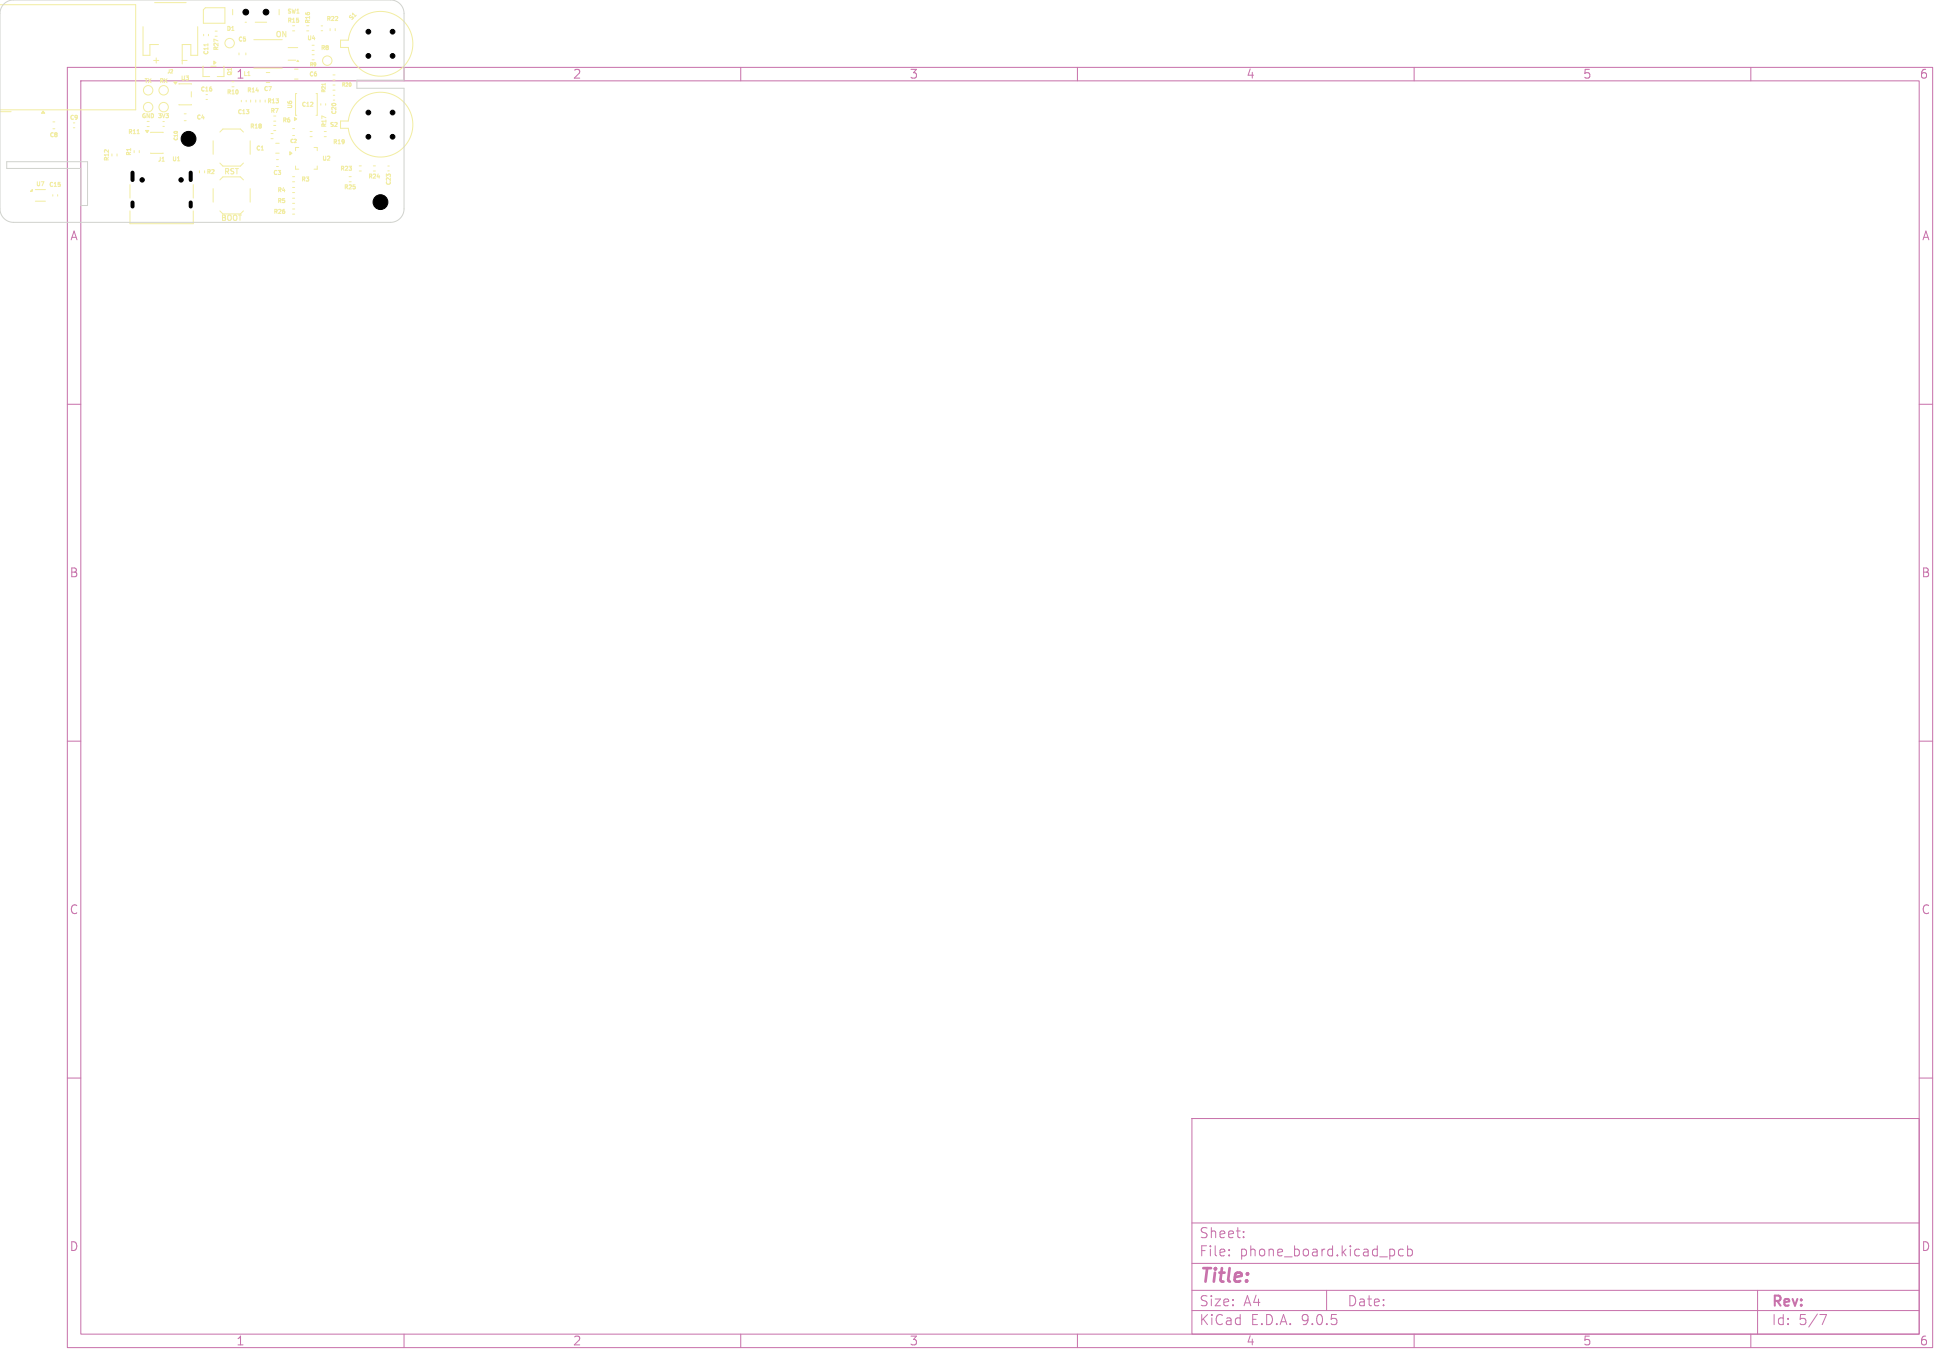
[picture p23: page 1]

Id: 5/7 Title: File: phone_board.kicad_pcb Sheet:

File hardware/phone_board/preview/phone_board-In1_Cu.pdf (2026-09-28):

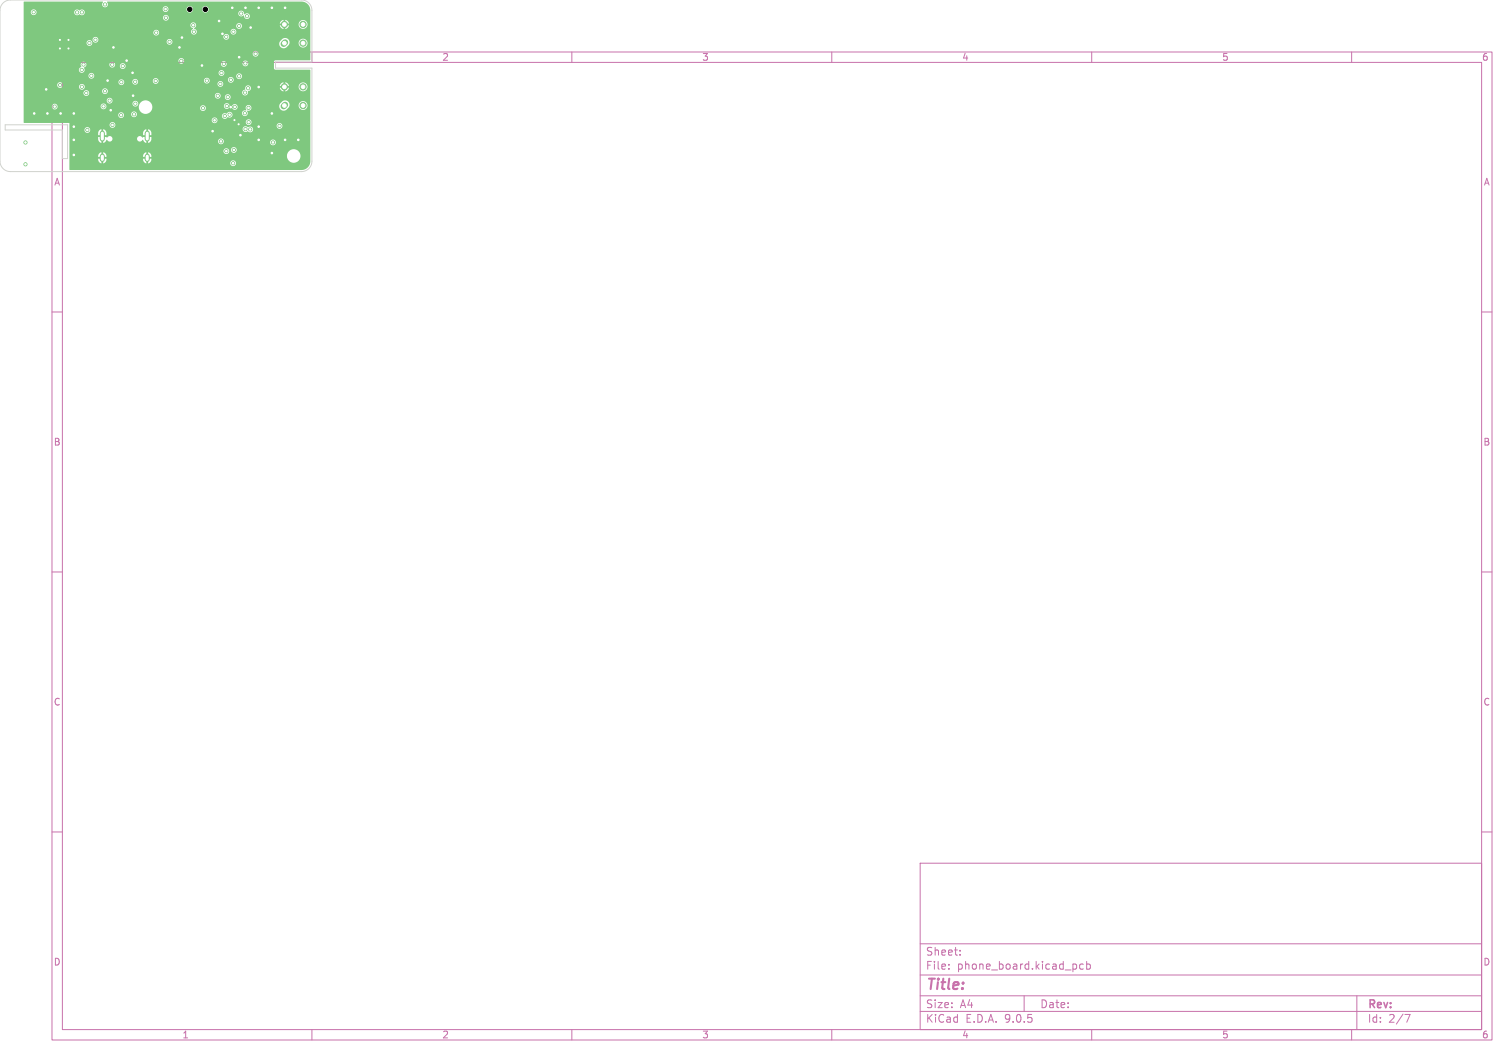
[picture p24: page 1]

Id: 2/7 Title: File: phone_board.kicad_pcb Sheet:

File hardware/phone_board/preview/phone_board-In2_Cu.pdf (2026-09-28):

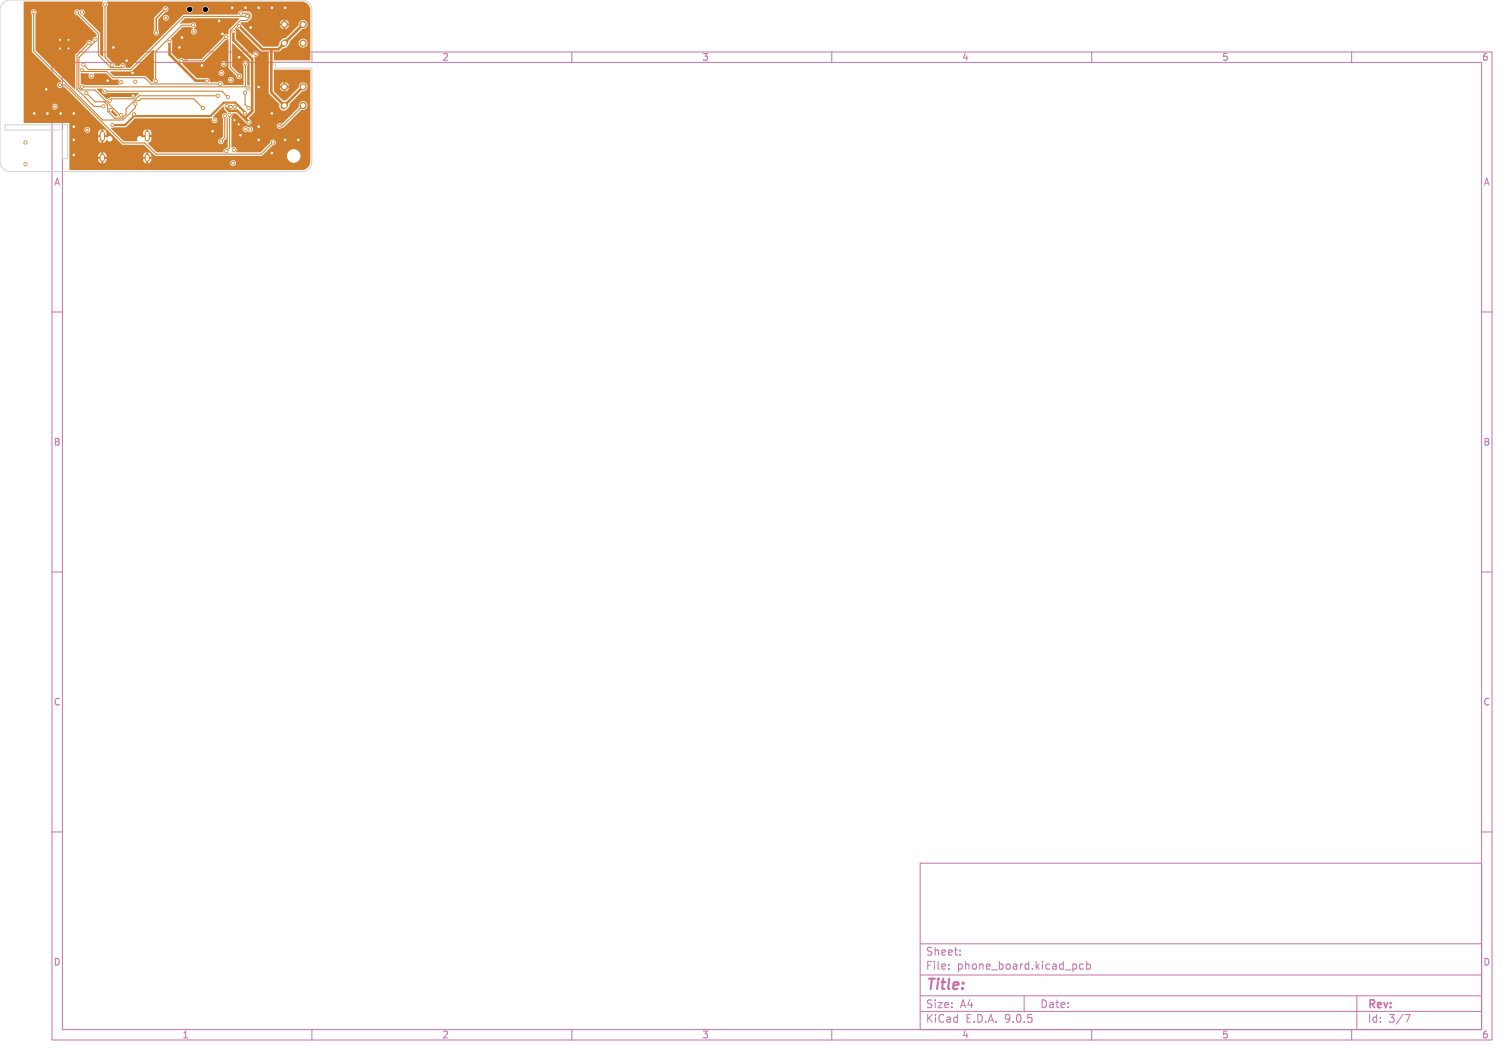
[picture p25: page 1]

Id: 3/7 Title: File: phone_board.kicad_pcb Sheet:

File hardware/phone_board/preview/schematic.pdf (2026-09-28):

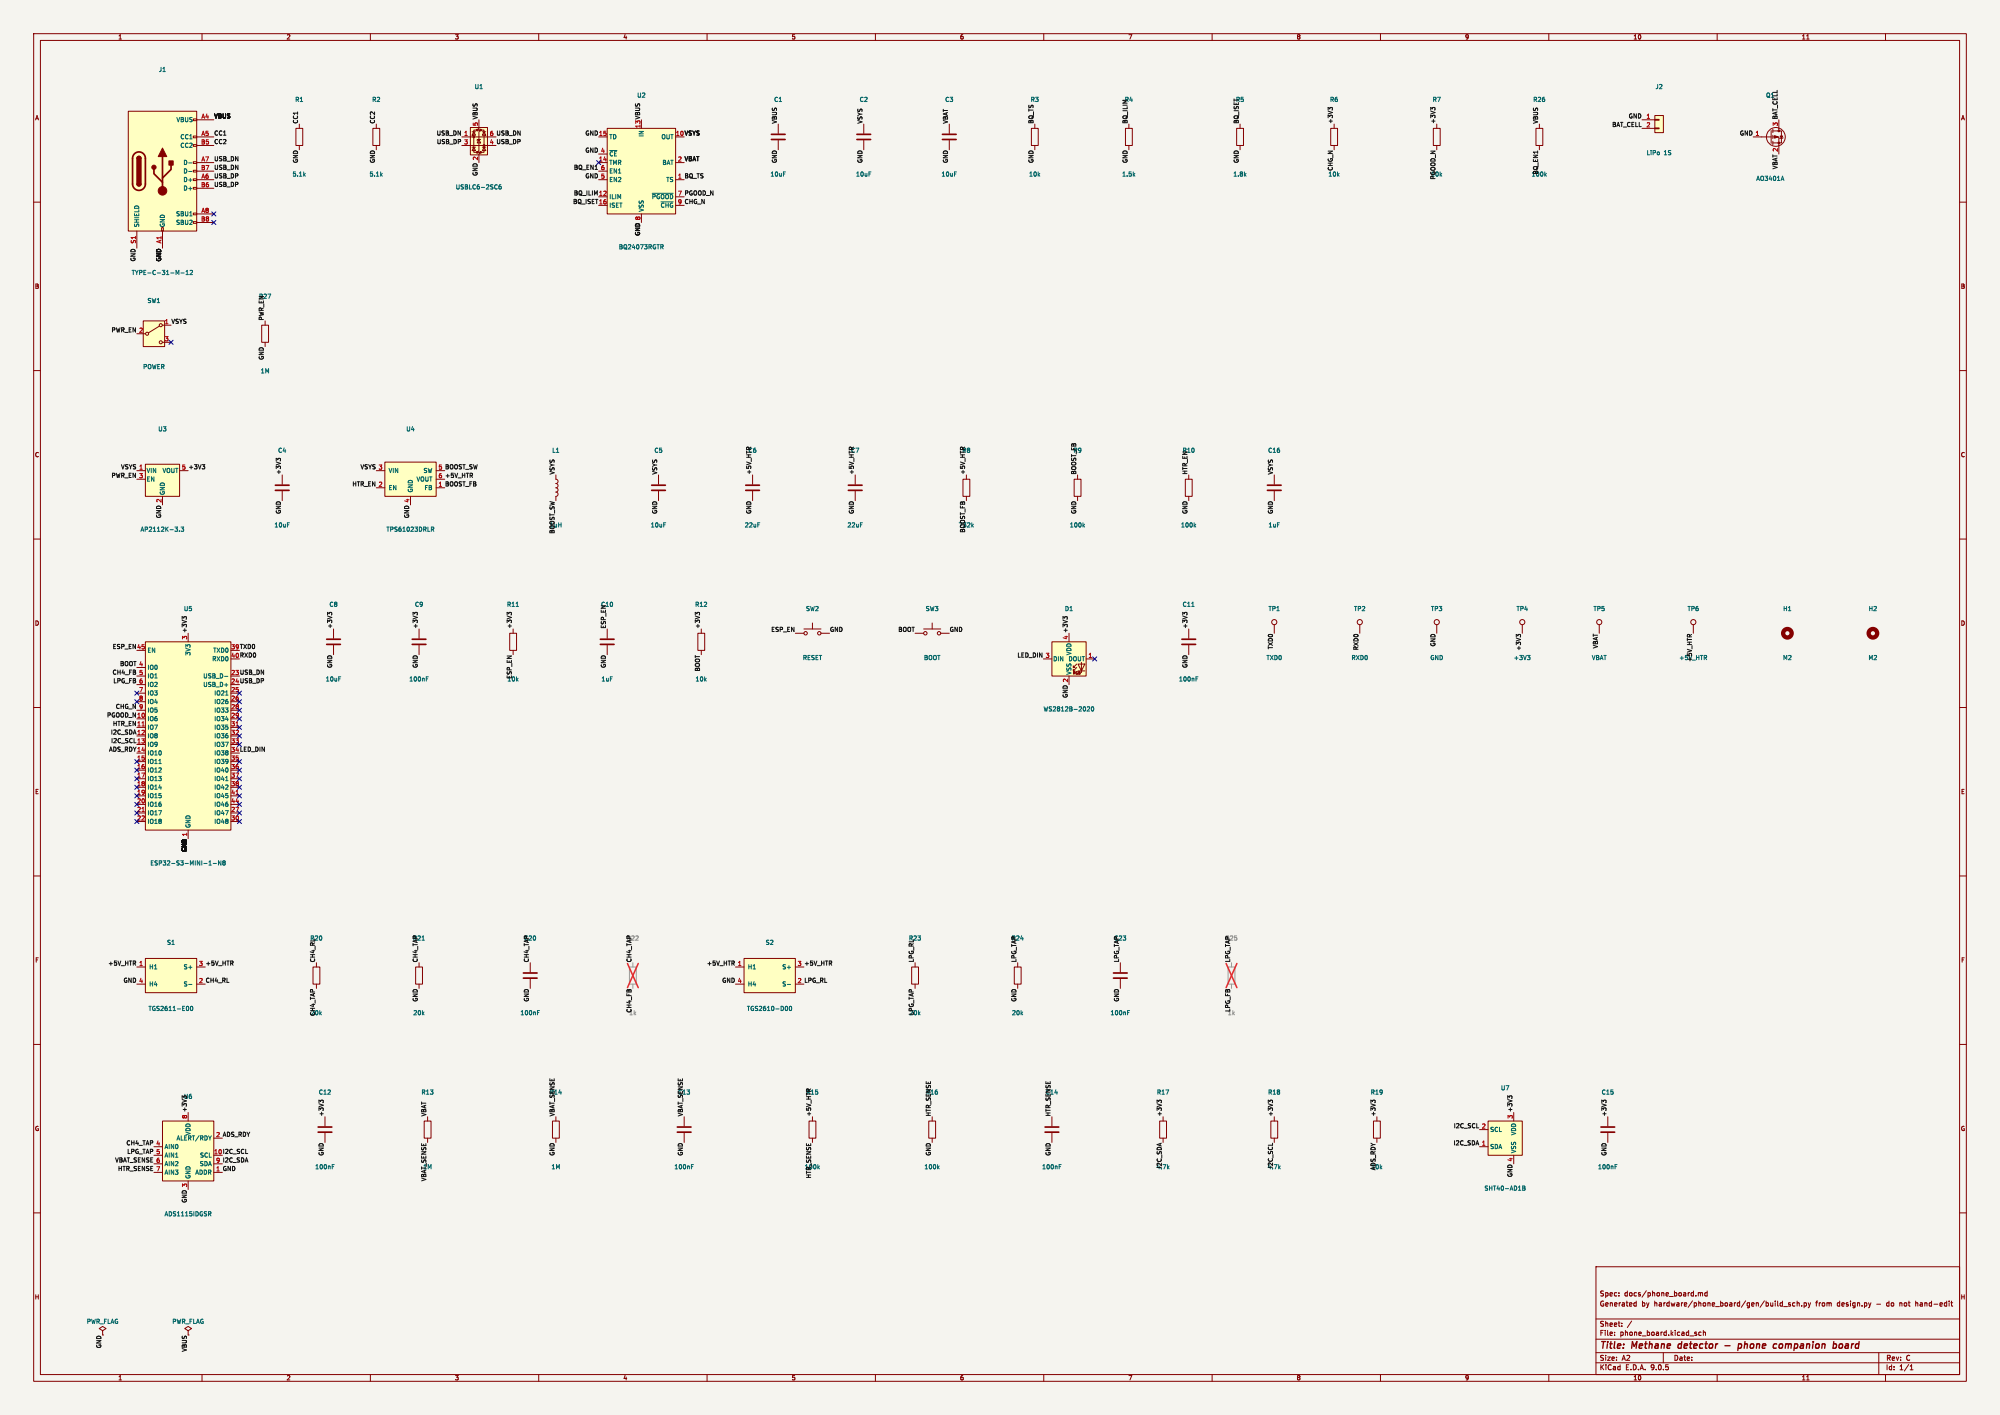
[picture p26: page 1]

8 OUT 10 BAT 2 TS 1 ~{PGOOD}7 ~{CHG}9 U2 BQ24073RGTR
TD 15 ~{CE} 4 TMR 14 EN1 6 EN2 5

3 ALERT/RDY 2 SCL 10 SDA 9 ADDR 1 U6 ADS1115IDGSR
GND +3V3 GND

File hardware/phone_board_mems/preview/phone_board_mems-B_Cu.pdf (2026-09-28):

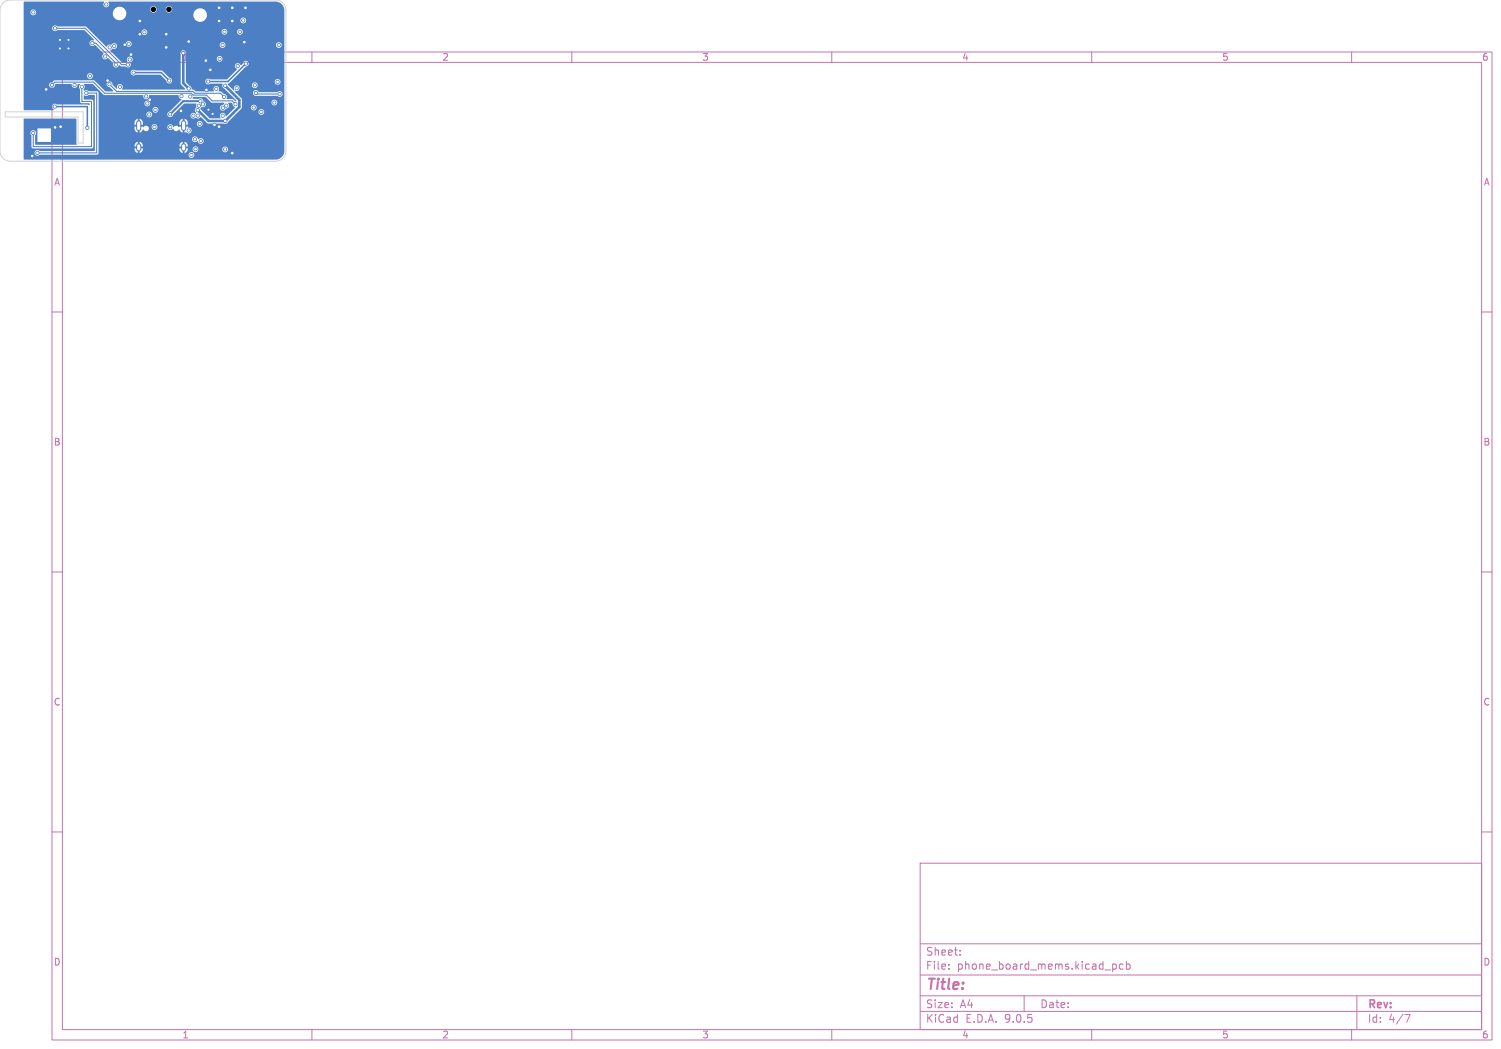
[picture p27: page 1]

Id: 4/7 Title: File: phone_board_mems.kicad_pcb Sheet:

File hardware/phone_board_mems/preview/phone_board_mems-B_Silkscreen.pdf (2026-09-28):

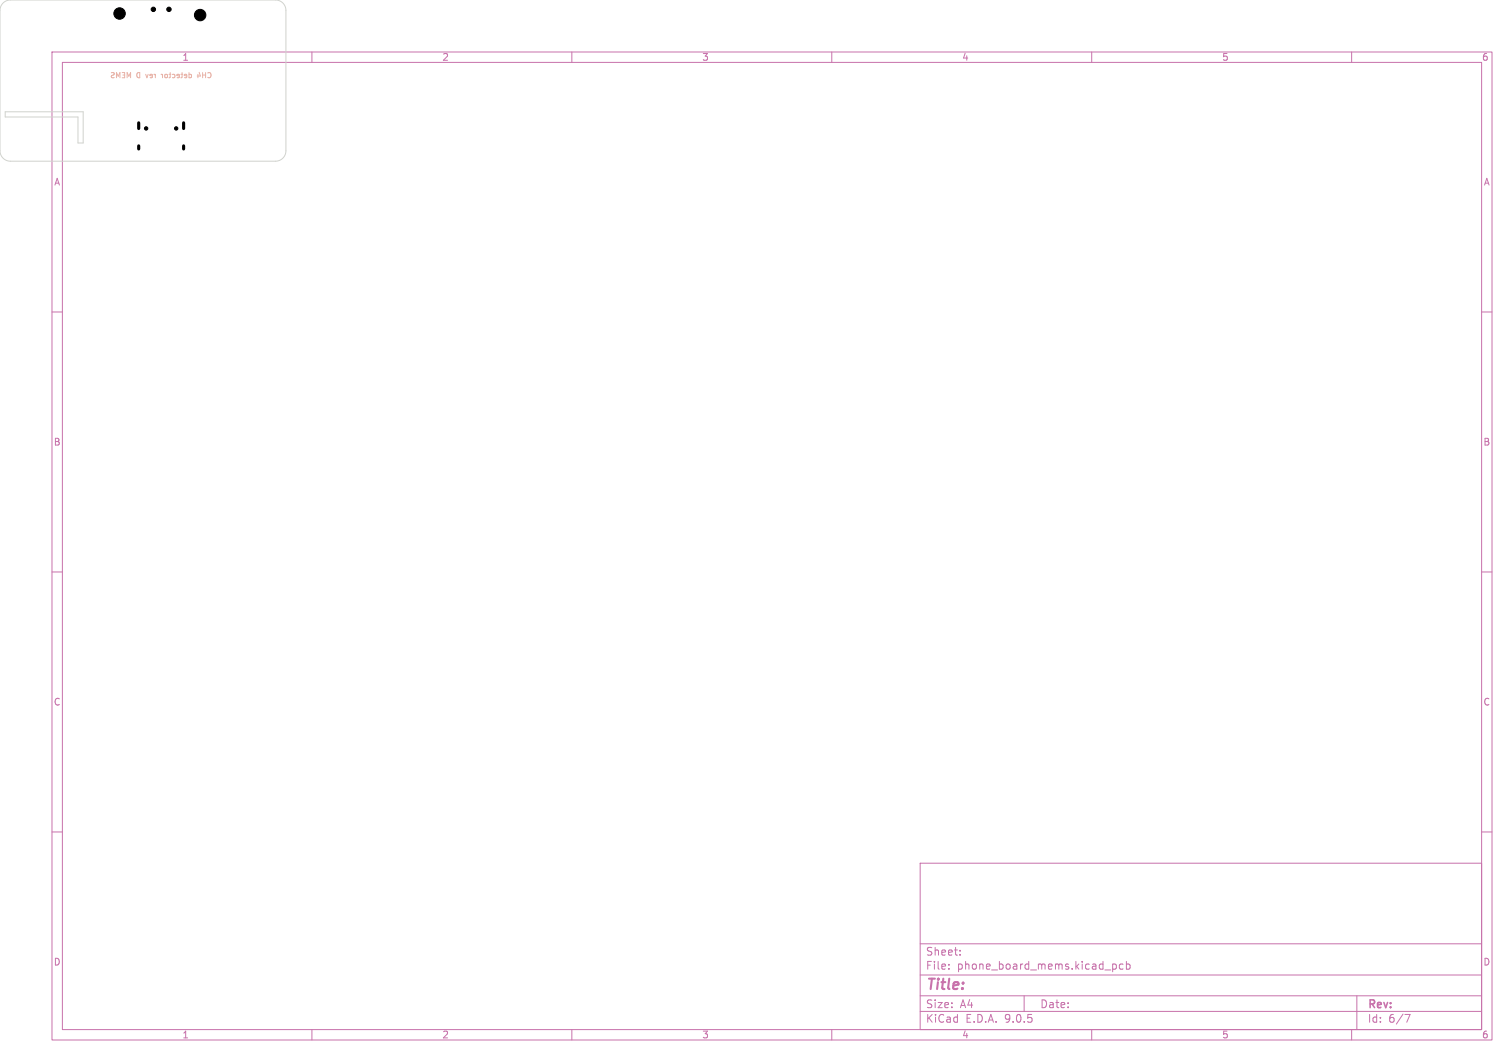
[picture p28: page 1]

Id: 6/7 Title: File: phone_board_mems.kicad_pcb Sheet:

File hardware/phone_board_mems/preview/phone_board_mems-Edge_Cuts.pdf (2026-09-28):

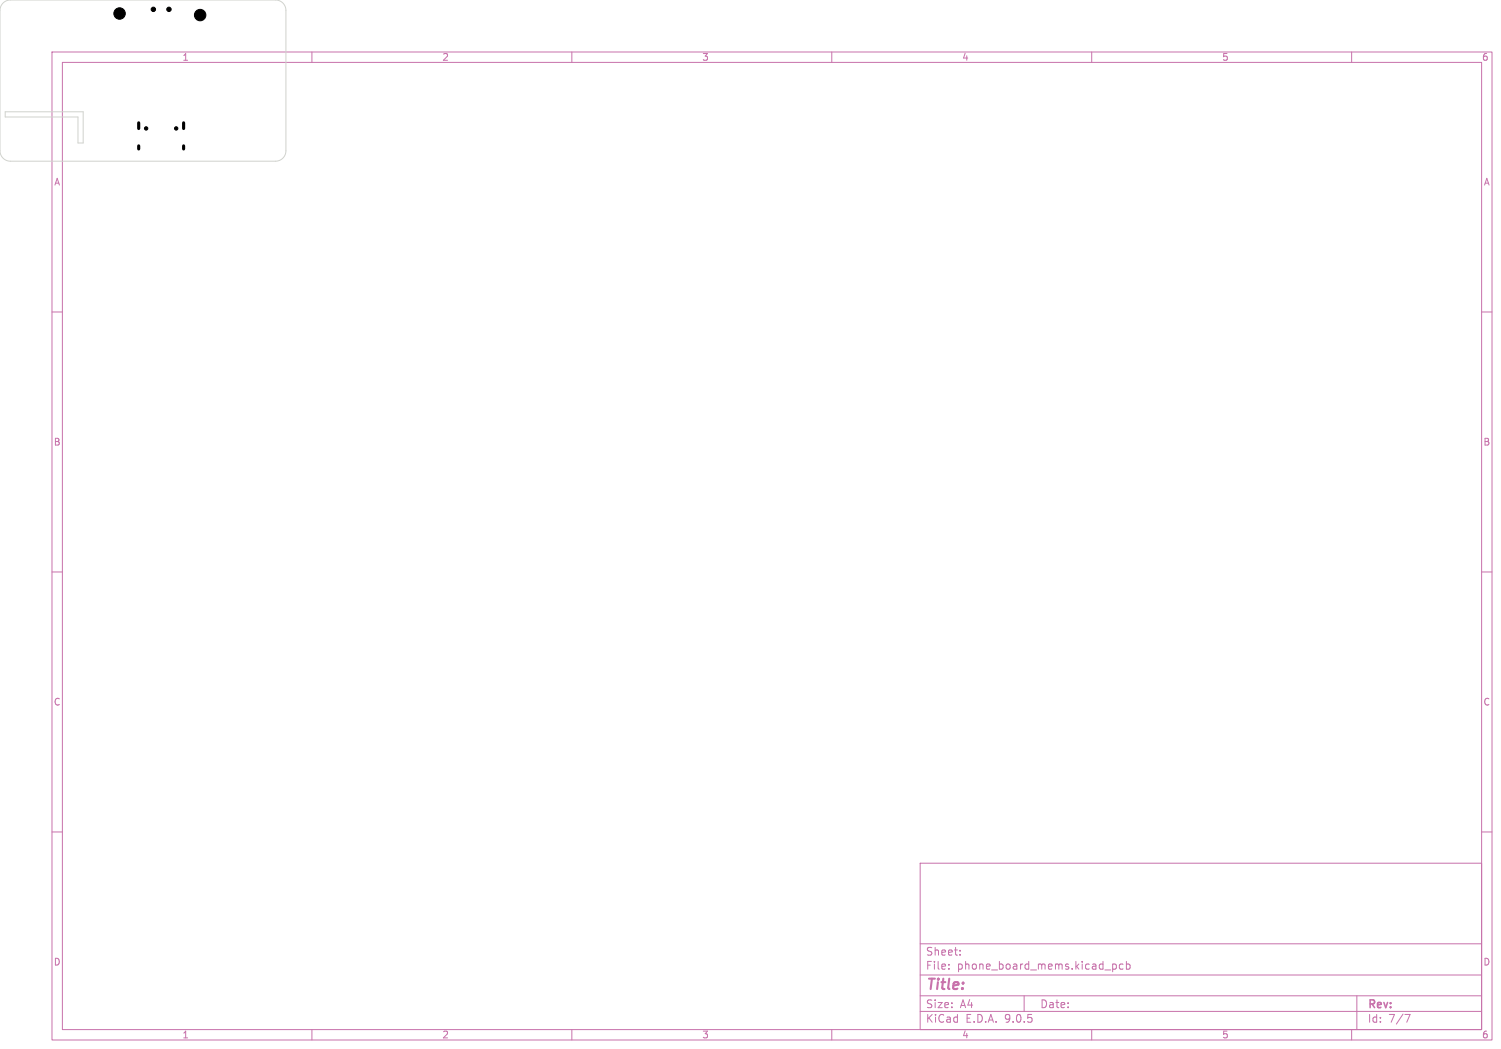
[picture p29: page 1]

Id: 7/7 Title: File: phone_board_mems.kicad_pcb Sheet:

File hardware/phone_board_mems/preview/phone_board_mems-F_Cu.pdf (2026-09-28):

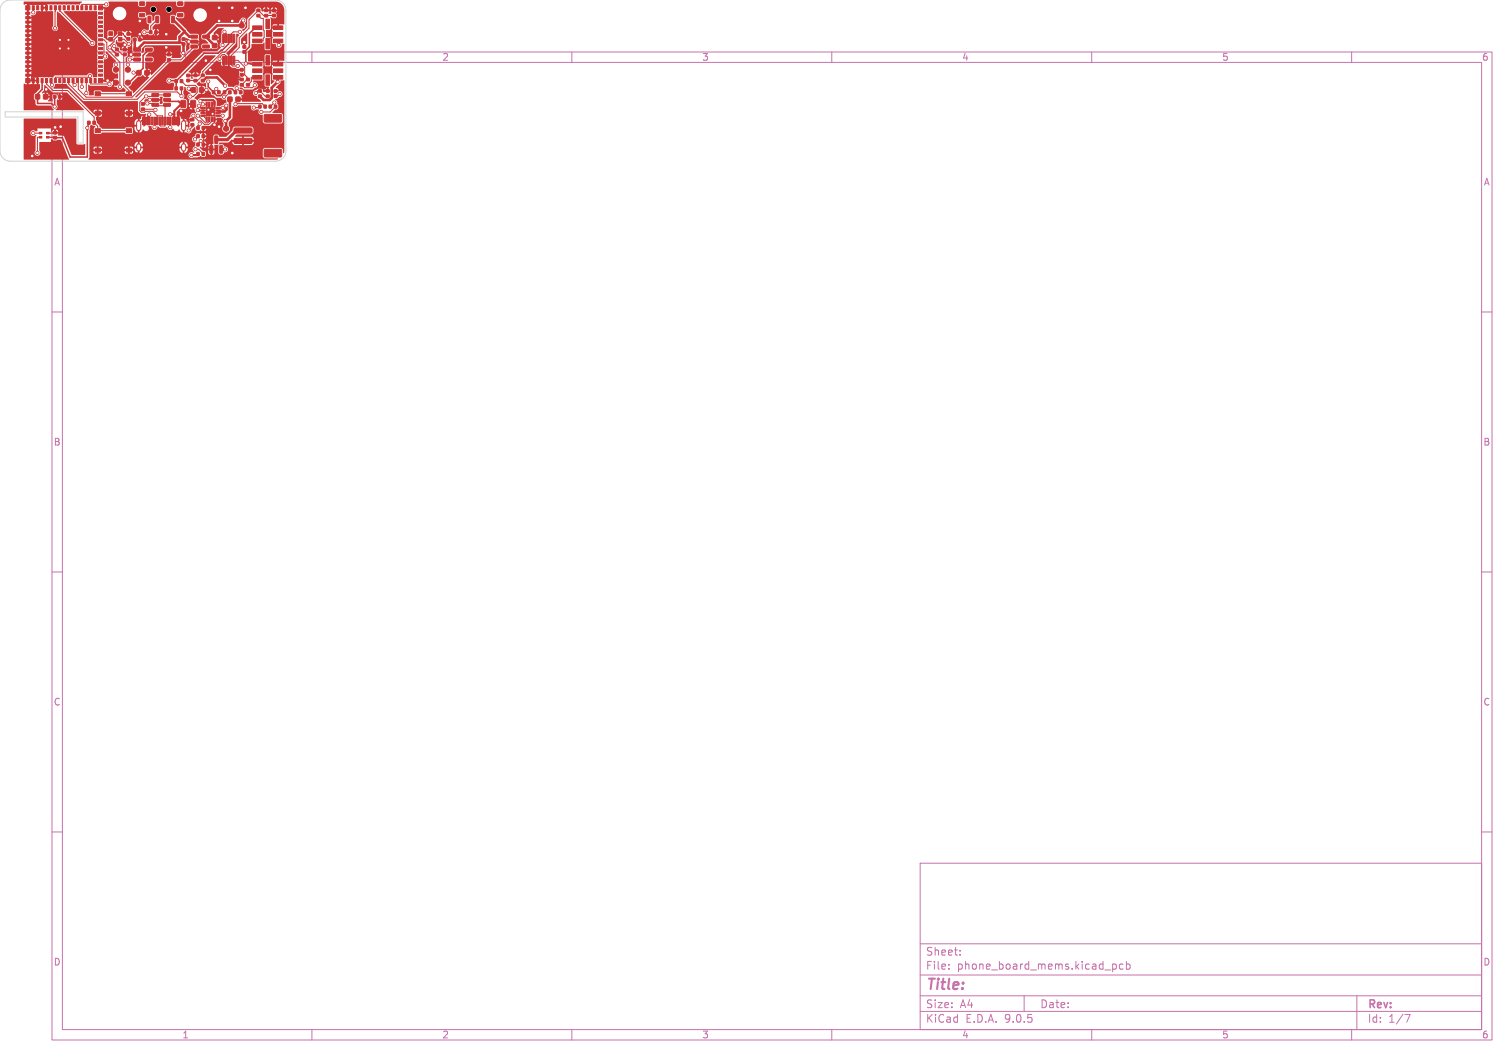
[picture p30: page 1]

Id: 1/7 Title: File: phone_board_mems.kicad_pcb Sheet:

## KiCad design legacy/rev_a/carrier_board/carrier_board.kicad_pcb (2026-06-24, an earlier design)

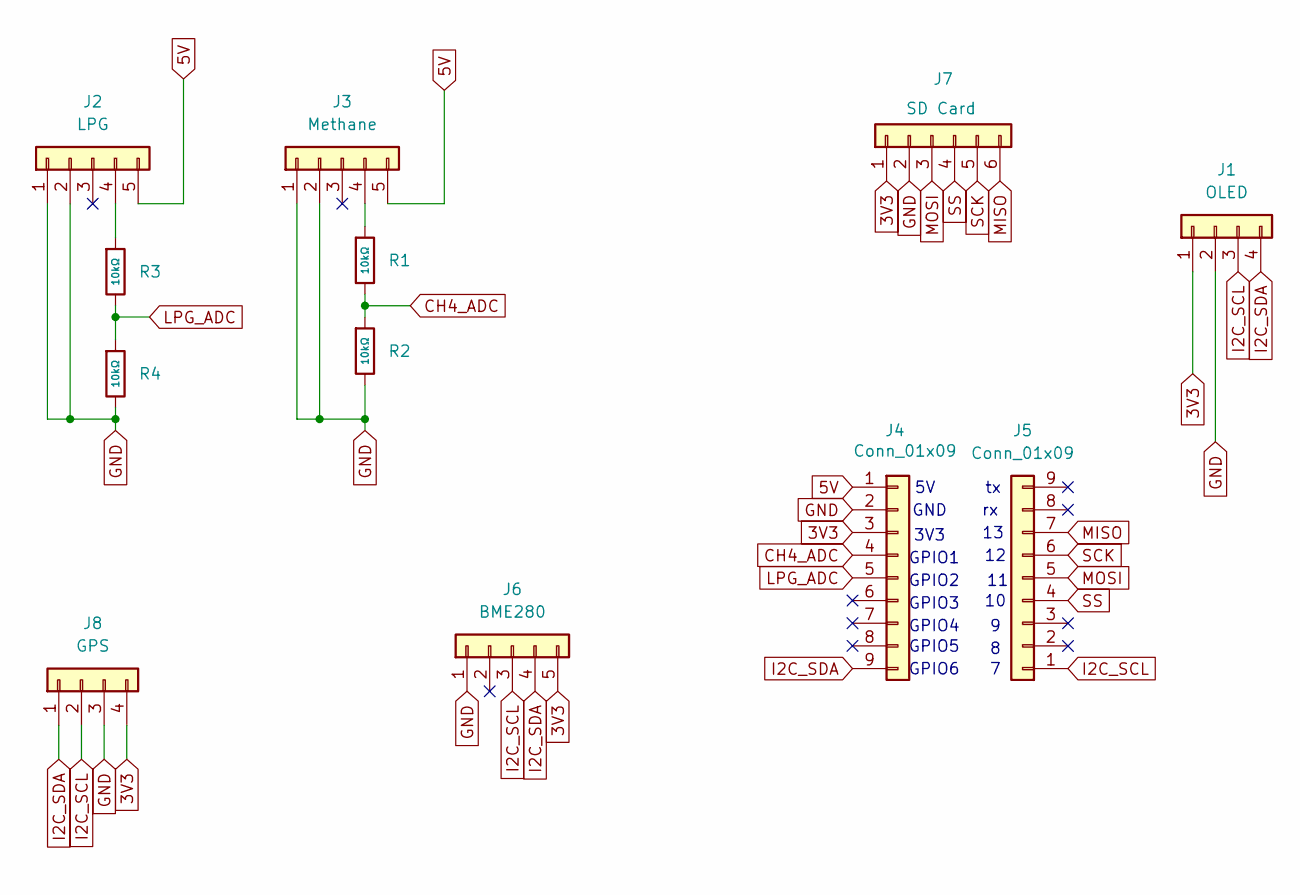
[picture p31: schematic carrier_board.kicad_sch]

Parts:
J1: OLED; PinSocket_1x04_P2.54mm_Vertical
J2: LPG; PinSocket_1x05_P2.54mm_Vertical
J3: Methane; PinSocket_1x05_P2.54mm_Vertical
J4, J5: Conn_01x09; PinSocket_1x09_P2.54mm_Vertical
J6: BME280; PinSocket_1x06_P2.54mm_Vertical
J7: SD Card; PinSocket_1x06_P2.54mm_Vertical
J8: GPS; PinHeader_1x04_P2.54mm_Horizontal
R1, R2, R3, R4: 10kΩ; R_0603; Overload Voltage (Max) 75V; Tolerance ±1%; Part 0603WAF1002T5E; LCSC C25804

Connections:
3V3: J1.1, J4.3, J6.5, J7.1, J8.4
5V: J2.5, J3.5, J4.1
CH4_ADC: J4.4, R1.2, R2.1
GND: J1.2, J2.1, J2.2, J3.1, J3.2, J4.2, J6.1, J7.2, J8.3, R2.2, R4.2
I2C_SCL: J1.3, J5.1, J6.3, J8.2
I2C_SDA: J1.4, J4.9, J6.4, J8.1
LPG_ADC: J4.5, R3.2, R4.1
MISO: J5.7, J7.6
MOSI: J5.5, J7.3
unnamed: J2.4, R3.1
unnamed: J3.4, R1.1
SCK: J5.6, J7.5
SS: J5.4, J7.4

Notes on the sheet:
GPIO1
GND
GPIO2
GPIO3
3V3
GPIO4
GPIO6
GPIO5

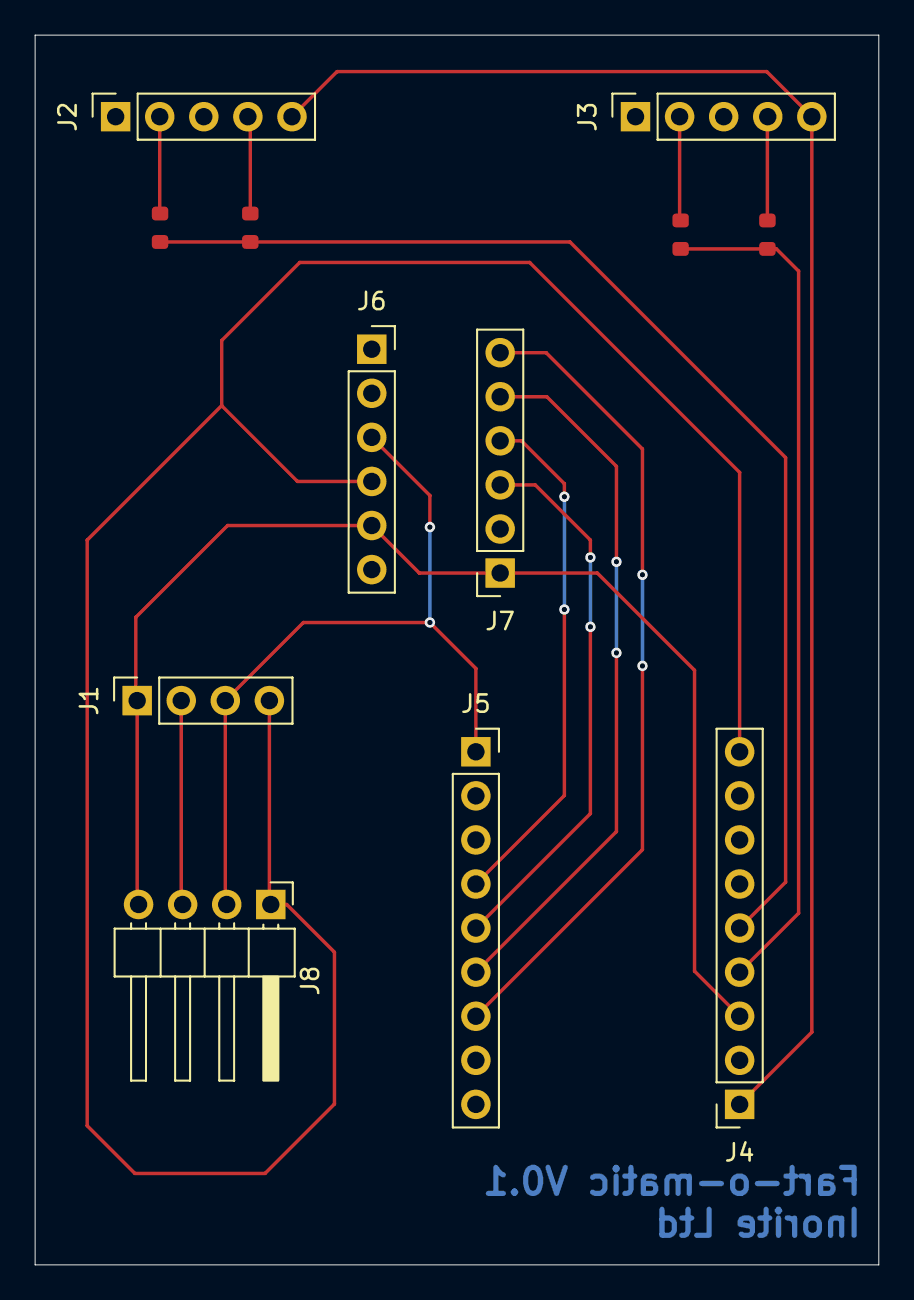
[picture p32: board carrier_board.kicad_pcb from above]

Board: 2 copper layers, 48.6 x 70.9 mm, 12 parts (0 on the bottom side), 13 nets.

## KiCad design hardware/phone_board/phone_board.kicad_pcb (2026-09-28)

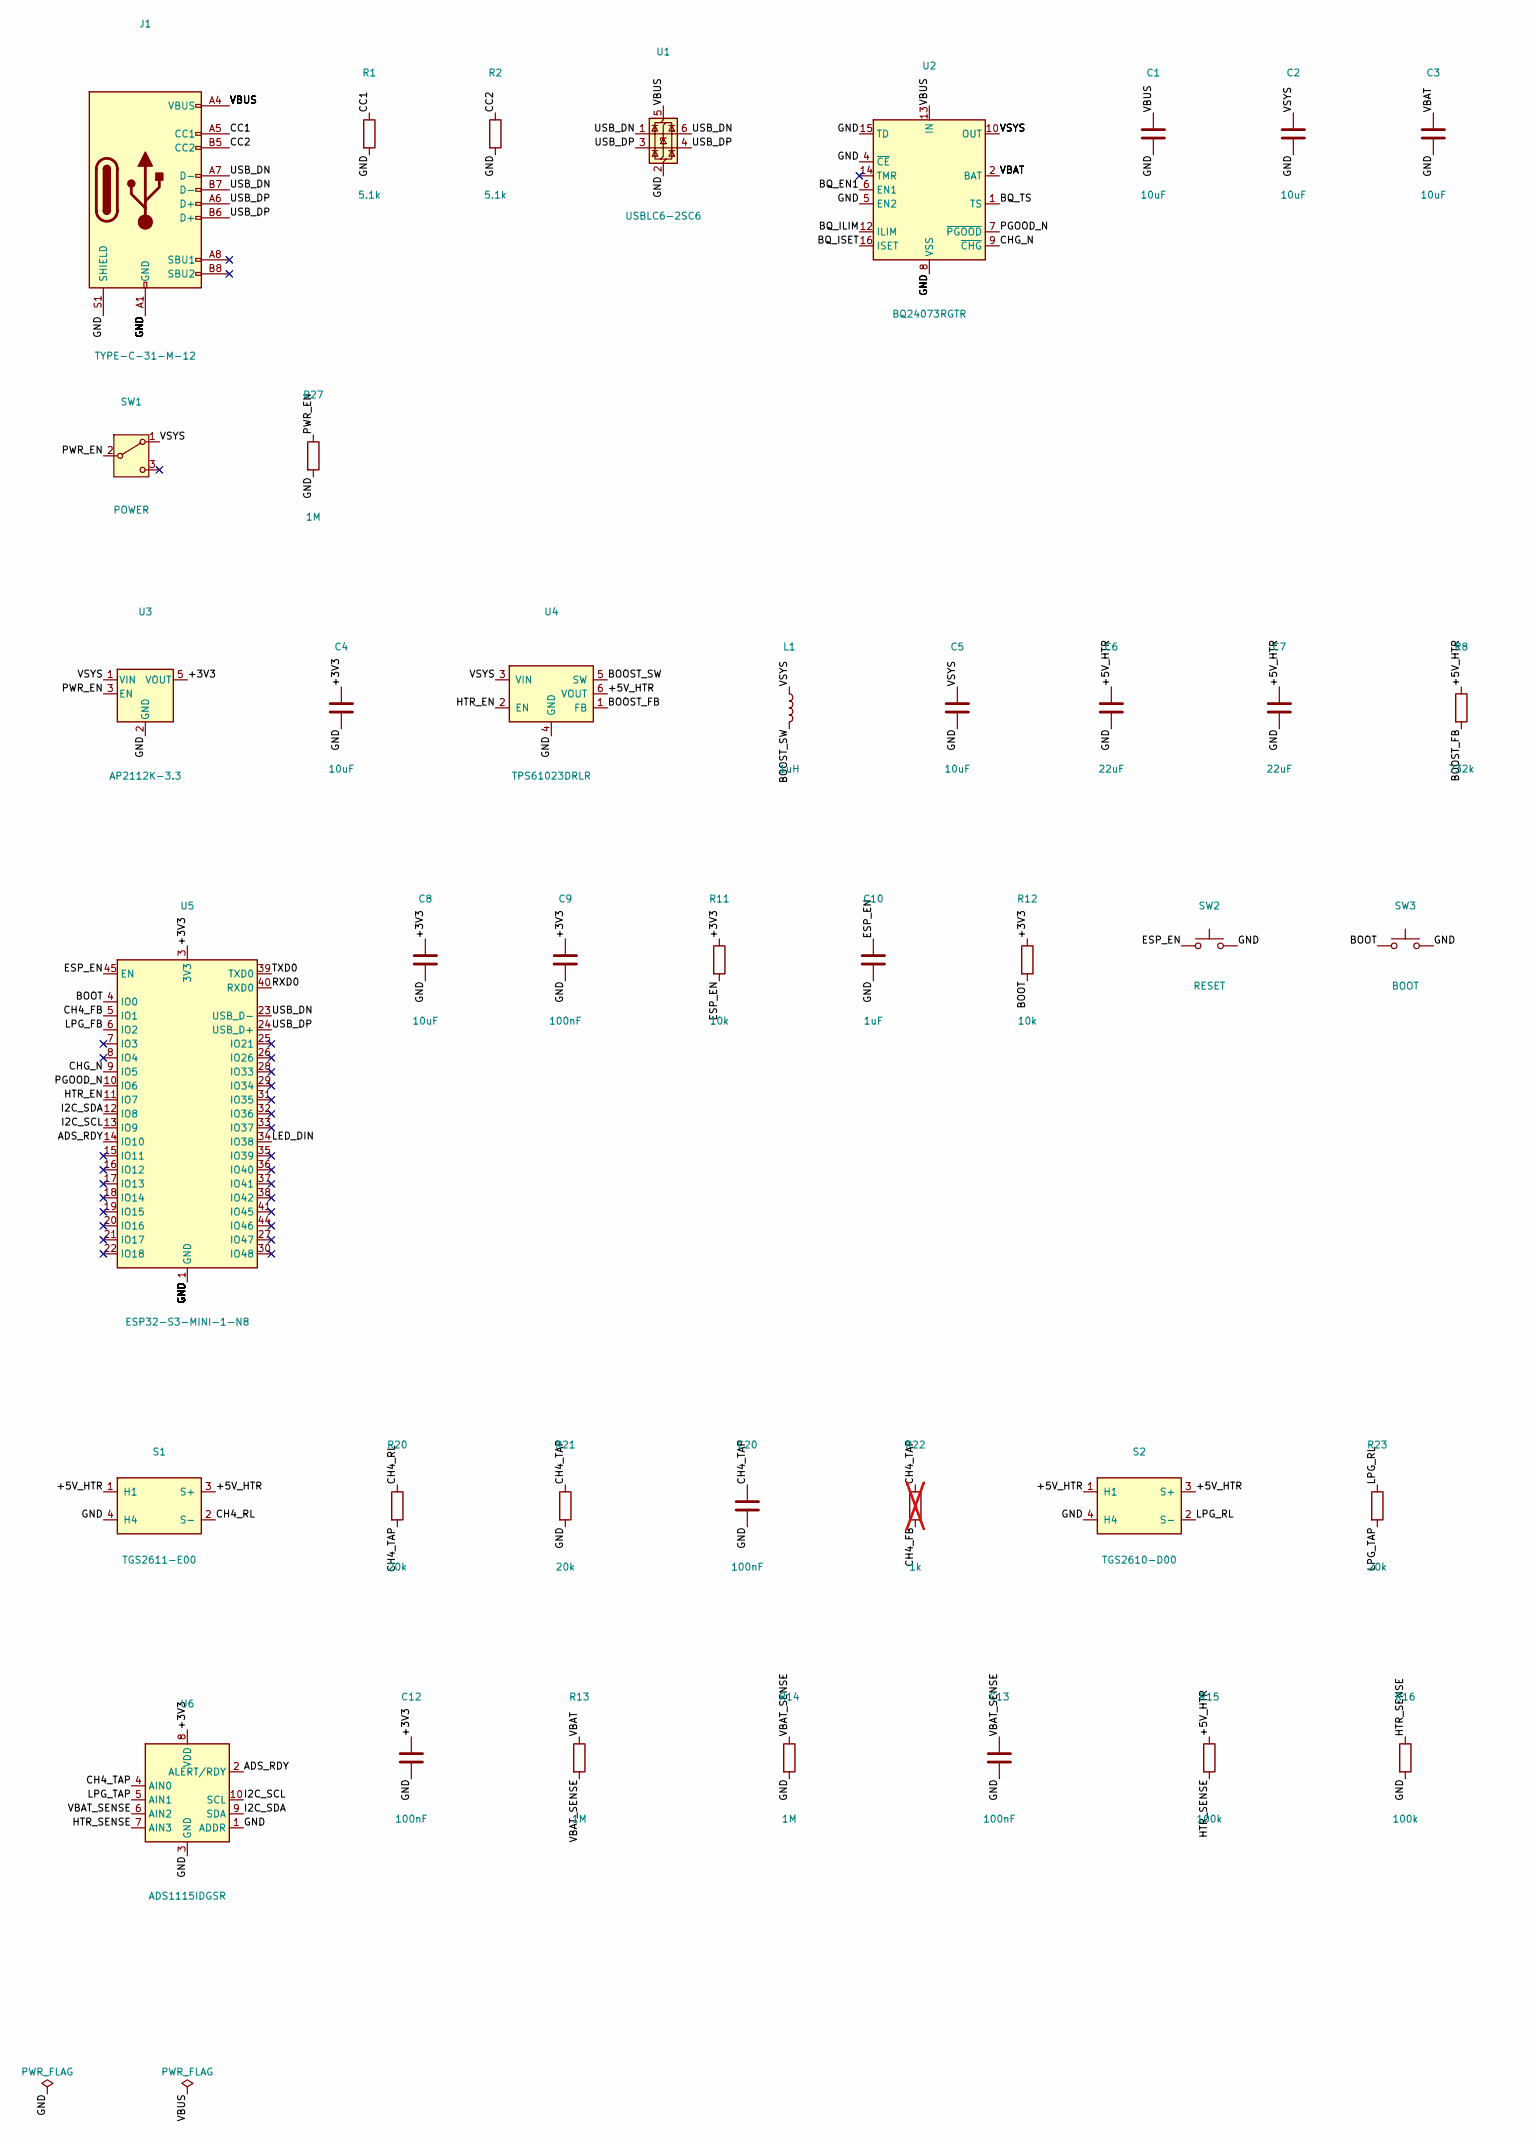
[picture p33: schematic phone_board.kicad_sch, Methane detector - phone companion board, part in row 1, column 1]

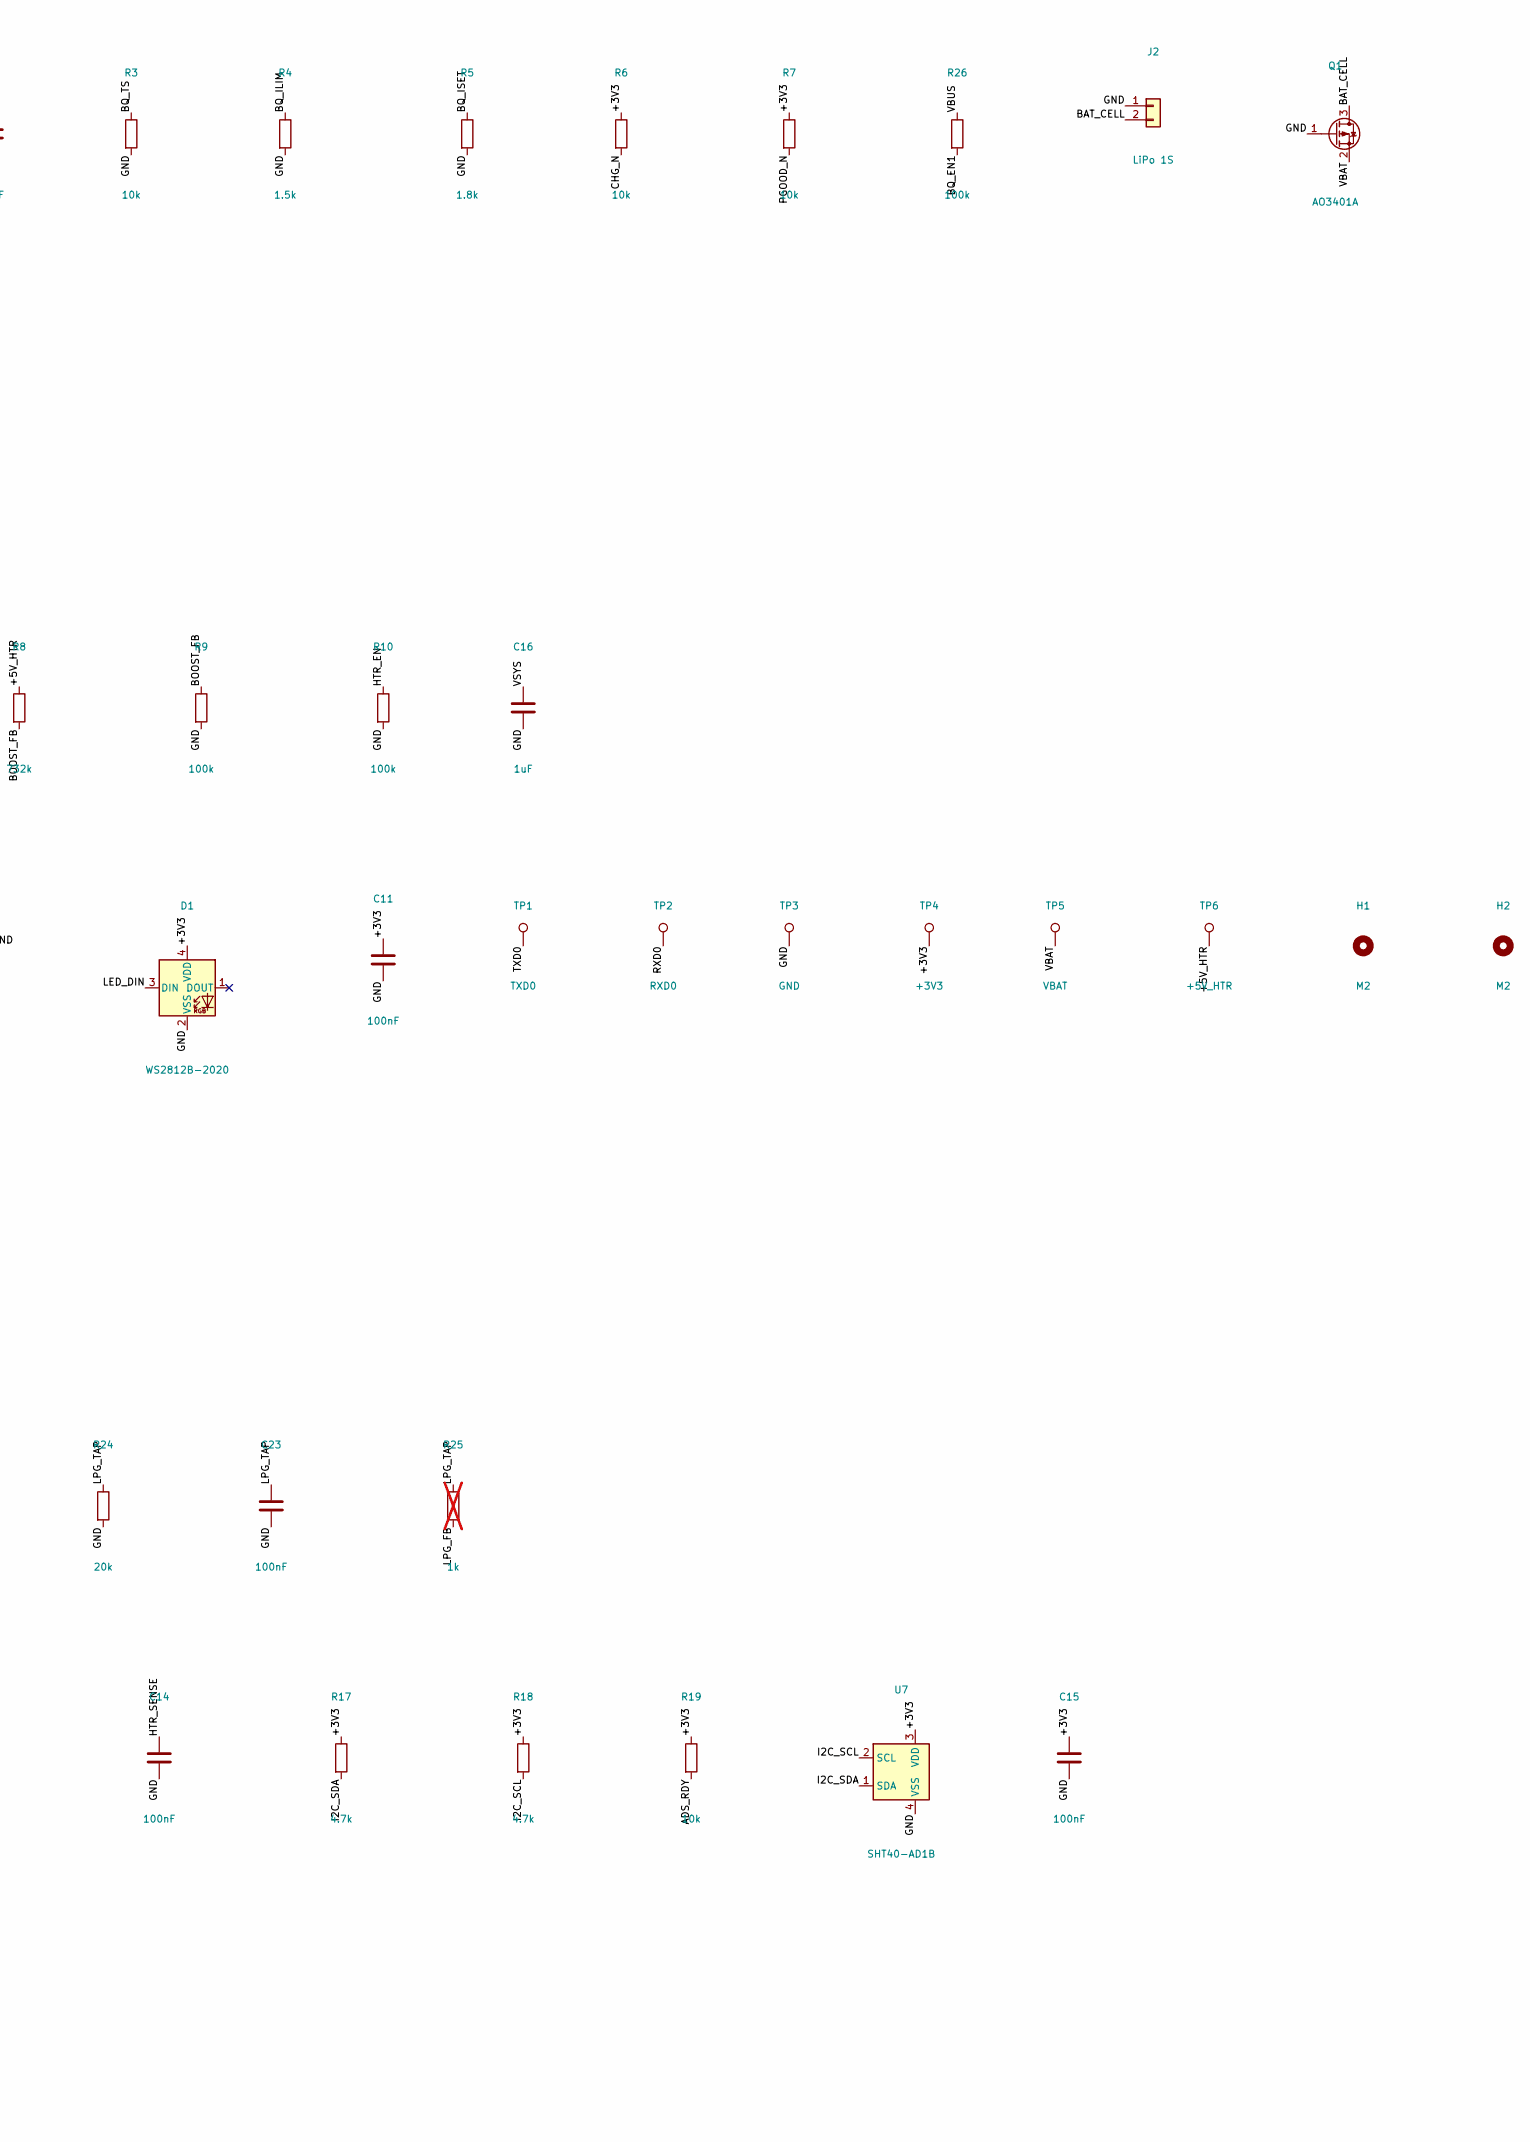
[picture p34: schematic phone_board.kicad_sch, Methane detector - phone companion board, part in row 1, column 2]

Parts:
C1: 10uF; C_0805_2012Metric; LCSC C15850
C2, C3, C4, C5, C8: 10uF; C_0603_1608Metric; LCSC C19702
C6, C7: 22uF; C_0805_2012Metric; LCSC C45783
C9, C11, C12, C13, C14, C15, C20, C23: 100nF; C_0402_1005Metric; LCSC C1525
C10, C16: 1uF; C_0402_1005Metric; LCSC C52923
D1: WS2812B-2020; LED_WS2812B-2020_PLCC4_2.0x2.0mm; LCSC C52917434
H1, H2: M2; MountingHole_2.2mm_M2
J1: TYPE-C-31-M-12; USB_C_Receptacle_HRO_TYPE-C-31-M-12; LCSC C165948
J2: LiPo 1S; JST_PH_S2B-PH-SM4-TB_1x02-1MP_P2.00mm_Horizontal; LCSC C295747
L1: 1uH; L_Sunlord_SWPA4030S; MPN SWPA4030S1R0NT; LCSC C42193
Q1: AO3401A; SOT-23; LCSC C15127
R1, R2: 5.1k; R_0402_1005Metric; LCSC C25905
R3, R6, R7, R11, R12, R19: 10k; R_0402_1005Metric; LCSC C25744
R4: 1.5k; R_0402_1005Metric; LCSC C25867
R5: 1.8k; R_0402_1005Metric; LCSC C25871
R8: 732k; R_0402_1005Metric; LCSC C27016
R9, R10, R15, R16, R26: 100k; R_0402_1005Metric; LCSC C25741
R13, R14, R27: 1M; R_0402_1005Metric; LCSC C26083
R17, R18: 4.7k; R_0402_1005Metric; LCSC C25900
R20, R21, R23, R24: 20k; R_0402_1005Metric; LCSC C25765
R22, R25: 1k; R_0402_1005Metric; LCSC C11702; not fitted
S1: TGS2611-E00; TO-5-4; MPN TGS2611-E00
S2: TGS2610-D00; TO-5-4; MPN TGS2610-D00
SW1: POWER; SW_SPDT_Shouhan_MSK12C02; LCSC C431540
SW2: RESET; SW_Push_1P1T_XKB_TS-1187A; LCSC C318884
SW3: BOOT; SW_Push_1P1T_XKB_TS-1187A; LCSC C318884
TP1: TXD0; TestPoint_Pad_D1.0mm
TP2: RXD0; TestPoint_Pad_D1.0mm
TP3: GND; TestPoint_Pad_D1.0mm
TP4: +3V3; TestPoint_Pad_D1.0mm
TP5: VBAT; TestPoint_Pad_D1.0mm
TP6: +5V_HTR; TestPoint_Pad_D1.0mm
U1: USBLC6-2SC6; SOT-23-6; LCSC C7519
U2: BQ24073RGTR; VQFN-16-1EP_3x3mm_P0.5mm_EP1.6x1.6mm; LCSC C15220
U3: AP2112K-3.3; SOT-23-5; LCSC C51118
U4: TPS61023DRLR; SOT-563; LCSC C919459
U5: ESP32-S3-MINI-1-N8; ESP32-S2-MINI-1; LCSC C2913206
U6: ADS1115IDGSR; MSOP-10_3x3mm_P0.5mm; LCSC C37593
U7: SHT40-AD1B; Sensirion_DFN-4_1.5x1.5mm_P0.8mm_SHT4x_NoCentralPad; MPN SHT40-AD1B-R2; LCSC C2909890

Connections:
/+3V3: C4.1, C8.1, C9.1, C11.1, C12.1, C15.1, D1.4 (VDD), R6.1, R7.1, R11.1, R12.1, R17.1, R18.1, R19.1, TP4.1, U3.5 (VOUT), U5.3 (3V3), U6.8 (VDD), U7.3 (VDD)
/+5V_HTR: C6.1, C7.1, R8.1, R15.1, S1.1 (H1), S1.3 (S+), S2.1 (H1), S2.3 (S+), TP6.1, U4.6 (VOUT)
/ADS_RDY: R19.2, U5.14 (IO10), U6.2 (ALERT/RDY)
/BAT_CELL: J2.2, Q1.3 (D)
/BOOST_FB: R8.2, R9.1, U4.1 (FB)
/BOOST_SW: L1.2, U4.5 (SW)
/BOOT: R12.2, SW3.1, U5.4 (IO0)
/BQ_EN1: R26.2, U2.6 (EN1)
/BQ_ILIM: R4.1, U2.12 (ILIM)
/BQ_ISET: R5.1, U2.16 (ISET)
/BQ_TS: R3.1, U2.1 (TS)
/CC1: J1.A5 (CC1), R1.1
/CC2: J1.B5 (CC2), R2.1
/CH4_FB: R22.2, U5.5 (IO1)
/CH4_RL: R20.1, S1.2 (S-)
/CH4_TAP: C20.1, R20.2, R21.1, R22.1, U6.4 (AIN0)
/CHG_N: R6.2, U2.9 (~CHG), U5.9 (IO5)
/ESP_EN: C10.1, R11.2, SW2.1, U5.45 (EN)
/GND: C1.2, C2.2, C3.2, C4.2, C5.2, C6.2, C7.2, C8.2, C9.2, C10.2, C11.2, C12.2, C13.2, C14.2, C15.2, C16.2, C20.2, C23.2, D1.2 (VSS), J1.A1 (GND), J1.A12 (GND), J1.B1 (GND), J1.B12 (GND), J1.S1 (SHIELD), J2.1, Q1.1 (G), R1.2, R2.2, R3.2, R4.2, R5.2, R9.2, R10.2, R14.2, R16.2, R21.2, R24.2, R27.2, S1.4 (H4), S2.4 (H4), SW2.2, SW3.2, TP3.1, U1.2 (GND), U2.4 (~CE), U2.5 (EN2), U2.8 (VSS), U2.15 (TD), U2.17 (VSS), U3.2 (GND), U4.4 (GND), U5.1 (GND), U5.2 (GND), U5.42 (GND), U5.43 (GND), U5.46 (GND), U5.47 (GND), U5.48 (GND), U5.49 (GND), U5.50 (GND), U5.51 (GND), U5.52 (GND), U5.53 (GND), U5.54 (GND), U5.55 (GND), U5.56 (GND), U5.57 (GND), U5.58 (GND), U5.59 (GND), U5.60 (GND), U5.61 (GND), U5.62 (GND), U5.63 (GND), U5.64 (GND), U5.65 (GND), U6.1 (ADDR), U6.3 (GND), U7.4 (VSS)
/HTR_EN: R10.1, U4.2 (EN), U5.11 (IO7)
/HTR_SENSE: C14.1, R15.2, R16.1, U6.7 (AIN3)
/I2C_SCL: R18.2, U5.13 (IO9), U6.10 (SCL), U7.2 (SCL)
/I2C_SDA: R17.2, U5.12 (IO8), U6.9 (SDA), U7.1 (SDA)
/LED_DIN: D1.3 (DIN), U5.34 (IO38)
/LPG_FB: R25.2, U5.6 (IO2)
/LPG_RL: R23.1, S2.2 (S-)
/LPG_TAP: C23.1, R23.2, R24.1, R25.1, U6.5 (AIN1)
/PGOOD_N: R7.2, U2.7 (~PGOOD), U5.10 (IO6)
/PWR_EN: R27.1, SW1.2 (B), U3.3 (EN)
/RXD0: TP2.1, U5.40 (RXD0)
/TXD0: TP1.1, U5.39 (TXD0)
/USB_DN: J1.A7 (D-), J1.B7 (D-), U1.1 (I/O1), U1.6 (I/O1), U5.23 (USB_D-)
/USB_DP: J1.A6 (D+), J1.B6 (D+), U1.3 (I/O2), U1.4 (I/O2), U5.24 (USB_D+)
/VBAT: C3.1, Q1.2 (S), R13.1, TP5.1, U2.2 (BAT), U2.3 (BAT)
/VBAT_SENSE: C13.1, R13.2, R14.1, U6.6 (AIN2)
/VBUS: C1.1, J1.A4 (VBUS), J1.A9 (VBUS), J1.B4 (VBUS), J1.B9 (VBUS), R26.1, U1.5 (VBUS), U2.13 (IN)
/VSYS: C2.1, C5.1, C16.1, L1.1, SW1.1 (A), U2.10 (OUT), U2.11 (OUT), U3.1 (VIN), U4.3 (VIN)

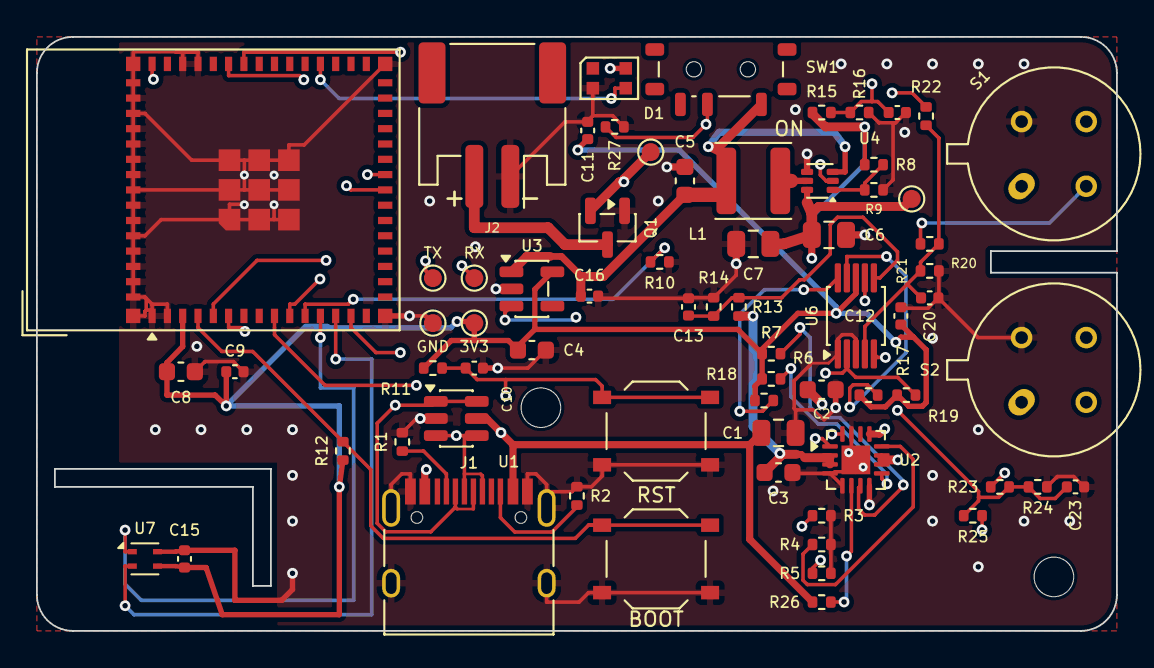
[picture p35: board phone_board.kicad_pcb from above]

Board: 4 copper layers, 60.0 x 33.0 mm, 70 parts (0 on the bottom side), 37 nets.

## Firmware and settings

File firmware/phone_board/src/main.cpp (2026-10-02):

// Phone-companion board firmware (rev B and rev C, which share one circuit): a
// thin BLE sampler.
//
// docs/phone_board.md is the source of truth for everything this file
// implements (pin map, ADS1115 channels, BLE UUIDs, packet layout, Info JSON,
// Control opcodes). Change the spec first, then this file.
//
// What it does, and deliberately does not do
// ------------------------------------------
// Rev A ran the whole instrument on the board (baseline, classifier, OLED,
// GNSS, SD). Rev B hands all of that to the phone app. The firmware only:
//   1. reads the two bare Figaro sensor load-resistor taps, VBAT and the heater
//      rail on the ADS1115, and temperature/humidity on the SHT40 (there is no
//      pressure sensor on the board; the app uses the phone's barometer);
//   2. averages each ADC channel over the sample interval (default 250 ms);
//   3. sends one 20-byte notification per interval to a subscribed phone, and
//      prints the same sample as a CSV line on USB serial for bench debugging.
// There is no baseline, no HIGH/MED/LOW, no Rs compensation here -- the app does
// that, where it is easier to tune. The status LED colour is set by the app.
//
// Sampling
// --------
// The ADS1115 runs single-shot at 250 SPS, round-robin AIN0 -> AIN1 -> AIN2 ->
// AIN3, as fast as conversions complete (~4 ms each plus I2C). Every conversion
// is added to a per-channel accumulator; at each interval boundary the mean of
// everything collected is taken, so a longer interval simply averages more (at
// 250 ms that is roughly a dozen conversions per channel). The loop is
// non-blocking so the button and LED stay responsive between conversions.
//
// Conversion-ready comes from the ADS ALERT/RDY pin (GPIO10, active low). As a
// guard against a stale low level the pin is only trusted once the nominal
// conversion time has nearly elapsed. If RDY does not arrive in time the config
// register's OS bit is read over I2C instead; if that shows the conversion did
// finish, the RDY trace is assumed broken and after a few such misses the
// sampler switches to I2C polling for good. If the chip does not answer at all
// for several conversions in a row it is marked lost and re-probed every few
// seconds.
//
// Whenever the ADS1115 is absent (or lost) the CH4/LPG taps are read instead by
// the ESP32's own ADC on the 1k fallback pins (GPIO1/GPIO2, oversampled,
// calibrated analogReadMilliVolts) and flag bit3 is cleared so the app knows the
// resolution dropped. VBAT and the heater rail are only wired to the ADS1115,
// so in fallback vbat reads 0 (unknown) and the heater check (bit4) is not
// asserted.
//
// Heaters: HTR_EN (GPIO7) is the boost converter's enable and has a 100k
// pull-down on the board, so the heaters stay off until setup() drives it HIGH.
// Low-battery heater cutoff: the ~115 mA heaters are most of the load, so when
// VBAT stays below 3.3 V for 10 s the firmware drives HTR_EN low and sets flag
// bit6; above 3.5 V it drives the pin HIGH again. While the heaters are held
// off the dead heater rail is not reported as a fault.
// The cutoff is skipped (and cleared) while USB power is present (PGOOD_N low).
// The gas readings are meaningless with the heaters off; the app should say so.
//
// BLE
// ---
// NimBLE, one custom service, one client at a time. Advertising carries the
// flags and the 128-bit service UUID; the name CH4-XXXX (last two bytes of the
// BT MAC) goes in the scan response because both do not fit in 31 bytes. On
// connect the firmware asks for a 45-75 ms connection interval (comfortably
// inside iOS/Android rules and fast enough for 100 ms samples); on disconnect
// it restarts advertising. Notifications are only sent while the client has
// notifications enabled on the Sample characteristic. BLE callbacks run on the
// NimBLE host task, so everything they share with loop() is std::atomic.
//
// LED (WS2812B/SK6812 on GPIO38, standard GRB -- no R/G swap unlike rev A's
// onboard LED): slow dim blue breathe while advertising; solid dim cyan once
// connected until the app sends a colour (opcode 0x03); opcode 0x02 blinks
// white three times. App colours are scaled down (LED_APP_SCALE) to save
// battery -- the app's 255 is our LED_APP_SCALE.

#include <Arduino.h>
#include <Wire.h>
#include <atomic>
#include <cmath>
#include <esp_mac.h>
#include <esp_system.h>
#include <NimBLEDevice.h>
#include <Adafruit_ADS1X15.h>
#include <Adafruit_SHT4x.h>

static const char *FW_VERSION = "1.0.0";
static const char *BOARD_ID = "rev-b";

// ---- Pins (docs/phone_board.md, ESP32-S3-MINI-1-N8 pin map) -----------------
static const uint8_t PIN_BOOT_BUTTON = 0;   // active low, tact switch to GND
static const uint8_t PIN_CH4_ADC_FB = 1;    // fallback CH4 tap via 1k (ADC1)
static const uint8_t PIN_LPG_ADC_FB = 2;    // fallback LPG tap via 1k (ADC1)
static const uint8_t PIN_CHG_N = 5;         // BQ24073 CHG, low = charging
static const uint8_t PIN_PGOOD_N = 6;       // BQ24073 PGOOD, low = USB power good
static const uint8_t PIN_HTR_EN = 7;        // 100k pull-down: drive HIGH = heaters on, LOW = off
static const uint8_t PIN_I2C_SDA = 8;
static const uint8_t PIN_I2C_SCL = 9;
static const uint8_t PIN_ADS_RDY = 10;      // ADS1115 ALERT/RDY, active low
static const uint8_t PIN_LED_DIN = 38;      // WS2812-class status LED

// ---- I2C devices ---------------------------------------------------------------
static const uint32_t I2C_CLOCK_HZ = 400000;  // both parts are fast-mode capable
static const uint8_t ADS1115_ADDR = 0x48;
// SHT40-AD1B is fixed at 0x44 (the Adafruit driver hard-codes it).

// ---- Analogue front end (must match Info JSON and the schematic) --------------
static const uint32_t RL_OHM = 40000;      // RLa + RLb (20k + 20k)
static const float TAP_RATIO = 2.0f;       // VRL = 2 x tap
static const uint16_t VC_MV = 5000;        // nominal sensor circuit voltage
static const float VBAT_RATIO = 2.0f;      // 100k/100k on AIN2
static const float HEATER_RATIO = 2.0f;    // 100k/100k on AIN3
static const uint16_t HEATER_MIN_MV = 4800;  // bit4 if outside this window
static const uint16_t HEATER_MAX_MV = 5200;

// ---- Heater turn-on happens first thing in setup(), before the radio, I2C
// and USB are up and with the CPU at 80 MHz, because on USB power alone the
// BQ24073's 500 mA input limit only just covers the boost converter's start-up
// inrush into two cold heaters. Bench evidence (2026-09-28): with heaters
// switched on 3 s after boot, alongside BLE advertising at 240 MHz, the board
// browned out (reset reason 9) at that instant on two consecutive boots and
// only survived once the heaters had warmed a little. A LiPo on J2 removes the
// problem entirely, since the cell holds VSYS up. After enabling, setup() waits
// HEATER_SETTLE_MS before adding any other load.
static const uint32_t HEATER_SETTLE_MS = 500;
static const uint32_t CPU_MHZ = 80;  // plenty for a 4 Hz sampler; ~30 mA less than 240

// ---- Low-battery heater cutoff (drives HTR_EN low) ---------------------------------
static const uint16_t HEATER_CUTOFF_MV = 3300;       // off below this ...
static const uint32_t HEATER_CUTOFF_HOLD_MS = 10000; // ... for longer than this
static const uint16_t HEATER_RESTORE_MV = 3500;      // back on above this

// ---- ADS1115 sampling ---------------------------------------------------------
static const float ADS_MV_PER_COUNT = 0.125f;  // GAIN_ONE, +/-4.096 V
static const uint32_t ADS_MIN_CONV_US = 3200;  // 250 SPS = 4000 us nominal, -20%
static const uint32_t ADS_POLL_AT_US = 4600;   // polling mode: first OS-bit read
static const uint32_t ADS_TIMEOUT_US = 20000;  // give up waiting for RDY
static const uint8_t ADS_RDY_MISSES_TO_POLL = 3;  // then stop trusting GPIO10
static const uint8_t ADS_FAILS_TO_LOST = 5;       // then fall back to ESP32 ADC
static const uint32_t ADS_REPROBE_MS = 5000;

// ---- Fallback ESP32 ADC --------------------------------------------------------
static const uint8_t FALLBACK_OVERSAMPLE = 32;

// ---- Sample interval (Control opcode 0x01 range) -----------------------------
static const uint16_t DEFAULT_INTERVAL_MS = 250;
static const uint16_t MIN_INTERVAL_MS = 100;
static const uint16_t MAX_INTERVAL_MS = 5000;

// ---- Button --------------------------------------------------------------------
static const uint32_t BUTTON_DEBOUNCE_MS = 30;

// ---- BLE ---------------------------------------------------------------------------
static const char *UUID_SERVICE = "6d1a0001-8f3e-4b8a-9c57-2f6c0e3a7b10";
static const char *UUID_SAMPLE = "6d1a0002-8f3e-4b8a-9c57-2f6c0e3a7b10";
static const char *UUID_INFO = "6d1a0003-8f3e-4b8a-9c57-2f6c0e3a7b10";
static const char *UUID_CONTROL = "6d1a0004-8f3e-4b8a-9c57-2f6c0e3a7b10";
static const uint8_t PROTO_VERSION = 1;
static const size_t SAMPLE_PACKET_LEN = 20;
// Requested connection parameters (units: 1.25 ms, 1.25 ms, events, 10 ms).
static const uint16_t CONN_MIN_INTERVAL = 36;  // 45 ms
static const uint16_t CONN_MAX_INTERVAL = 60;  // 75 ms
static const uint16_t CONN_LATENCY = 0;
static const uint16_t CONN_TIMEOUT = 500;      // 5 s

static const uint8_t OP_SET_INTERVAL = 0x01;
static const uint8_t OP_IDENTIFY = 0x02;
static const uint8_t OP_SET_LED = 0x03;

// Sentinels for missing environment values (sample packet).
static const int16_t TEMP_MISSING = INT16_MIN;  // 0x8000
static const uint16_t HUM_MISSING = 0xFFFF;
static const uint16_t PRESS_MISSING = 0xFFFF;

// Flag bits (sample packet byte 19).
static const uint8_t FLAG_USB_POWER = 1 << 0;
static const uint8_t FLAG_CHARGING = 1 << 1;
static const uint8_t FLAG_BME_OK = 1 << 2;  // T/RH sensor (SHT40) ok
static const uint8_t FLAG_ADS_OK = 1 << 3;
static const uint8_t FLAG_HEATER_FAULT = 1 << 4;
static const uint8_t FLAG_BUTTON = 1 << 5;
static const uint8_t FLAG_HEATERS_OFF = 1 << 6;  // low-battery cutoff active

// ---- LED (kept dim: this runs off a 1-cell LiPo) ---------------------------------
static const uint32_t LED_UPDATE_MS = 20;
static const uint32_t LED_BREATHE_PERIOD_MS = 3000;
static const uint8_t LED_BREATHE_MIN = 1;
static const uint8_t LED_BREATHE_MAX = 24;
static const uint8_t LED_CONNECTED_G = 10;  // dim cyan
static const uint8_t LED_CONNECTED_B = 10;
static const uint8_t LED_IDENTIFY_LEVEL = 40;  // white
static const uint32_t LED_IDENTIFY_STEP_MS = 200;
static const uint8_t LED_IDENTIFY_BLINKS = 3;
static const uint8_t LED_APP_SCALE = 64;  // app 255 -> 64

// =================================================================================
// State shared with BLE callbacks (NimBLE host task)
// =================================================================================
static std::atomic<uint16_t> sampleIntervalMs{DEFAULT_INTERVAL_MS};
static std::atomic<bool> bleConnected{false};
static std::atomic<bool> notifyEnabled{false};
static std::atomic<bool> identifyRequested{false};
static std::atomic<uint32_t> appLedColour{0};  // 0x01RRGGBB when set, 0 when not
static std::atomic<uint16_t> lastHeaterMv{0};   // for Info JSON, 0 = unknown

static NimBLECharacteristic *sampleChar = nullptr;
static NimBLECharacteristic *infoChar = nullptr;
static char deviceName[16];

// =================================================================================
// Sensors
// =================================================================================
static Adafruit_ADS1115 ads;
static Adafruit_SHT4x sht4;
static bool shtReady = false;

static const uint16_t ADS_MUX[4] = {
    ADS1X15_REG_CONFIG_MUX_SINGLE_0,  // AIN0 CH4 tap
    ADS1X15_REG_CONFIG_MUX_SINGLE_1,  // AIN1 LPG tap
    ADS1X15_REG_CONFIG_MUX_SINGLE_2,  // AIN2 VBAT / 2
    ADS1X15_REG_CONFIG_MUX_SINGLE_3,  // AIN3 +5V_HTR / 2
};
enum AdsChannel { ADS_CH4 = 0, ADS_LPG = 1, ADS_VBAT = 2, ADS_HEATER = 3 };

// Sum of raw counts per channel since the last sample was emitted.
struct AdsAccumulator {
  int32_t sum;
  uint16_t count;
};

struct AdsState {
  bool ok = false;           // chip present and answering
  bool useRdyPin = true;     // false once GPIO10 has proven unreliable
  bool busy = false;         // a conversion is in progress
  uint8_t channel = 0;       // channel of the in-progress conversion
  uint32_t startUs = 0;      // micros() when it was started
  uint8_t rdyMisses = 0;     // consecutive conversions that finished without RDY
  uint8_t failures = 0;      // consecutive conversions that never finished
  uint32_t lastProbeMs = 0;
  AdsAccumulator acc[4] = {};
  float lastMv[4] = {0, 0, 0, 0};  // last window's mean, mV at the ADC pin
  bool haveMv[4] = {false, false, false, false};
};
static AdsState adsState;

static bool probeAds() {
  if (!ads.begin(ADS1115_ADDR, &Wire)) return false;
  ads.setGain(GAIN_ONE);  // +/-4.096 V, 125 uV/LSB
  ads.setDataRate(RATE_ADS1115_250SPS);
  adsState.ok = true;
  adsState.busy = false;
  adsState.channel = 0;
  adsState.failures = 0;
  for (int i = 0; i < 4; i++) {
    adsState.acc[i] = {0, 0};
    adsState.haveMv[i] = false;
  }
  return true;
}

// Advance the ADS1115 state machine by at most one step. Called every loop.
static void serviceAds(uint32_t nowMs) {
  if (!adsState.ok) {
    if (nowMs - adsState.lastProbeMs >= ADS_REPROBE_MS) {
      adsState.lastProbeMs = nowMs;
      if (probeAds()) Serial.println("ADS1115 found again; leaving ESP32 ADC fallback.");
    }
    return;
  }

  if (!adsState.busy) {
    ads.startADCReading(ADS_MUX[adsState.channel], /*continuous=*/false);
    adsState.startUs = micros();
    adsState.busy = true;
    return;
  }

  uint32_t elapsedUs = micros() - adsState.startUs;
  if (elapsedUs < ADS_MIN_CONV_US) return;  // too early: RDY may still be stale

  bool ready;
  if (adsState.useRdyPin) {
    ready = (digitalRead(PIN_ADS_RDY) == LOW);
  } else {
    ready = (elapsedUs >= ADS_POLL_AT_US) && ads.conversionComplete();
  }

  if (!ready) {
    if (elapsedUs < ADS_TIMEOUT_US) return;
    // Timed out. Ask the chip directly whether the conversion finished.
    if (ads.conversionComplete()) {
      if (adsState.useRdyPin && ++adsState.rdyMisses >= ADS_RDY_MISSES_TO_POLL) {
        adsState.useRdyPin = false;
        Serial.println("ADS1115 RDY (GPIO10) not asserting; switching to I2C polling.");
      }
    } else {
      adsState.busy = false;  // retry this channel
      if (++adsState.failures >= ADS_FAILS_TO_LOST) {
        adsState.ok = false;
        adsState.lastProbeMs = nowMs;
        Serial.println("ADS1115 not responding; using ESP32 ADC fallback.");
      }
      return;
    }
  } else if (adsState.useRdyPin) {
    adsState.rdyMisses = 0;
  }

  int16_t raw = ads.getLastConversionResults();
  adsState.busy = false;
  adsState.failures = 0;
  if (raw < 0) raw = 0;  // single-ended inputs: only tiny negative offsets
  AdsAccumulator &a = adsState.acc[adsState.channel];
  a.sum += raw;
  a.count++;
  adsState.channel = (adsState.channel + 1) % 4;
}

// Close the current averaging window: fold each channel's accumulator into
// lastMv (mV at the ADC pin). A channel with no conversions in this window
// keeps its previous mean.
static void closeAdsWindow() {
  for (int i = 0; i < 4; i++) {
    AdsAccumulator &a = adsState.acc[i];
    if (a.count > 0) {
      adsState.lastMv[i] = (float)a.sum / a.count * ADS_MV_PER_COUNT;
      adsState.haveMv[i] = true;
    }
    a = {0, 0};
  }
}

// Fallback: oversampled, eFuse-calibrated ESP32 ADC read, in mV at the pin.
static float readFallbackMv(uint8_t pin) {
  uint32_t acc = 0;
  for (uint8_t i = 0; i < FALLBACK_OVERSAMPLE; i++) acc += analogReadMilliVolts(pin);
  return (float)acc / FALLBACK_OVERSAMPLE;
}

static uint16_t clampU16(float v) {
  if (!(v > 0.0f)) return 0;  // also catches NaN
  if (v > 65535.0f) return 65535;
  return (uint16_t)lroundf(v);
}

// =================================================================================
// Button (BOOT, GPIO0): debounced; a press marks the next sample (flag bit5)
// =================================================================================
static bool buttonRaw = false;
static bool buttonStable = false;
static uint32_t buttonChangeMs = 0;
static bool markPending = false;

static void serviceButton(uint32_t nowMs) {
  bool down = (digitalRead(PIN_BOOT_BUTTON) == LOW);
  if (down != buttonRaw) {
    buttonRaw = down;
    buttonChangeMs = nowMs;
  } else if (down != buttonStable && nowMs - buttonChangeMs >= BUTTON_DEBOUNCE_MS) {
    buttonStable = down;
    if (down) markPending = true;
  }
}

// =================================================================================
// Status LED
// =================================================================================
static uint32_t ledLastUpdateMs = 0;
static uint32_t ledShown = 0xFFFFFFFF;  // force the first write
static bool identifyActive = false;
static uint32_t identifyStartMs = 0;

static void ledWrite(uint8_t r, uint8_t g, uint8_t b) {
  uint32_t c = ((uint32_t)r << 16) | ((uint32_t)g << 8) | b;
  if (c == ledShown) return;  // the RMT write is not free; skip repeats
  ledShown = c;
  // Standard WS2812B/SK6812: the core puts GRB on the wire from (r, g, b).
#if ESP_ARDUINO_VERSION_MAJOR >= 3
  rgbLedWrite(PIN_LED_DIN, r, g, b);
#else
  neopixelWrite(PIN_LED_DIN, r, g, b);
#endif
}

static uint8_t scaleApp(uint8_t v) {
  return (uint8_t)(((uint16_t)v * LED_APP_SCALE + 127) / 255);
}

static void serviceLed(uint32_t nowMs) {
  if (identifyRequested.exchange(false)) {
    identifyActive = true;
    identifyStartMs = nowMs;
  }
  if (nowMs - ledLastUpdateMs < LED_UPDATE_MS) return;
  ledLastUpdateMs = nowMs;

  if (identifyActive) {
    uint32_t step = (nowMs - identifyStartMs) / LED_IDENTIFY_STEP_MS;
    if (step < 2u * LED_IDENTIFY_BLINKS) {
      uint8_t v = (step % 2 == 0) ? LED_IDENTIFY_LEVEL : 0;
      ledWrite(v, v, v);
      return;
    }
    identifyActive = false;
  }

  if (!bleConnected.load()) {
    float phase = (float)(nowMs % LED_BREATHE_PERIOD_MS) / LED_BREATHE_PERIOD_MS;
    float k = 0.5f - 0.5f * cosf(2.0f * (float)M_PI * phase);
    ledWrite(0, 0, LED_BREATHE_MIN + (uint8_t)lroundf(k * (LED_BREATHE_MAX - LED_BREATHE_MIN)));
    return;
  }

  uint32_t app = appLedColour.load();
  if (app & 0x01000000UL) {
    ledWrite(scaleApp(app >> 16), scaleApp(app >> 8), scaleApp(app));
  } else {
    ledWrite(0, LED_CONNECTED_G, LED_CONNECTED_B);
  }
}

// =================================================================================
// BLE
// =================================================================================
static void startAdvertising() {
  NimBLEAdvertising *adv = NimBLEDevice::getAdvertising();
  if (!adv->isAdvertising()) adv->start();
}

static void refreshInfo() {
  char json[200];
  snprintf(json, sizeof(json),
           "{\"proto\":%u,\"fw\":\"%s\",\"board\":\"%s\",\"rl_ohm\":%lu,"
           "\"tap_ratio\":%.1f,\"vc_mv\":%u,\"interval_ms\":%u,\"heater_mv\":%u}",
           PROTO_VERSION, FW_VERSION, BOARD_ID, (unsigned long)RL_OHM, TAP_RATIO,
           VC_MV, sampleIntervalMs.load(), lastHeaterMv.load());
  infoChar->setValue(std::string(json));
}

class ServerCallbacks : public NimBLEServerCallbacks {
  void onConnect(NimBLEServer *server, NimBLEConnInfo &info) override {
    bleConnected = true;
    server->updateConnParams(info.getConnHandle(), CONN_MIN_INTERVAL, CONN_MAX_INTERVAL,
                             CONN_LATENCY, CONN_TIMEOUT);
  }
  void onDisconnect(NimBLEServer *server, NimBLEConnInfo &info, int reason) override {
    bleConnected = false;
    notifyEnabled = false;
    appLedColour = 0;  // the next client starts from dim cyan again
    startAdvertising();
  }
};

class SampleCallbacks : public NimBLECharacteristicCallbacks {
  void onSubscribe(NimBLECharacteristic *chr, NimBLEConnInfo &info,
                   uint16_t subValue) override {
    notifyEnabled = (subValue & 0x0001) != 0;  // bit0 of the CCCD = notifications
  }
};

class InfoCallbacks : public NimBLECharacteristicCallbacks {
  void onRead(NimBLECharacteristic *chr, NimBLEConnInfo &info) override {
    refreshInfo();  // runs before the value is sent, so heater_mv is current
  }
};
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
void loop() {
  uint32_t nowMs = millis();
  loopIterations++;
  rtcLastLoopMs = nowMs;
  rtcLastSeq = seq;

  // Bench diagnostic: when a USB host opens the port, say how long the loop
  // has already been running so a stall without a host is visible.
  static bool hostWasConnected = false;
  bool hostConnected = (bool)Serial;
  if (hostConnected && !hostWasConnected) {
    Serial.printf("USB host connected at %lu ms: setup done at %lu ms, %lu loop iterations, seq %u\n",
                  (unsigned long)nowMs, (unsigned long)setupDoneMs, (unsigned long)loopIterations,
                  seq);
  }
  hostWasConnected = hostConnected;

  serviceButton(nowMs);
  serviceAds(nowMs);
  serviceLed(nowMs);

  // Apply a newly shortened interval now rather than after the old deadline.
  if ((int32_t)(nextSampleMs - nowMs) > (int32_t)sampleIntervalMs.load()) {
    nextSampleMs = nowMs + sampleIntervalMs.load();
  }

  if ((int32_t)(nowMs - nextSampleMs) >= 0) {
    emitSample(nowMs);
    uint16_t interval = sampleIntervalMs.load();
    nextSampleMs += interval;
    // Fell behind, or the interval just shrank: resynchronise rather than burst.
    if ((int32_t)(nowMs - nextSampleMs) >= 0 || nextSampleMs - nowMs > interval) {
      nextSampleMs = nowMs + interval;
    }
  }

  delay(1);  // yield; a conversion takes ~4 ms, so 1 ms granularity is plenty
}

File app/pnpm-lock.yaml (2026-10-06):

lockfileVersion: '9.0'

settings:
  autoInstallPeers: true
  excludeLinksFromLockfile: false

importers:

  .:
    dependencies:
      '@expo-google-fonts/inter':
        specifier: ^0.4.2
        version: 0.4.2
      '@expo/vector-icons':
        specifier: ^15.1.1
        version: 15.1.1(expo-font@57.0.4(expo@57.0.23)(react-native@0.86.3(@babel/core@7.29.7)(@types/react@19.2.18)(react@19.2.3))(react@19.2.3))(react-native@0.86.3(@babel/core@7.29.7)(@types/react@19.2.18)(react@19.2.3))(react@19.2.3)
      '@react-native-async-storage/async-storage':
        specifier: 2.2.0
        version: 2.2.0(react-native@0.86.3(@babel/core@7.29.7)(@types/react@19.2.18)(react@19.2.3))
      '@shopify/restyle':
        specifier: ^2.4.5
        version: 2.4.5(react-native@0.86.3(@babel/core@7.29.7)(@types/react@19.2.18)(react@19.2.3))(react@19.2.3)
      expo:
        specifier: ~57.0.23
        version: 57.0.23(@babel/core@7.29.7)(@expo/dom-webview@57.0.1)(react-native@0.86.3(@babel/core@7.29.7)(@types/react@19.2.18)(react@19.2.3))(react@19.2.3)(typescript@6.0.3)
      expo-audio:
        specifier: ~57.0.5
        version: 57.0.5(expo-asset@57.0.17(expo@57.0.23)(react-native@0.86.3(@babel/core@7.29.7)(@types/react@19.2.18)(react@19.2.3))(react@19.2.3)(typescript@6.0.3))(expo@57.0.23)(react-native@0.86.3(@babel/core@7.29.7)(@types/react@19.2.18)(react@19.2.3))(react@19.2.3)
      expo-dev-client:
        specifier: ~57.0.19
        version: 57.0.19(expo@57.0.23)(react-native@0.86.3(@babel/core@7.29.7)(@types/react@19.2.18)(react@19.2.3))
      expo-document-picker:
        specifier: ~57.0.3
        version: 57.0.3(expo@57.0.23)
      expo-file-system:
        specifier: ~57.0.7
        version: 57.0.7(expo@57.0.23)(react-native@0.86.3(@babel/core@7.29.7)(@types/react@19.2.18)(react@19.2.3))
      expo-font:
        specifier: ~57.0.4
        version: 57.0.4(expo@57.0.23)(react-native@0.86.3(@babel/core@7.29.7)(@types/react@19.2.18)(react@19.2.3))(react@19.2.3)
      expo-keep-awake:
        specifier: ~57.0.2
        version: 57.0.2(expo@57.0.23)(react@19.2.3)
      expo-location:
        specifier: ~57.0.18
        version: 57.0.18(expo@57.0.23)(typescript@6.0.3)
      expo-sharing:
        specifier: ~57.0.20
        version: 57.0.20(expo@57.0.23)(react-native@0.86.3(@babel/core@7.29.7)(@types/react@19.2.18)(react@19.2.3))(react@19.2.3)(typescript@6.0.3)
      expo-status-bar:
        specifier: ~57.0.1
        version: 57.0.1(expo@57.0.23)(react-native@0.86.3(@babel/core@7.29.7)(@types/react@19.2.18)(react@19.2.3))(react@19.2.3)
      expo-system-ui:
        specifier: ~57.0.4
        version: 57.0.4(expo@57.0.23)(react-native@0.86.3(@babel/core@7.29.7)(@types/react@19.2.18)(react@19.2.3))
      react:
        specifier: 19.2.3
        version: 19.2.3
      react-native:
        specifier: 0.86.3
        version: 0.86.3(@babel/core@7.29.7)(@types/react@19.2.18)(react@19.2.3)
      react-native-ble-plx:
        specifier: ^3.5.1
        version: 3.5.1(react-native@0.86.3(@babel/core@7.29.7)(@types/react@19.2.18)(react@19.2.3))(react@19.2.3)
      react-native-safe-area-context:
        specifier: ~5.7.0
        version: 5.7.0(react-native@0.86.3(@babel/core@7.29.7)(@types/react@19.2.18)(react@19.2.3))(react@19.2.3)
      react-native-svg:
        specifier: 15.15.4
        version: 15.15.4(react-native@0.86.3(@babel/core@7.29.7)(@types/react@19.2.18)(react@19.2.3))(react@19.2.3)
    devDependencies:
      '@types/react':
        specifier: ~19.2.2
        version: 19.2.18
      typescript:
        specifier: ~6.0.3
        version: 6.0.3
      vitest:
        specifier: ^3.2.7
        version: 3.2.7(@types/node@26.6.1)(lightningcss@1.33.0)(terser@5.51.2)(yaml@2.9.1)
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

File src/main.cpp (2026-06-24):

// Dual gas sensor bring-up: ESP32-S3-Zero with both Figaro modules, the SSD1306
// OLED and the DFRobot Gravity GNSS (Quectel L76K) sharing the I2C bus. Proves
// the read paths and visualises the signal; the GNSS gives each sample a position
// so the log is a GPS-tagged survey,
// written to a microSD card as well as streamed over the USB serial port.
//
// It samples both modules' VOUT four times a second (every 250 ms) with
// oversampling and plots them on two side-by-side charts. Values are conditioned VOUT in millivolts; for
// reference, both modules read about 2.5 V at their factory alarm concentration.
// This is NOT a calibrated ppm curve, but it is monotonic: higher means more gas.
//
// LEFT chart - raw VOUT. Methane (CH4) is the solid filled area, LP gas (LPG)
// the line on top, and the CH4 adaptive baseline a dotted reference line, so the
// anomaly (rise above local background) shows as the gap above the dots. The
// vertical scale has a fixed lower bound (0) and a dynamic upper bound: the top
// tracks the largest value on screen plus headroom, but never zooms in tighter
// than a floor, so the trace expands for a real signal without blowing small
// noise up to full screen when things are quiet. Because the top is dynamic,
// dashed gridlines every GRID_STEP_MV (1 V) mark the scale; with the bottom fixed
// at 0, counting lines from the bottom reads the magnitude.
//
// RIGHT chart - a long-timebase overview of the CH4 channel: the last 10 minutes
// of VOUT decimated to the column width, one peak-per-column so a brief plume is
// not lost between pixels, with the current baseline drawn as a dotted reference.
// The left chart is the live detail -- its 62 columns span only ~16 s at 250 ms
// -- so the pair reads as detail + overview: the left shows what is happening
// now, the right shows where that sits against the last 10 minutes and catches
// plumes that have already scrolled off the live trace. The overview is on a
// fixed scale (0 to OVERVIEW_MAX_MV, the ~2.5 V factory-alarm level) so it reads
// as a stable absolute reference rather than rescaling, carries the same dashed
// gridlines as the live chart, and is labelled "10m". LPG is left off to keep the
// methane view clean; it could be overlaid the same way.
//
// The CSV (logged to microSD and streamed over USB) carries the raw voltages,
// baselines and deviations, the BME280 environment (temperature, humidity,
// pressure) and the GNSS position (UTC, lat/lon, altitude, satellites, fix) so
// each gas sample is both geotagged and tied to the conditions it was taken in.
// Humidity is the major uncorrected MOX confounder -- the Figaro modules
// compensate temperature internally but not humidity (see docs/sensors.md) -- so
// logging it lets a later reviewer reject anomalies that merely coincide with a
// humidity change.
//
// Sequence after power-on (or a BOOT-button press to re-zero):
//   WARMUP      - ignore readings while the sensor settles
//   BASELINING  - fill the background window before the baseline is trusted
//   RUNNING     - plot VOUT, with the baseline drawn as a dotted line. The
//                 baseline is a low percentile of a rolling VOUT window, so it
//                 tracks slow background drift yet is unmoved by brief positive
//                 plumes (a plume sits in the top of the window, above the
//                 percentile) and recovers on its own -- there is no gate or
//                 freeze state to drift out of sync or lock out.
// The warm-up and baseline windows here are deliberately short for bench
// iteration. Lengthen them for real use; the Figaro "initial action" alone wants
// minutes, not seconds.
//
// Hardware assumed:
//   - Waveshare ESP32-S3-Zero (ESP32-S3FH4R2), native USB CDC
//   - Figaro NGM2611-E13 methane module  -> read on GPIO1 (the CH4 channel)
//   - Figaro LPM2610-D09 LP gas module    -> read on GPIO2 (the LPG channel)
//   - SSD1306 128x64 OLED on I2C
//   - DFRobot Gravity GNSS (Quectel L76K) in I2C mode, sharing the OLED's bus
//   - BME280 temp/humidity/pressure sensor (I2C 0x76), sharing the same bus
//   - Fermion microSD card module (SPI) for on-board CSV logging
//   - BOOT button on GPIO0 used to re-zero the baseline
//   - Onboard WS2812 RGB LED on GPIO21 as a status lamp (no wiring needed): dim
//     blue while warming up/baselining, then green/amber/red for CH4 LOW/MED/HIGH
//
// Wiring (both modules share the 5V and GND rails):
//   - Module VIN  (pin 1) -> 5V rail
//   - Module VOUT (pin 2) -> its ADC pin, via a 10k/10k divider
//                            NGM2611 -> GPIO1, LPM2610 -> GPIO2
//   - Module VREF (pin 3) -> leave unconnected
//   - Module VH-  (pin 4) -> GND rail
//   - Module GND  (pin 5) -> GND rail
//   - OLED SDA -> GPIO6, OLED SCL -> GPIO7, OLED VCC -> 3V3, OLED GND -> GND
//   - GNSS SDA (D/T) -> GPIO6, SCL (C/R) -> GPIO7, + -> 3V3, - -> GND. Shares the
//     OLED's I2C bus; no address clash (OLED 0x3C, GNSS 0x20, BME280 0x76). The
//     bus runs at 100 kHz now that three devices share it.
//   - BME280 SDA -> GPIO6, SCL -> GPIO7, VCC -> 3V3, GND -> GND. Same shared I2C
//     bus, no extra GPIO. 6-pin boards: tie CSB -> 3V3 (I2C mode), SDO -> GND (0x76).
//   - microSD module (its own SPI bus): SCK -> GPIO12, MISO -> GPIO13,
//     MOSI -> GPIO11, CS -> GPIO10, VCC -> 3V3, GND -> GND
//   - Everything shares a common ground.
//
// VOLTAGE WARNING: each module's VOUT can reach ~4.95V, well above the
// ESP32-S3's 3.3V pin limit. Each VOUT must reach its ADC pin through a 10k/10k
// divider so the pin never sees more than ~2.5V. Keep VOUT_DIVIDER_RATIO at 2.0.

#include <Arduino.h>
#include <Wire.h>
#include <U8g2lib.h>
#include "DFRobot_GNSS.h"
#include <Adafruit_BME280.h>  // temp/humidity/pressure on the shared I2C bus
#include <SPI.h>
#include <SD.h>
#include <algorithm>  // std::nth_element for the percentile background

static const char *FW_VERSION = "0.24.0-bme280";

static const uint8_t PIN_I2C_SDA = 6;
static const uint8_t PIN_I2C_SCL = 7;
static const uint8_t PIN_BOOT_BUTTON = 0;
static const uint8_t PIN_STATUS_LED = 21;  // onboard WS2812 RGB LED (no wiring)
// microSD on its own SPI bus (the ESP32-S3 Arduino default SPI pins).
static const uint8_t PIN_SD_SCK = 12;
static const uint8_t PIN_SD_MISO = 13;
static const uint8_t PIN_SD_MOSI = 11;
static const uint8_t PIN_SD_CS = 10;
// 100 kHz: conservative for the I2C bus now shared by the OLED and the GNSS. The
// DFRobot GNSS library is happiest here, and the OLED still refreshes fast enough
// at the 5 Hz sample rate (a full frame is ~90 ms at 100 kHz).
static const uint32_t I2C_CLOCK_HZ = 100000;

static const float VOUT_DIVIDER_RATIO = 2.0f;
static const uint8_t OVERSAMPLE_COUNT = 64;
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

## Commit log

2026-06-24 Atmospheric methane detector — initial public release
    ESP32-S3 firmware for a GPS-tagged handheld methane survey instrument, the
    KiCad carrier-board design, and the Python analysis tools (survey videos + maps).
    [carrier_board.kicad_pcb, carrier_board.kicad_sch]
2026-09-17 Port the rev B companion app from Capacitor to Expo
    The phone app moves to Expo SDK 57 / React Native 0.86 so it can be built
    and shipped from an Expo account with EAS or `expo run:android`.
    src/core is unchanged: it was already pure and DOM-free, so the protocol
    parser, sensor maths, rolling windows, state machine, CSV writer and
    simulator carry over verbatim with their vitest suites. One module is new,
    core/base64.ts, because react-native-ble-plx passes characteristic values
    as base64.
    Service swaps:
    @capacitor-community/bluetooth-le -> react-native-ble-plx
    @capacitor/geolocation -> expo-location
    @capacitor/filesystem -> expo-file-system (write append:true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
2026-09-17 Install the Expo port's dependencies with pnpm and verify it
    npm install cannot complete this dependency tree on this machine: it creates
    the ~320 top-level directories under node_modules/, writes zero bytes and then
    hangs with the CPU idle. Reproduced on C: and D:, inside and outside the tool
    sandbox, from a clean cache. pnpm installs the same tree in ~20 s, so .npmrc
    pins node-linker=hoisted (Metro and the Expo config plugins resolve modules by
    walking node_modules, so pnpm's default symlinked layout breaks them) and
    pnpm-lock.yaml is now the lockfile.
    expo install pinned the SDK 57 versions of react-native-ble-plx, expo-location,
    expo-file-system, expo-sharing, expo-keep-awake, expo-dev-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
    [pnpm-lock.yaml]
2026-09-28 Add a USB serial bridge so Expo Go can show live readings
    Expo Go cannot load react-native-ble-plx, so a phone running the app in Go
    had no way to reach the board. tools/serial_bridge.py reads the board's USB
    serial CSV on a PC (rev B bench rows or rev A log rows), re-encodes each row
    as the protocol-v1 Sample packet and serves it over a WebSocket on the LAN,
    with a live read-out page for the bench. Pure stdlib plus pyserial.
    The app gains a BridgeDeviceLink (same bytes as BLE, auto-reconnect), a
    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
2026-09-28 serial_bridge: open the port without a DTR/RTS edge so the ESP32-S3 does not reset
    The USB-Serial-JTAG peripheral resets the chip on a DTR/RTS transition, so the
    port is now opened with both lines pre-set low. DTR is raised only if the board
    stays silent for 5 s, for firmware that gates output on a terminal being present.
    [serial_bridge.py]
2026-09-28 Rebuild the app layout on Shopify Restyle with a fixed spacing scale
    Every margin, padding and gap now comes from one named scale (4/8/12/16/24/32)
    via Restyle's Box/Text, and type styles are named variants, so the screens
    share one rhythm instead of per-file pixel values.
    Layout no longer moves as state changes: the top pills sit in one fixed-height
    row (the link pill ellipsises instead of wrapping), the stack of push-down
    banners is replaced by a single fixed-height status strip showing the most
    important message (or a quiet streaming line), and the state card has a fixed
    height with a reserved slot for the progress bar / LPG line.
    The "Sensor restarted: warming up again" toast is gone;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
    [pnpm-lock.yaml]
2026-09-28 Fix EAS install: move pnpm build-script approval to pnpm-workspace.yaml, pin pnpm
    The EAS builder's pnpm no longer reads package.json's "pnpm" key, so the
    esbuild script approval was ignored and strict mode failed the install
    (ERR_PNPM_IGNORED_BUILDS). packageManager pins the version used locally.
2026-09-28 Add phone board gerber files, drill file, and symbol library
    - Created new Gerber job file for the phone board design, including specifications for layers, materials, and design rules.
    - Added a drill file detailing the drill sizes and coordinates for the phone board.
    - Introduced a symbol library table for the phone board, linking to custom symbols.
    - Enhanced the plot_map.py script to support a new derivative mode for analyzing rate-of-change in signal data, including functions for calculating slopes and identifying spikes.
    [base.stl, bom.csv, case.scad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]
2026-09-28 Phone board rev C: compact the layout to 60 x 33 mm
    Same schematic, parts and block arrangement as the fabricated rev B, with the
    empty board area removed. The hand-routed blocks move as rigid units (MCU
    column and SHT40 tongue 2 mm up, power/USB column with the boost loop 2 mm
    left); only the free-form right third is re-packed: cans flush at the right
    edge, JST-PH under them exiting through the right edge, ADC and sensor
    networks in one column, RESET above BOOT, serial test pads as a labelled
    2 x 2 grid. Adds a GND via stub for the USB ESD diode, whose pour island had
    none. Re-routed with Freerouting: 0 DRC, 0 unconnected, 0 parity, ERC clean.
    Regenerated fab files, JLC placement and render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
    [case.scad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]
2026-09-28 Design pass: Inter, icon chips, hero card, data-scaled charts, tiles
    Typography is Inter (bundled via @expo-google-fonts/inter, loaded at start),
    on a single named type scale. The palette is retuned for depth (bg / surface /
    surface2), with the two chart hues re-validated for lightness, CVD separation
    and contrast on both the dark and light surfaces.
    Header: a link chip plus icon chips for battery and GPS (MaterialCommunity
    icons), fixed height, never wrapping. Status strip: icon + one line, quiet
    unless something needs saying. Hero state card with an eyebrow label. Both
    charts sit in cards with the legend in the title row; they now scale to the
    data (min..max widened to the classifier's ra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
    [pnpm-lock.yaml]
2026-09-28 Estimate ppm from the datasheet curves, with per-board Ro calibration
    core/ppm.ts inverts the Figaro power laws recorded in docs/sensors.md
    (TGS2611 Rs ∝ ppm^-0.47 referenced to 5000 ppm methane; TGS2610 Rs ∝
    ppm^-0.53 referenced to 1800 ppm iso-butane) after dividing Rs/Ro by the
    Table 1 temperature/humidity factor, bilinearly interpolated over the sparse
    datasheet grid. Ro defaults to the geometric mean of the specified part band
    and can be replaced per board from one reading in a known concentration
    (Settings: enter the ppm, tap Set Ro); stored in AsyncStorage keyed by the
    board name. Estimates are shown as two significant figures, with the curve's
    500..10,000 ppm range marked as "<50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
2026-09-28 Header battery chip: say USB whenever the board reports USB power
    The percentage was meaningless there (charger voltage, or a floating input on
    a board with no cell) and flickered between USB and 0 %.
2026-09-28 Phone board rev D draft: GM-402B MEMS sensors on a 2.8 V LDO
    Separate revision in hardware/phone_board_mems, derived from rev C. The two
    Figaro TO-5 cans become Winsen GM-402B MEMS sensors (LCSC C99754, JLC-placed)
    and the 5 V boost, inductor and feedback network become one ME6211C28 2.8 V
    LDO enabled by HTR_EN. Sensing loop from +3V3 into a 10k+10k load, heater
    monitor divider on the new rail. 55 x 31 mm: MCU column and SHT40 tongue from
    rev C (tongue shortened, neck re-routed), USB/charger column moved up, ADC in
    the boost's place, sensors as a right-hand column with the JST-PH under them.
    Locked GND stubs for pads the pours fenced off (C10, C12, U2 pin 8, C2).
    Freerouting: 0 DRC, 0 unconn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
    [bom.csv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]
2026-09-28 README: board revision table and current repository layout
2026-09-28 Phone board rev C: give the board a business end
    Sensors at the front: both Figaro cans overhang the right edge by ~1 mm with a
    7 mm notch milled between them, so each can stands in air on three sides.
    Power at the rear: USB-C on the bottom edge and the battery JST-PH on the top
    edge, both beside the ESP32 module and ~30 mm from the heaters, with the
    reverse-cell FET next to the JST. SHT40 tongue kept with a 2.5 mm neck and no
    copper pour on any layer over the tongue or neck; only its four tracks cross.
    Boost loop and ESP32 decoupling moved as rigid units; charger, ADC, buttons
    and test pads re-placed. Locked escapes for the boost EN pad and an In2 SDA
    trunk, plus GND stubs for pads the pour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
    [case.scad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]
2026-09-30 Add spike detection and plotting script for gas concentration estimates
    This commit introduces a new Python script, `plot_spike.py`, which visualizes gas concentration estimates (ppm) with and without temperature/humidity corrections. The script calculates the first time-derivative of the corrected estimate to identify spikes, which indicate the arrival of gas plumes. It supports input from firmware bench CSV logs or bridge watch logs and provides options for customizing the output, including gas type, Ro value, smoothing window, and spike threshold. The resulting plots are saved as PNG files.
    [case.scad, case_revb.scad, case_revb_v2.scad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]
2026-10-02 Refactor documentation and improve CSV handling in plotting scripts
    - Removed empty .gitkeep file from the lib directory.
    - Updated comments in plot_map.py and plot_survey.py to clarify the source of the CSV files, specifying that they are generated by the phone app and the rev A firmware.
    - Enhanced the GPS data filtering logic in plot_map.py to accommodate cases where the satellite count ('sats') is not provided by the phone app.
    - Clarified the source of the rev A CSV in serial_bridge.py to indicate the legacy path for better understanding.
    [base.stl, carrier_board.kicad_pcb, carrier_board.kicad_sch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]
2026-10-02 Update phone board README with sensor sourcing details and burn-in recommendations
2026-10-02 Remove sensor warm-up instructions from README for clarity
2026-10-06 feat: implement beep functionality for plume detection
    - Add beep tone generation in core/beep.ts, including WAV format creation.
    - Introduce beeper service in services/beeper.ts to handle audio playback.
    - Update chartData.ts to remove spike flags from ChartPoint interface.
    - Modify processor.ts to rename warmupMs to heaterWarmupMs for clarity.
    - Update settings.ts to reflect changes in processing settings and add beep option.
    - Refactor spike.ts to simplify spike detection logic and remove adaptive thresholding.
    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
    [case_revb_v2.scad, revb_v2_back.stl, revb_v2_front.stl]
2026-10-06 feat: add survey map and heatmap functionality to SurveysScreen
    - Integrated SurveyMap component into SurveysScreen for displaying live heatmap of recordings.
    - Added modal for fullscreen view of the heatmap.
    - Implemented heat mode toggle functionality.
    - Updated hints and instructions for user clarity.
    test: add unit tests for heatmap and mapView functionalities
    - Created comprehensive tests for heatmap calculations, including cell metrics, binning, and color scaling.
    - Added tests for mapView functions, ensuring correct coordinate transformations and view fitting.
    - Implemented tests for TrackBuffer to validate GPS tracking logic and point management.
    test: add routePaths tests for tra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
2026-10-06 feat: add survey CSV import and display functionality
    - Introduced `trackFromCsv` function to parse and load survey data from CSV files.
    - Enhanced `AppController` to manage showing and importing surveys, including state updates.
    - Updated `SurveysScreen` to allow users to open CSV files from external sources and display them on the map.
    - Added UI elements to indicate the currently displayed survey and provide options to switch back to live tracking.
    - Implemented tests for CSV parsing and survey loading to ensure robustness.
